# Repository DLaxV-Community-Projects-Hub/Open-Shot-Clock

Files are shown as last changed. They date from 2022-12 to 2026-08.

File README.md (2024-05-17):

theme

# Open Shot Clock

Open Shot Clock is an Open Source and DIY Project aiming to minimize the barriers of entry for shot-clock-aided sports like Boxlacrosse and Sixes and maximizing the pure sports experience to an affordable price.

## Details

- 10" super bright LED digits (in color of your choice)
- indoor and outdoor usage
    - impact and water resistant portable design
    - LED brightness adjustable to your needs
- wireless and cable connection
- 12V input supply (portable battery or mains operation by AC-DC power supply)
- handheld controller
- wifi connection to smartphone
    - control option
    - settings change
    - firmware updates
- external horn for each display
- tripod stands ~2 meter height
- tested under competition conditions

The price tag is around 1000€ for materials and accessories. Depending on which design and battery options you choose, it might cost more.

For more information have a look at our [wiki](https://github.com/DLaxV-Community-Projects-Hub/Open-Shot-Clock/wiki/Open-Shot-Clock-Wiki) or this [blog](https://devdrik.de/blog/) made by [@devdrik](https://github.com/devdrik).

## The Open Shot Clock in Action

To see the Open Shot Clock in action check out the following recordings of Lacrosse high lights in Germany:

- [Men´s European Box Lacrosse Championship 2022 - Final: England vs. Germany](https://sportdeutschland.tv/germanylacrosse/european-box-lacrosse-championship-final-england-vs-germany) (face off at 0:07:20)
- [Women´s German Indoor Championchip 2023 - Final: HLC Rot-Weiss München vs. HTHC Hamburg A](https://sportdeutschland.tv/germanylacrosse/deutsche-indoor-lacrosse-meisterschaft-2023-finale) (draw at 0:07:35)
- [Men´s German Box Lacrosse Championchip 2023- Final: SG Süd vs. SC Frankfurt 1880](https://sportdeutschland.tv/germanylacrosse/deutsche-box-lacrosse-meisterschaft-2023-finale) (face off at 0:10:15)
- [Women´s German Indoor Championchip 2022 - Final: HLC Rot-Weiss München vs. HTHC Hamburg A](https://sportdeutschland.tv/germanylacrosse/finale-lacrosse-damen-indoor-meisterschaft-2022) (draw at 0:09:20)
- [Men´s German Box Lacrosse Championchip 2022- Final: Spreewölfe Berlin vs. KKHT SW Köln](https://sportdeutschland.tv/germanylacrosse/deutsche-meisterschaften-box-lacrosse-2022-spreewoelfe-berlin-vs-kkht-sw-koeln) (starting at Part 2)

## What´s Included Here

- Design Documentation for Open Shot Clock Displays and Controller
    - CAD and PCB designs
    - 3d printing files
    - DIY Building Instructions Manual (german)
    - BOM for Displays, Controller and accessories (german)
    - User Manual (german)
    - Source Code to run Displays and Controller
- Project Wiki (work in progress)

## Usage

To build your own Open Shot Clock you can find all documents/information in the [documentation](documentation/) folder.

### Getting All the Parts Needed

Please go through the BOM to make sure you have all parts needed available. In the BOM we have included recommendation links, where we recently purchased the parts. Be aware that you can choose from different design features which you have to cover in your purchases. The developement is stil ongoing so some design features are not yet tested or even sufficiently developed.

In the design 3d printing is requried. Make sure you print the necessary parts before starting to build or let them print by a printing service. Make sure the parts are printed with a heat and impact resistant 3d printing material. You can find recommended materials in the BOM.

For the PCBs you can use the design files to order them at a PCB manufacturer like [PCBWay](https://www.pcbway.com/) or you can get in touch with us, there are still some prototyping PCBs left of the current version. In the near future the PCB design has to be adapted to the new Heltec Lora 32 version 3.0. For now the new version is supported through a workaround. For more information check this [blog artical](https://devdrik.de/open-shot-clock-hannover/) from [@devdrik](https://github.com/devdrik).

### List of Optional Design Features:

- Displays - 19 mm thick highly machined base plate or 8 mm thick easy to build base plate
  - 19 mm makes a more stable design and is tested well
  - 8 mm base plate is much easier to build with less special machinery, but it´s not tested yet (there might be clashes with electronic parts inside the case)

- Displays - Temperature Managment (up to now we don´t know if a temperature management is necessary, to find out we integrated a temp sensor socket on the display pcbs, tests are still in planning)

  - No Cooling
  - Fan grids on the back for passiv cooling (default)
  - Active Fan with fan grids on the back (fan can be installed behind one fan grid and operated by one mosfet output, this feature is not yet included in the sourc code)

- Displays - Batteries (you can find different battery options in the BOM from which you can choose)
- Accessories - you can find different accessory options in the BOM from which you can choose
- Displays - Type-Plate customization (for having your own type-plate text you can get in touch with us, we can change the text for you)
- to be continued

### Assembling

When you have all parts available please follow the DIY Building Instructions Manual for assembling your Open Shot Clocks. Some parts like the base-, front- and back-plates or the aliminium extursion profiles need to be modified before they can be assembled. You can do the needed modification by using the drawings of these parts or you can get in touch with us, there are still some back plates left in our stock. In this [youtube playlist](https://www.youtube.com/watch?v=pQqHoa6__Ms&list=PLql27Iz3RF6tFwROZiCufJEf_9jadfyL8) you can see videos of [@devdrik](https://github.com/devdrik) performing the assembing process of an Open Shot Clock. In the future the playlist will be extended to cover all parts of the assembling process.

#### Heltec WiFi LoRa V2/V3

The V2 module is hard to get at the moment, so we added support for the new V3 version of the module, that is easy to source. To use V3 with PCBs designed for V2, you need to rewire some connections. So make sure not to use a V3 on a V2 PCB without modification!

What to do to use a V3 on a Display PCB v0.2:
- Do not connect GPIO21 and GPIO48 of the V3 to the display PCB
- Connect GPIO38 to the display PCB where GPIO21 would be
- Connect GPIO39 to the display PCB where GPIO48 would be
- In [config.h](code/display/include/config.h) set ```DISPLAY_PCB_VERSION V0_2_HACK```

v3 Mod pins

What to do to use a V3 on a PCB for V2 (controller):
- Button BUTTON_PIN_B can not be used anymore
- Add pull-ups to all buttons (to be tested)

##### 5V Hack

Some Mosfet modules do not work with 3.3V on gate. To fix this on a v0.2 shotclock display PCB, we can disconnect the 3V3 pins from the of the heltec module and connect the corresponding pins on the display PCB to 5V of the heltec module.
This will bring all 3V3 on the display PCB to 5V, so be careful if you use a temperature sensor!

5V Mod pins

### How to Set Up the Firmware

You can find the source code for the controller and the displays in the code folder. Please just copy this repo to your VS Code with Plaformio extension and open both as projects. Fill in your preferred wifi credentials for setting up local device wifi networks to change settings. It is recommended to use different credentials for the controller and the displays to make sure you access the right devices settings.
Make sure to select the environment that fits the board you are using.

- flash controller
  - SPIFFS
  - source code
- flash displays
  - source code

## What´s Left to Do

- Tackle issues
- Build up Wiki with design insights, project history and roadmap
- Source code refactoring
- Design and test mdf display case as cost reduction opportunity
- pcb design to be ported to another open source platform and integration of heltc lora 32 v3.0 support
- Support first builders and gather feedback
- Offer english version of documents (if sufficiently demanded)
- to be continued

## How to Contribute

Feel free to customize your Open Shot Clock to your needs. For this purpose you can find the design files in the cad and pcb folders and the source code in the code folder. If you have ideas how to improve the Open Shot Clock and you need support for the integration or you want to share the benefits with the community please get in touch with us.

## Acknowledgement

Many thanks to [Ulf](https://github.com/ulf) for some initial inspiration in the approach to develop a LED shot clock. If you are looking out for a minimal and cheap setup for small indoor fields without obstacles have a look to [Ulf´s basketball shot clock tutotial](http://shotclock.de/)! With minor changes to the app it is possible to start with 30 seconds on the clock for lacrosse instead of 24 as for basketball. 

## Authors

- [@ChangeD20](https://github.com/ChangeD20)
- [@devdrik](https://github.com/devdrik)

## Contact

github@dlaxv.de

## License

[CERN OHL v2 Permissive](https://choosealicense.com/licenses/cern-ohl-p-2.0/)

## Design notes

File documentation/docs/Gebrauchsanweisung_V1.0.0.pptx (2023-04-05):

## Open Shot Clock

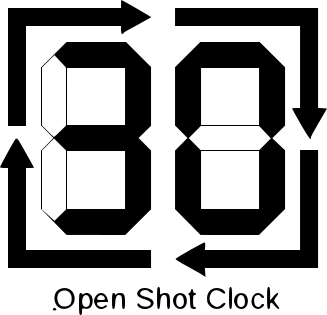
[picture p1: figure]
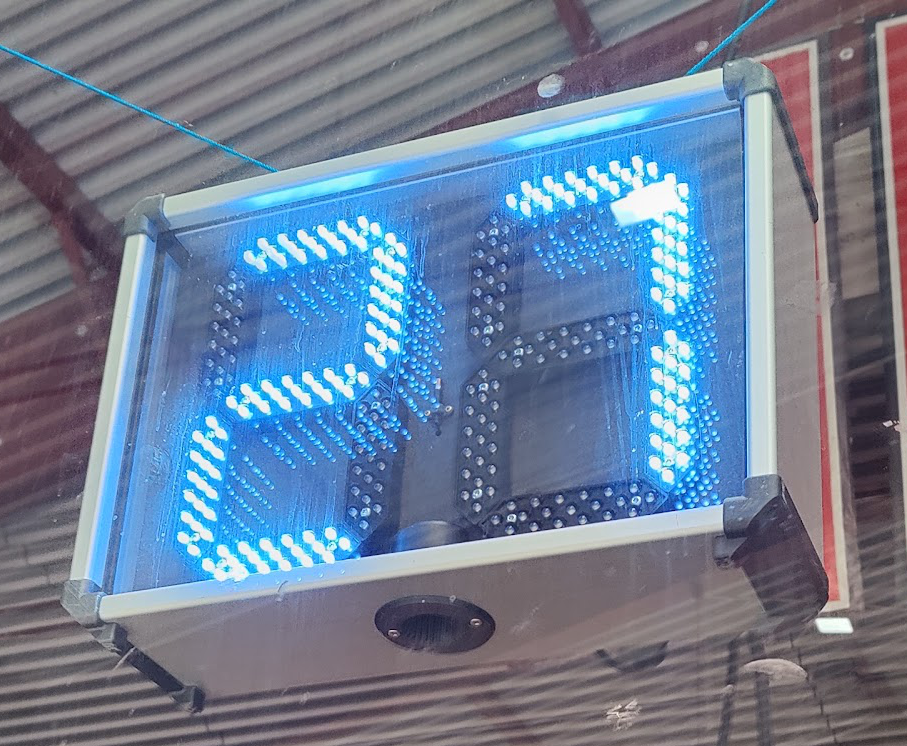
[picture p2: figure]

Gebrauchsanweisung

Haftungsausschluss:
Diese Anleitung beschreibt lediglich das Vorgehen, das wir (die Autoren) nach bestem Wissen und Gewissen wählen würden, um eine “Open Shot Clock” zu betreiben. Jegliche Haftung unsererseits ist ausgeschlossen. Der Bau und Betrieb einer “Open Shot Clock” oder einer abgeleiteten Version basiert immer auf eigenem Risiko und sollte von fachkundigen Personen durchgeführt werden.

## Inhalt

- Aufbau
  - Aufbau Displays
    - Stative oder Boden
    - Hinter Polycarbonat-Scheibe oder an Ballfangnetze
    - Anschluss Stromversorgung am Display
    - Akkus und Netzteil
    - Anschluss Horn am Display
  - Verbindungsübersichten
    - Funk Übersicht
    - Kabel Übersicht
    - Kabel Anschluss
- Bedienung Controller
- Einstellungen (tbd)

## Aufbau Displays - Stativ oder Boden

Auf Stativ oder auf dem Boden aufstellen
Stativ-Aufstell-Anweisungen beachten!!

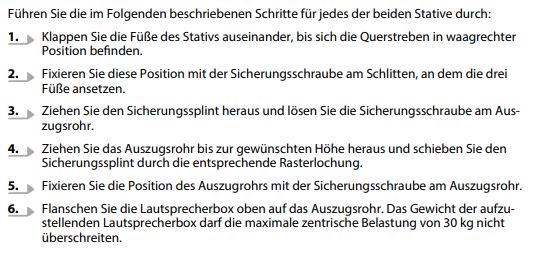
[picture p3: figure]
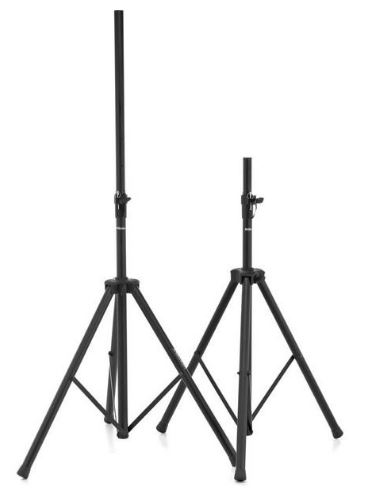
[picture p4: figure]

Bei starkem Wind keine Stative verwenden, Kippgefahr!!!

## Aufbau Displays - Hinter Polycarbonat-Scheibe oder an Ballfangnetz

Hinter Polycarbonat-Scheibe der Bande an den Streben aufhängen

Hinter Polycarbonat-Scheibe der Bande an der Scheibe mit Haken aufhängen

Vor oder hinter Ballfangnetz mit Haken aufhängen

Ösen für Haken/ Schnüre

Bei Montage über Durchgängen oder dem Spielfeld zusätzlich gegen Absturz sichern!!!

## Anschluss Stromversorgung am Display

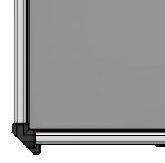
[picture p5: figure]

DATA IN

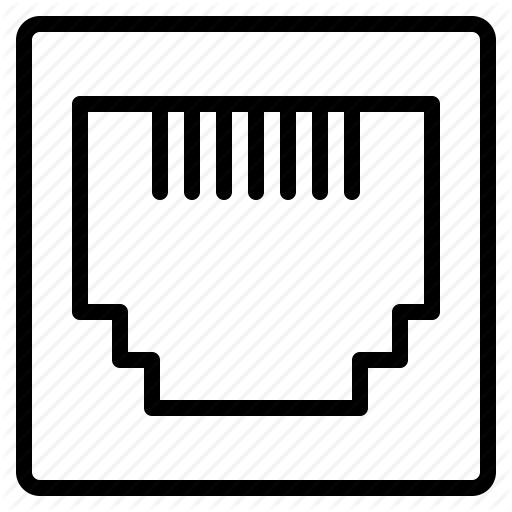
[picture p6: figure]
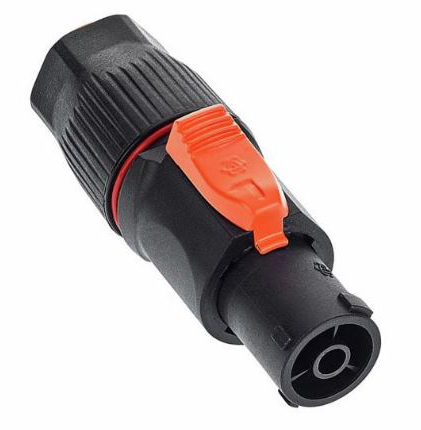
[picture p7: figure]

HORN OUT 12 V

DC IN 12V

Akku
oder
Netzteil

Display von Hinten

NUR 12V!!

## Akku - Fox Halo Power Pack 96k mAh

307,2 Wh

12V Ausgänge für Shot Clock Display

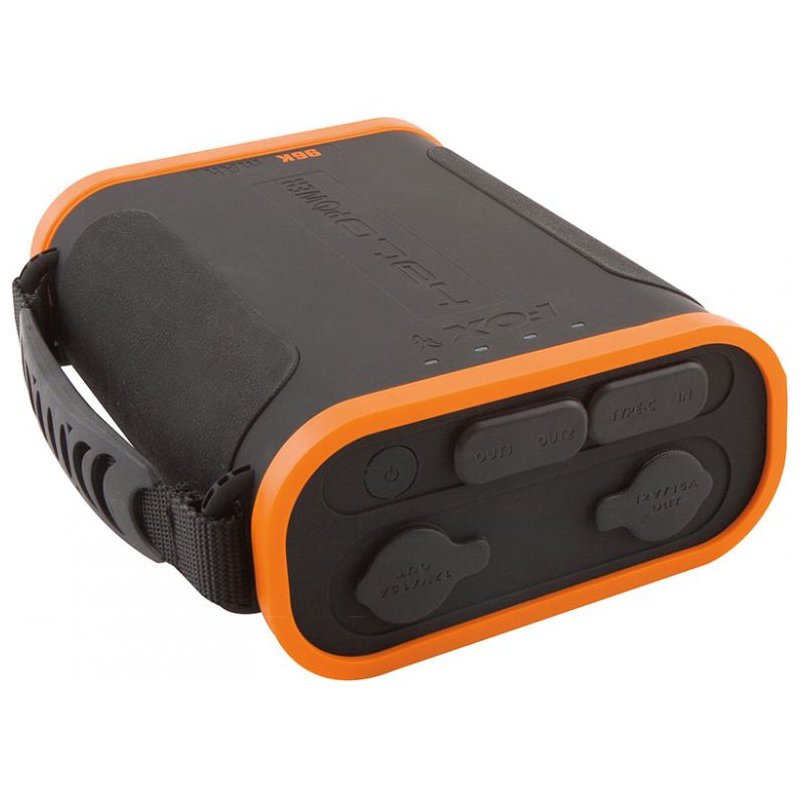
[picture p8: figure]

Akku laden

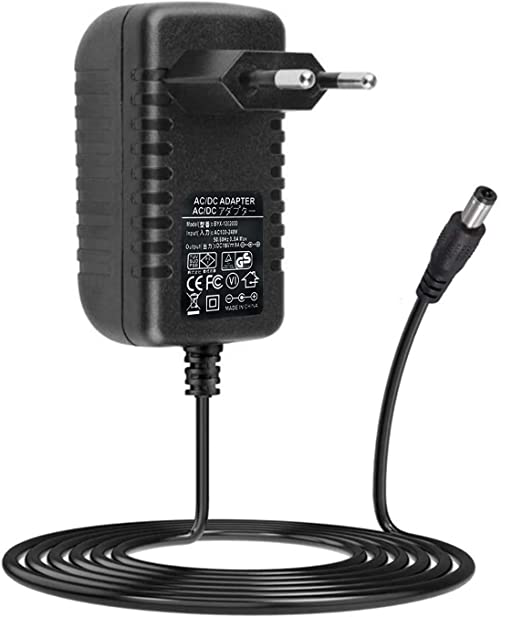
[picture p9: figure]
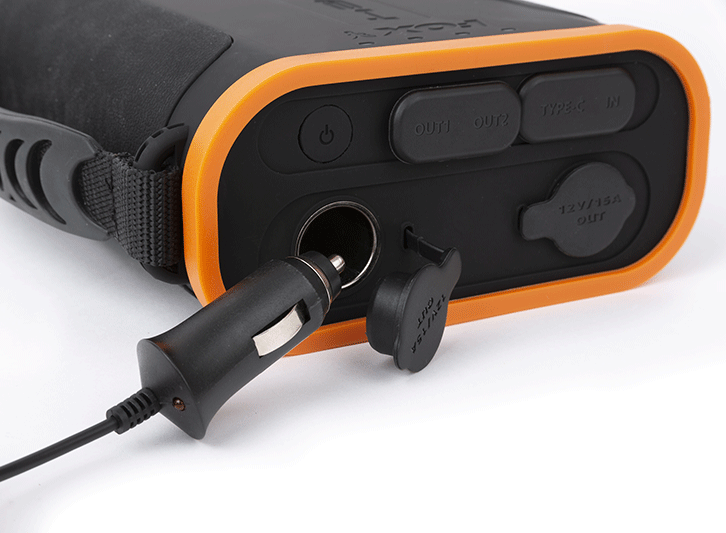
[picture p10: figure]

Bilder

VOR WASSER SCHÜTZEN!!!

KEIN PARALLELES LADEN!!!

Hier

vom Schließen der Tasche mit Kabel

## Akku - TotalCool TotalPower 144

144 Wh

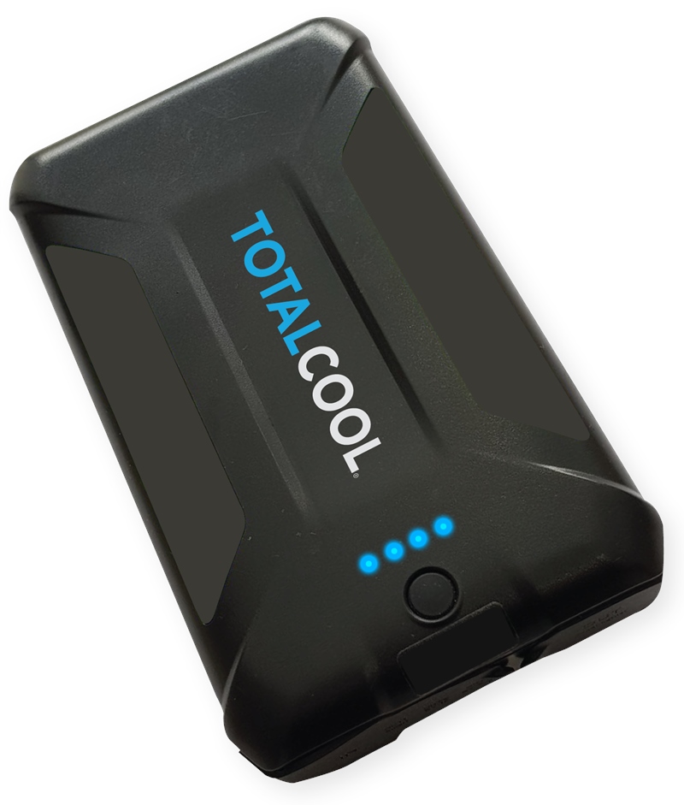
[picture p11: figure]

12V Ausgang für Shot Clock Display

Akku laden

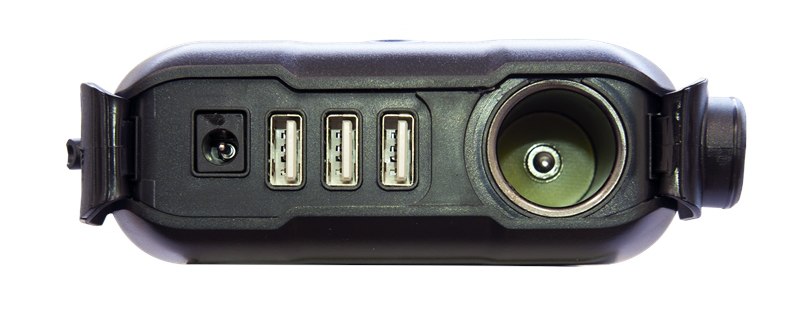
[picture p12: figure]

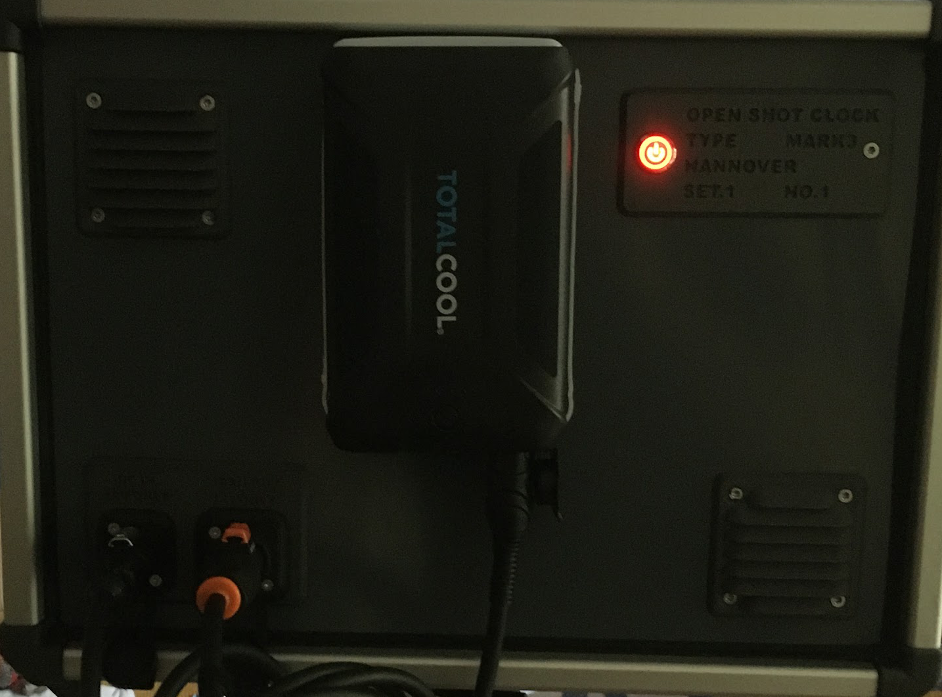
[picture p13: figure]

Gehäuse Wasserdicht, darum Akku mit Ein-/Ausgängen nach unten hinten an der Display Rückwand befestigen

KEIN PARALLELES LADEN UND NUTZEN!!!

## Netzteil 12V >5A

Netzstecker

Gefahr für Stromschlag durch Netzspannung
NUR INDOOR VERWENDEN!!

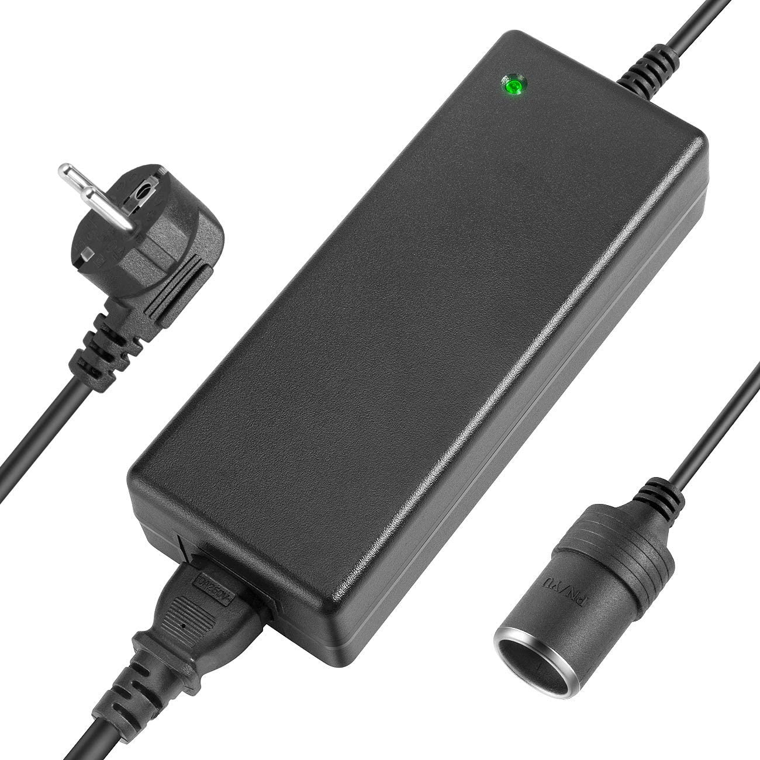
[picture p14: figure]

12V Ausgang für Shot Clock Display

## Anschluss Horn am Display

Horn Befestigung am Stativ

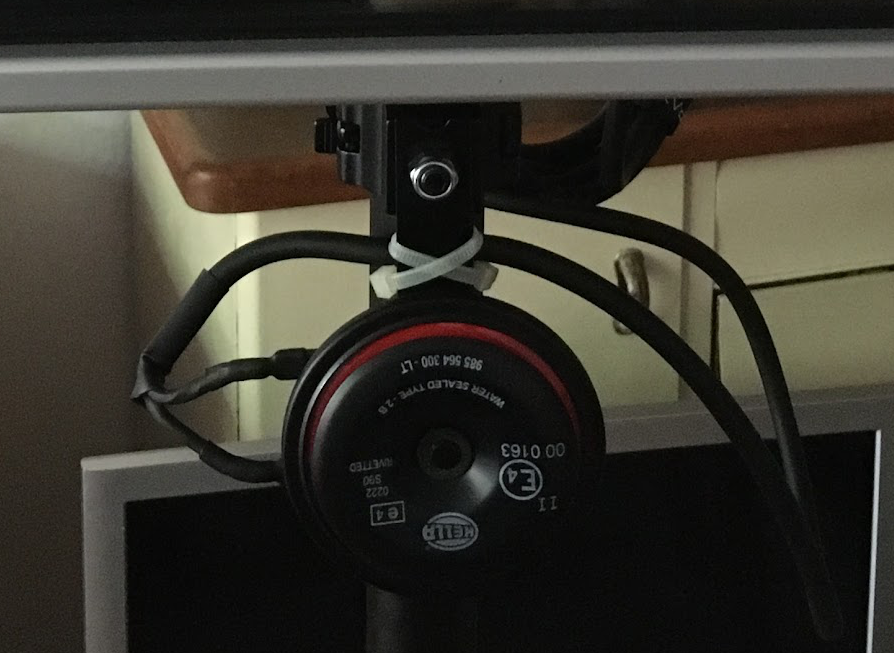
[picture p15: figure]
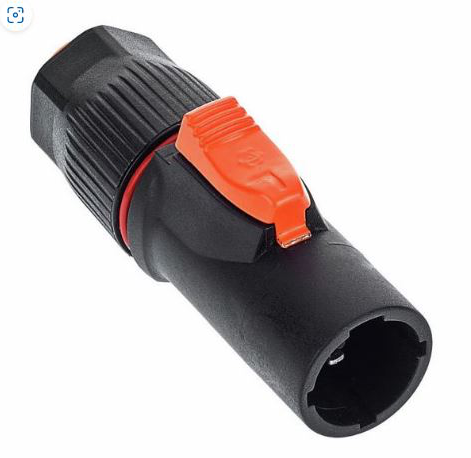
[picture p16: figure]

DATA IN

HORN OUT 12 V

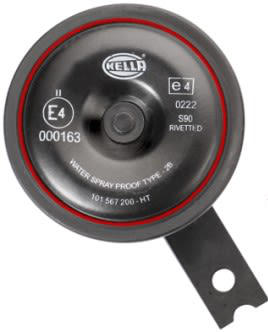
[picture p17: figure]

DC IN 12V

12V
Horn

Display von Hinten

## Aufbau - Funk Übersicht

Clock 1

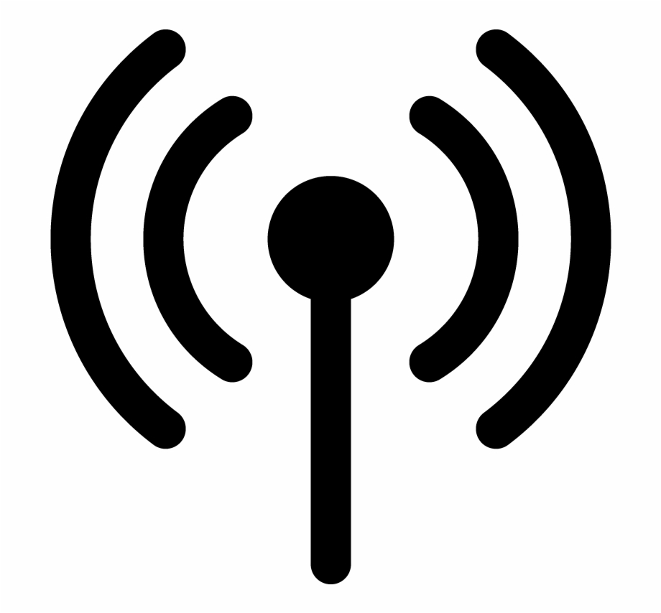
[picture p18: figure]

Clock 2

Clock 3

(optional, z.B. für Streaming)

Controller und alle Clocks müssen auf dem selben Kanal eingestellt sein (siehe Einstellungen)

Reichweite limitiert, Zuverlässigkeit eingeschränkt durch z.B. andere Funksender, Verbesserung des Empfangs durch:
Hindernisse vermeiden/Clocks über Kopfhöhe aufstellen

i

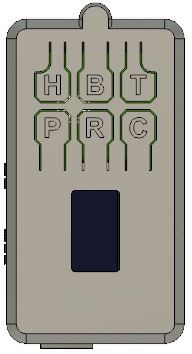
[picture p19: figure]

i

Controller

## Aufbau - Kabel - Übersicht

Clock 1

Clock 2

Clock 3

(optional, z.B. für Streaming)

Kabel-Verteilung

Den Controller niemals direkt an die Clocks anschließen, Kurzschlussgefahr!!!

Controller

## Aufbau - Kabel - Anschluss

Controller

Kabel-Verteilung

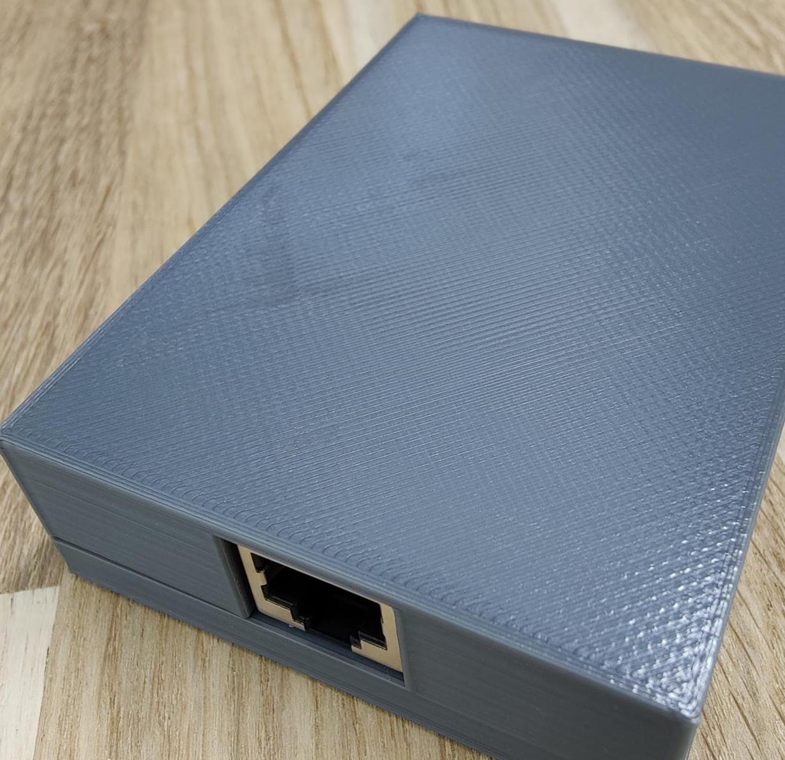
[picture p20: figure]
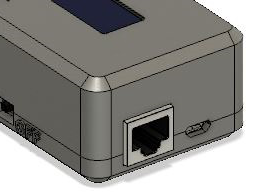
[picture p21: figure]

Anschluss mit Ethernet-Kabel

## Aufbau - Kabel - Anschluss

Kabel-Verteilung

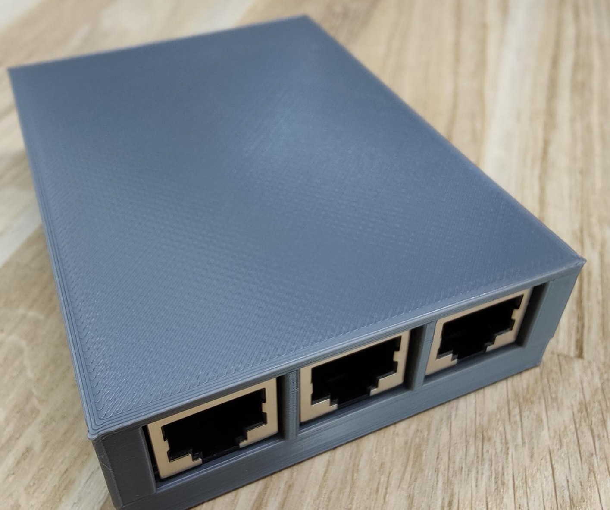
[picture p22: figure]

DATA IN

HORN OUT 12 V

1

Anschluss mit Ethernet-Kabel

2

3

DC IN 12V

Display von Hinten

## Bedienung Controller

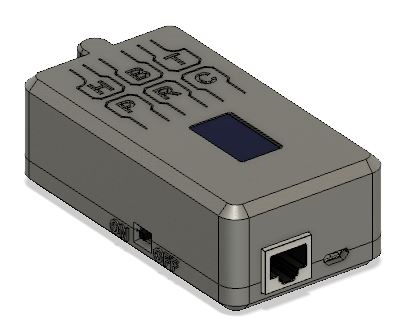
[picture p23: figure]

Kabel-Verbindung zum Verteiler

“T” Time Out
(autom. go back)

“B” Break
(Quarter / Halftime
- mehrfach drücken für Auswahl, autom. go back)

“H” Horn

Ein-/Aus-
schallter

Laden
5V Micro-USB

“C” Cancel
(Reset und Stop)

“R” Reset
(Reset und Start)

“P” Play/Pause

Controller Display

Parallels Laden des Controllers empfohlen bei voraussichtlich längerer Nutzung

i

## Einstellungen

TBD after refactoring of code

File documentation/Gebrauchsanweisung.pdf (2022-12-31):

Version 1.0

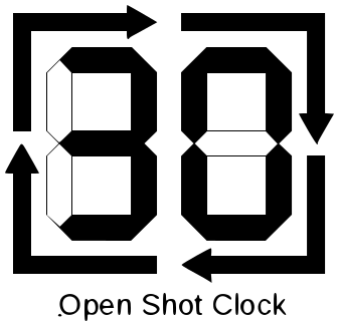
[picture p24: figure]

# Open Shot Clock

# Gebrauchsanweisung

Haftungsausschluss:
Diese Anleitung beschreibt lediglich das Vorgehen, das wir (die Autoren) nach bestem Wissen und Gewissen wählen würden, um eine “Open Shot Clock” zu betreiben. Jegliche Haftung unsererseits ist ausgeschlossen. Der Bau und Betrieb einer “Open Shot Clock” oder einer abgeleiteten Version basiert immer auf eigenem Risiko und sollte von fachkundigen Personen durchgeführt werden.

# Inhalt

## - Aufbau

- Aufbau Displays
■ | Stative oder Boden
■ | Hinter Polycarbonat-Scheibe oder an Ballfangnetze
■ | Anschluss Stromversorgung am Display
■ | Akkus und Netzteil
■ | Anschluss Horn am Display
- Verbindungsübersichten
■ | Funk Übersicht
■ | Kabel Übersicht
■ | Kabel Anschluss

## - Bedienung Controller - Einstellungen (tbd)

# Aufbau Displays - Stativ oder Boden


Auf Stativ oder auf dem Boden aufstellen

Stativ-Aufstell-Anweisungen beachten!!

Bei starkem Wind
keine Stative
verwenden,
Kippgefahr!!!

# Aufbau Displays - Hinter Polycarbonat-Scheibe oder an Ballfangnetz

Hinter Polycarbonat-Scheibe der Bande an den Streben aufhängen; Hinter Polycarbonat-Scheibe der Bande an der Scheibe mit Haken aufhängen; Vor oder hinter Ballfangnetz mit Haken aufhängen; Ösen für Haken/; Spielfeld zusätzlich gegen Absturz sichern!!!

Schnüre Bei Montage über Durchgängen oder dem

# Anschluss Stromversorgung am Display

HORN OUT 12 V; DATA IN; Akku; oder; NUR 12V!!; Netzteil

Display von Hinten

# Akku - Fox Halo Power Pack 96k mAh


Akku laden

12V Ausgänge für
Shot Clock Display

VOR WASSER SCHÜTZEN!!!; Hier; Bilder; KEIN PARALLELES LADEN!!!

vom
Schließen
der Tasche
mit Kabel

307,2 Wh


# Akku - TotalCool TotalPower 144 144 Wh


Akku laden

12V Ausgang für
Shot Clock Display

Gehäuse Wasserdicht, darum Akku mit Ein-/Ausgängen nach unten hinten an der Display Rückwand befestigen; KEIN PARALLELES LADEN UND NUTZEN!!!

# Netzteil 12V >5A

Gefahr für Stromschlag durch Netzspannung; NUR INDOOR VERWENDEN!!; Netzstecker; 12V Ausgang für Shot Clock Display

# Anschluss Horn am Display

HORN OUT 12 V; DATA IN; 12V Horn; Horn Befestigung am Stativ

Display von Hinten

Aufbau - Funk Übersicht; Clock 1; Clock 2; Clock 3; (optional, z.B. für Streaming); Controller; Reichweite limitiert, Zuverlässigkeit eingeschränkt durch z.B. andere Funksender, Verbesserung des Empfangs durch: Hindernisse vermeiden/Clocks über Kopfhöhe aufstellen; Controller und alle Clocks müssen auf dem selben Kanal eingestellt sein (siehe Einstellungen)

Aufbau - Kabel - Übersicht; Clock 1; Clock 2; Clock 3; (optional, z.B. für Streaming); Kabel-Verteilung; Controller; Den Controller niemals direkt an die Clocks anschließen, Kurzschlussgefahr!!!

# Aufbau - Kabel - Anschluss


Controller

Anschluss mit Ethernet-Kabel


Kabel-Verteilung

# Aufbau - Kabel - Anschluss

HORN OUT 12 V; DATA IN; Kabel-Verteilung

Anschluss mit Ethernet-Kabel

Display von Hinten

Bedienung Controller; Ein-/Aus- schallter; Laden 5V Micro-USB Kabel-Verbindung; zum Verteiler; Controller Display; “P” Play/Pause; “R” Reset (Reset und Start); “C” Cancel (Reset und Stop); “H” Horn; “B” Break (Quarter / Halftime - mehrfach drücken für Auswahl, autom. go back); “T” Time Out (autom. go back); Parallels Laden des Controllers empfohlen bei voraussichtlich längerer Nutzung

# Einstellungen

# TBD after refactoring of code

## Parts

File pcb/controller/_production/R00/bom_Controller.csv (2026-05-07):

# | Reference | Value | Qty | Footprint | Description | DNP
1 | BT1 | Battery_Cell | 1 | Battery:BatteryHolder_Keystone_1042_1x18650 | Single-cell battery
2 | C1,C2,C3,C4,C5,C6,C7,C8,C9,C10,C11,C12,C18,C22,C23,C26 | 100n | 16 | Capacitor_SMD:C_0402_1005Metric | Unpolarized capacitor
3 | C13,C16,C24 | 1u | 3 | Capacitor_SMD:C_0805_2012Metric | Unpolarized capacitor
4 | C14,C19 | 1u | 2 | Capacitor_SMD:C_0603_1608Metric | Unpolarized capacitor
5 | C15 | 2u2 | 1 | Capacitor_SMD:C_0603_1608Metric | Unpolarized capacitor
6 | C17,C21 | 100u | 2 | Capacitor_SMD:CP_Elec_8x10 | Polarized capacitor
7 | C20 | 1n | 1 | Capacitor_SMD:C_0402_1005Metric | Unpolarized capacitor
8 | C25,C27,C29,C30,C31 | 10u | 5 | Capacitor_SMD:C_0603_1608Metric | Unpolarized capacitor
9 | D1,D2,D5,D6,D9,D10,D11 | LED | 7 | LED_SMD:LED_0603_1608Metric | Light emitting diode
10 | D3,D4 | SMAJ24A | 2 | Diode_SMD:D_SMA | 400W unidirectional Transient Voltage Suppressor, 24.0Vr, SMA(DO-214AC)
11 | F1 | 2.6A | 1 | Fuse:Fuse_2920_7451Metric | Resettable fuse, polymeric positive temperature coefficient
12 | J1,J4 | Term 3.5mm | 2 | Connector_Phoenix_MC:PhoenixContact_MC_1,5_2-G-3.5_1x02_P3.50mm_Horizontal | Generic screw terminal, single row, 01x02, script generated (kicad-library-utils/schlib/autogen/connector/)
13 | J2,J3 | RJ45 | 2 | Connector_RJ:RJ45_Amphenol_RJHSE5380 | RJ connector, 8P8C (8 positions 8 connected)
14 | J5 | OLED 0.96" (I2C) | 1 | Connector_PinSocket_2.54mm:PinSocket_1x04_P2.54mm_Vertical | Generic connector, single row, 01x04, script generated (kicad-library-utils/schlib/autogen/connector/)
15 | J6,J7,J8,J9,J10,J11,J12,J13 | JST XH | 8 | Connector_Molex:Molex_PicoBlade_53048-0210_1x02_P1.25mm_Horizontal | Generic connector, single row, 01x02, script generated (kicad-library-utils/schlib/autogen/connector/)
16 | L1 | 10uH | 1 | Inductor_SMD:L_Bourns_SRP1050WA | Inductor
17 | L2,L3 | 2.2uH | 2 | Inductor_SMD:L_1008_2520Metric | Inductor
18 | P1,P2 | USB_C_Plug_USB2.0 | 2 | Connector_USB:USB_C_Receptacle_G-Switch_GT-USB-7010ASV | USB 2.0-only Type-C Plug connector
19 | Q1 | 20N06 | 1 | Package_SON:VSON-8_3.3x3.3mm_P0.65mm_NexFET | N-MOSFET transistor, source/gate/drain
20 | Q2 | SI2301 | 1 | Package_TO_SOT_SMD:SOT-23 | P-MOSFET transistor, gate/source/drain
21 | R1,R2,R4,R7,R17,R19,R26,R27,R29,R30,R41,R43,R44 | 1k | 13 | Resistor_SMD:R_0402_1005Metric | Resistor
22 | R5,R6 | 4k3 | 2 | Resistor_SMD:R_0402_1005Metric | Resistor
23 | R8,R20,R21,R32 | 200k | 4 | Resistor_SMD:R_0402_1005Metric | Resistor
24 | R9 | 120R | 1 | Resistor_SMD:R_0805_2012Metric | Resistor
25 | R10,R13,R28 | 0R | 3 | Resistor_SMD:R_0805_2012Metric | Resistor
26 | R11,R14,R15,R16,R33,R38,R40 | 10k | 7 | Resistor_SMD:R_0402_1005Metric | Resistor
27 | R12 | 2R2 | 1 | Resistor_SMD:R_0402_1005Metric | Resistor
28 | R18 | 82k | 1 | Resistor_SMD:R_0603_1608Metric | Resistor
29 | R22 | 4k3 | 1 | Resistor_SMD:R_0603_1608Metric | Resistor
30 | R23,R25 | 560R | 2 | Resistor_SMD:R_0402_1005Metric | Resistor
31 | R24,R34 | 0R | 2 | Resistor_SMD:R_0402_1005Metric | Resistor
32 | R31,R39 | 22k | 2 | Resistor_SMD:R_0402_1005Metric | Resistor
33 | R35 | 47k | 1 | Resistor_SMD:R_0402_1005Metric | Resistor
34 | R45,R46 | 470R | 2 | Resistor_SMD:R_0402_1005Metric | Resistor
35 | SW1,SW2,SW3,SW4,SW5,SW6,SW7 | SW_4x3mm | 7 | RVNSPRK_Switch:SW_Push_4x3mm | Push button switch, generic, two pins
36 | SW8 | SW_SPDT_312 | 1 | Button_Switch_THT:SW_CuK_OS102011MA1QN1_SPDT_Angled | Switch, single pole double throw
37 | TH1 | NTC | 1 | Resistor_SMD:R_0402_1005Metric | Temperature dependent resistor, negative temperature coefficient
38 | U*1 | BQ25606 | 1 | Package_DFN_QFN:VQFN-24-1EP_4x4mm_P0.5mm_EP2.5x2.5mm_ThermalVias | Standalone 1-Cell 3.0-A Buck Battery Charger VQFN-24
39 | U1 | ESP32-S3-MINI-1 | 1 | Espressif:ESP32-S3-MINI-1U | Smallsized module supporting 2.4 GHz WiFi (802.11 b/g/n) and Bluetooth ® 5 (LE) Built around ESP32S3 series of SoCs, Xtensa ® dualcore 32bit LX7 microprocessor Flash up to 8 MB, optional 2 MB PSRAM in chip package 39 GPIOs, rich set of peripherals Onboard PCB antenna or external antenna connector
40 | U2 | SP3485EN | 1 | Package_SO:SOIC-8_3.9x4.9mm_P1.27mm | Industrial 3.3V Low Power Half-Duplex RS-485 Transceiver 10Mbps, SOIC-8
41 | U3 | E220-400M22S | 1 | RVNSPRK_Modules:E220-400M22S
42 | U4 | SIC438BED-T1-GE3 | 1 | Package_DFN_QFN:Vishay_PowerPAK_MLP44-24L_ThermalVias | DC/DC Converter 24V 8A
43 | U5 | TPS259474x | 1 | RVNSPRK_Packages:RPW0010A_VQFN-HR-10 | 24V eFuse Protection Switch (VQFN-10)
44 | U6 | TPS629206 | 1 | Package_TO_SOT_SMD:SOT-583-8 | 3-V to 17-V, 0.6A, Low IQ Buck Converter with DCS-Control, SOT583-8

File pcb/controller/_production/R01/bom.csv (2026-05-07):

Designator | Footprint | Quantity | Value | LCSC Part #
BT401 | BatteryHolder_SMD_1x18650 | 1 | 18650 | C2988620
C101, C102, C201, C202, C203, C204, C205, C206, C207, C208, C209, C301, C401, C402, C408, C416, C417, C420, C426 | 0402 | 19 | 100n | C307331
C302, C419, C421, C422, C423, C424, C425 | 0603 | 7 | 10u | C19702
C403, C404, C418 | 0603 | 3 | 1u | C15849
C405 | 0402 | 1 | 10n | C15195
C406 | 0402 | 1 | 1n | C1523
C407, C414, C415 | CP_Elec_8x10 | 3 | 150u | C2898894
C409, C410, C413 | 1206 | 3 | 10u | C13585
C411 | 0402 | 1 | 1u | C52923
C412 | 0603 | 1 | 2u2 | C23630
D101, D102, D202, D402, D403, D406, D407, D408 | 0603 | 8 | LED | C2286
D201, D404, D405 | D_SOD-323 | 3 | 1N5819WS | C191023
D203 | D_SMA | 1 | SS54 | C22452
D401 | D_SMA | 1 | SMAJ24CA | C20883150
H101, H102, H103, H104 | MountingHole_3.2mm_M3 | 4 | M3
J102, J210 | PhoenixContact_MC_1,5_2-G-3.5_1x02_P3.50mm_Horizontal | 2 | Term 3.5mm | C409115
J103, J104 | RJ45_Amphenol_RJHSE5380 | 2 | RJ45 | C19078599
J201 | PinSocket_1x04_P2.54mm_Vertical_SMD_Pin1Left | 1 | OLED 0.96" (I2C) | C20071191
J202, J203, J204, J205, J206, J207, J208, J209 | Molex_PicoBlade_53048-0210_1x02_P1.25mm_Horizontal | 8 | Picoblade | C2845535
L401 | L_Bourns_SRP1050WA | 1 | 6.8uH | C32712978
L402 | L_Changjiang_FNR4030S | 1 | 100uH | C7588681
L403 | 1008 | 1 | 2.2uH | C964122
P101 | USB_C_Receptacle_G-Switch_GT-USB-7010ASV | 1 | USB_C_Plug_USB2.0 | C2927039
Q201 | SOT-23 | 1 | SI2301 | C10487
Q202, Q401 | VSON-8_3.3x3.3mm_P0.65mm_NexFET | 2 | DOZ35N06 | C36499167
Q402, Q403, Q404 | SOT-23 | 3 | 2N7002 | C8545
R102, R103, R104, R107, R202, R410, R420, R421, R429, R439, R440, R446 | 0402 | 12 | 1k
R105, R106, R416, R419, R448 | 0402 | 5 | 4k3
R108, R436, R437, R445, R447 | 0402 | 5 | 10k
R201, R203, R205, R403, R404, R406, R407, R425, R444 | 0402 | 9 | 20k
R204, R413, R441, R442 | 0402 | 4 | 560R
R301 | 0805 | 1 | 120R
R402, R408 | 1206 | 2 | 0R
R405 | 0402 | 1 | 2R2
R409, R414, R415 | 0402 | 3 | 2k
R411 | 0402 | 1 | 82k
R412, R432, R449 | 0402 | 3 | 0R
R417, R418, R428, R430 | 0402 | 4 | 200k
R423, R424, R435 | 0603 | 3 | 0R
R427, R431 | 0402 | 2 | 130k
R433 | 0402 | 1 | 51k
R434 | 0402 | 1 | 13k
SW101, SW102, SW201, SW202, SW203, SW204, SW205, SW206, SW207, SW208 | SW_Push_4x3mm | 10 | SW_4x3mm | C18078117
SW401 | SW_CuK_OS102011MA1QN1_SPDT_Angled | 1 | SW_SPDT_312 | C431548
U101 | ESP32-S3-MINI-1U | 1 | ESP32-S3-MINI-1 | C2980299
U201 | SOIC-8_3.9x4.9mm_P1.27mm | 1 | LM358 | C7950
U301 | SOIC-8_3.9x4.9mm_P1.27mm | 1 | SP3485EN-L/TR | C8963
U302 | E220-400M22S | 1 | E220-400M22S | C2971737
U401 | Vishay_PowerPAK_MLP44-24L_ThermalVias | 1 | SIC438BED-T1-GE3 | C511430
U402 | RPW0010A_VQFN-HR-10 | 1 | TPS259474ARPW | C3662807
U403 | SOT-23-6 | 1 | LM74700 | C2941042
U404 | Texas_S-PVSON-N10_ThermalVias | 1 | LM5166DRCR | C481392
U405 | VQFN-24-1EP_4x4mm_P0.5mm_EP2.5x2.5mm_ThermalVias | 1 | BQ25616 | C2866447

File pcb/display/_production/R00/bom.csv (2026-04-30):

# | Reference | Value | Qty | Footprint | Description | DNP
1 | C1,C2,C3,C4,C6,C7,C8,C9,C12,C21,C26,C27 | 100n | 12 | Capacitor_SMD:C_0603_1608Metric | Unpolarized capacitor
2 | C13,C17 | 1u | 2 | Capacitor_SMD:C_0603_1608Metric | Unpolarized capacitor
3 | C14 | 1n | 1 | Capacitor_SMD:C_0603_1608Metric | Unpolarized capacitor
4 | C15,C20 | 100u | 2 | Capacitor_SMD:CP_Elec_8x10 | Polarized capacitor
5 | C16,C19,C22,C24 | 1u | 4 | Capacitor_SMD:C_0805_2012Metric | Unpolarized capacitor
6 | C18 | 2u2 | 1 | Capacitor_SMD:C_0603_1608Metric | Unpolarized capacitor
7 | C23,C25 | 10u | 2 | Capacitor_SMD:C_0805_2012Metric | Unpolarized capacitor
8 | D1,D2,D17 | SMAJ24A | 3 | Diode_SMD:D_SMA | 400W unidirectional Transient Voltage Suppressor, 24.0Vr, SMA(DO-214AC)
9 | D3,D4,D5,D6,D7,D8,D9,D10,D11,D12,D13,D14,D15,D16,D20,D21,D22,D23,D24,D25 | LED | 20 | LED_SMD:LED_0603_1608Metric | Light emitting diode
10 | D18,D19 | B5819W | 2 | Diode_SMD:D_SOD-123 | Schottky diode
11 | F1 | 2.6A | 1 | Fuse:Fuse_2920_7451Metric | Resettable fuse, polymeric positive temperature coefficient
12 | J1 | Screw Terminal 3.5mm | 1 | Connector_Phoenix_MC:PhoenixContact_MC_1,5_6-G-3.5_1x06_P3.50mm_Horizontal | Generic screw terminal, single row, 01x06, script generated (kicad-library-utils/schlib/autogen/connector/)
13 | J2 | RJ45 | 1 | Connector_RJ:RJ45_Amphenol_54602-x08_Horizontal | RJ connector, 8P8C (8 positions 8 connected)
14 | J4 | 01x08_Pin | 1 | Connector_PinHeader_2.54mm:PinHeader_1x08_P2.54mm_Vertical | Generic connector, single row, 01x08, script generated
15 | J5,J6 | Term 3.5mm | 2 | Connector_Phoenix_MC:PhoenixContact_MC_1,5_2-G-3.5_1x02_P3.50mm_Horizontal | Generic screw terminal, single row, 01x02, script generated (kicad-library-utils/schlib/autogen/connector/)
16 | J7,J8,J9,J10,J11,J12,J13,J14,J15,J16,J17,J18,J19,J20 | XH 2P | 14 | Connector_JST:JST_XH_B2B-XH-A_1x02_P2.50mm_Vertical | Generic connector, single row, 01x02, script generated (kicad-library-utils/schlib/autogen/connector/)
17 | L3 | 10uH | 1 | Inductor_SMD:L_Bourns_SRR1260 | Inductor
18 | L4 | 12uH | 1 | Inductor_SMD:L_Changjiang_FNR6045S | Inductor
19 | P1 | USB_C_Plug_USB2.0 | 1 | Connector_USB:USB_C_Receptacle_G-Switch_GT-USB-7010ASV | USB 2.0-only Type-C Plug connector
20 | Q1,Q2,Q3,Q4,Q5,Q6,Q7,Q8,Q9,Q10,Q11,Q12,Q13,Q14,Q15,Q16 | 20N06 | 16 | Package_SON:VSON-8_3.3x3.3mm_P0.65mm_NexFET | N-MOSFET transistor, source/gate/drain
21 | R1,R2,R7,R15,R17,R22,R26,R27,R35,R43 | 1k | 10 | Resistor_SMD:R_0603_1608Metric | Resistor
22 | R3,R36,R40 | 0R | 3 | Resistor_SMD:R_0805_2012Metric | Resistor
23 | R4 | 120R | 1 | Resistor_SMD:R_0805_2012Metric | Resistor
24 | R5,R24,R45 | 0R | 3 | Resistor_SMD:R_0603_1608Metric | Resistor
25 | R8,R9,R48,R49 | 0R | 4 | Resistor_SMD:R_0402_1005Metric | Resistor
26 | R10,R30,R46,R47 | 4k3 | 4 | Resistor_SMD:R_0603_1608Metric | Resistor
27 | R18,R19,R20,R21,R32,R34,R42 | 10k | 7 | Resistor_SMD:R_0603_1608Metric | Resistor
28 | R23 | 82k | 1 | Resistor_SMD:R_0603_1608Metric | Resistor
29 | R25,R39 | 560R | 2 | Resistor_SMD:R_0603_1608Metric | Resistor
30 | R28,R29 | 200k | 2 | Resistor_SMD:R_0603_1608Metric | Resistor
31 | R31,R33,R41 | 22k | 3 | Resistor_SMD:R_0603_1608Metric | Resistor
32 | R38 | 2R2 | 1 | Resistor_SMD:R_0603_1608Metric | Resistor
33 | RN9,RN10,RN11,RN12 | 3k3 | 4 | Resistor_SMD:R_Array_Convex_4x0603 | 4 resistor network, parallel topology
34 | SW1,SW2,SW3,SW4 | SW_4x3mm | 4 | RVNSPRK_Switch:SW_Push_4x3mm | Push button switch, generic, two pins
35 | U1 | TMP1075DSG | 1 | Package_SON:WSON-8-1EP_2x2mm_P0.5mm_EP0.9x1.6mm | I2C-bus digital temperature sensor and thermal watchdog, WSON-8
36 | U2 | ESP32-S3-MINI-1 | 1 | Espressif:ESP32-S3-MINI-1U | Smallsized module supporting 2.4 GHz WiFi (802.11 b/g/n) and Bluetooth ® 5 (LE) Built around ESP32S3 series of SoCs, Xtensa ® dualcore 32bit LX7 microprocessor Flash up to 8 MB, optional 2 MB PSRAM in chip package 39 GPIOs, rich set of peripherals Onboard PCB antenna or external antenna connector
37 | U4 | PCA9685BS | 1 | Package_DFN_QFN:QFN-28-1EP_6x6mm_P0.65mm_EP4.25x4.25mm | 16-channel 12-bit PWM Fm+ I2C-bus LED controller RGBA QFN
38 | U5 | SP3485EN | 1 | Package_SO:SOIC-8_3.9x4.9mm_P1.27mm | Industrial 3.3V Low Power Half-Duplex RS-485 Transceiver 10Mbps, SOIC-8
39 | U6 | AP2210 | 1 | Package_TO_SOT_SMD:SOT-23-3
40 | U8 | E220-400M22S | 1 | RVNSPRK_Modules:E220-400M22S
41 | U9 | SIC438BED-T1-GE3 | 1 | Package_DFN_QFN:Vishay_PowerPAK_MLP44-24L_ThermalVias | DC/DC Converter 24V 8A
42 | U10 | TPS259474x | 1 | RVNSPRK_Packages:RPW0010A_VQFN-HR-10 | 24V eFuse Protection Switch (VQFN-10)
43 | U11 | LV3842 | 1 | Package_TO_SOT_SMD:SOT-23-6 | DC/DC Converter 36V 0.6A

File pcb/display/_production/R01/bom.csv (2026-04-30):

Designator | Footprint | Quantity | Value | LCSC Part #
C101, C102, C103, C104, C105, C201, C301, C601, C613, C614, C617, C620, C621 | 0402 | 13 | 100n
C602, C603, C606, C615, C618 | 1206 | 5 | 10u
C604, C609, C622, C623 | 0603 | 4 | 1u
C605 | 0603 | 1 | 2u2
C607, C608, C612 | CP_Elec_8x10 | 3 | 150u
C610 | 0402 | 1 | 10n
C611 | 0402 | 1 | 1n
C616, C619 | 0603 | 2 | 10u
D101, D102, D201, D203, D401, D402, D403, D404, D405, D406, D407, D501, D502, D503, D504, D505, D506, D507, D605, D606, D607, D608 | 0603 | 22 | LED
D202, D204 | D_SMA | 2 | SS54
D601, D602 | D_SOD-323 | 2 | 1N5819WS
D603, D604 | D_SMA | 2 | SMAJ24CA
J101 | RJ45_Amphenol_RJHSE5380 | 1 | RJ45
J102 | PhoenixContact_MC_1,5_6-G-3.5_1x06_P3.50mm_Horizontal | 1 | Screw Terminal 3.5mm
J103 | PinHeader_1x08_P2.54mm_Vertical | 1 | 01x08_Pin
J201, J202 | PhoenixContact_MC_1,5_2-G-3.5_1x02_P3.50mm_Horizontal | 2 | Term 3.5mm
J401, J402, J403, J404, J405, J406, J407, J501, J502, J503, J504, J505, J506, J507 | JST_XH_B2B-XH-A_1x02_P2.50mm_Vertical | 14 | XH 2P
L601 | L_Bourns_SRP1050WA | 1 | 6.8uH
L602, L603 | L_Changjiang_FNR4030S | 2 | 33uH
P101 | USB_C_Receptacle_G-Switch_GT-USB-7010ASV | 1 | USB_C_Plug_USB2.0
Q101 | SOT-23 | 1 | 2N7002
Q201, Q202, Q401, Q402, Q403, Q404, Q405, Q406, Q407, Q501, Q502, Q503, Q504, Q505, Q506, Q507, Q601, Q602 | VSON-8_3.3x3.3mm_P0.65mm_NexFET | 18 | DOZ35N06
R101, R102, R104, R105, R106, R109, R609, R610, R618, R619, R629 | 0402 | 11 | 1k8
R107, R108, R203, R204, R401, R402, R403, R404, R405, R406, R407, R501, R502, R503, R504, R505, R506, R507, R612, R615, R628 | 0402 | 21 | 4k3
R110, R603, R604, R606, R607, R622, R626 | 0402 | 7 | 18k
R202, R602, R608 | 1206 | 3 | 0R
R301 | 0805 | 1 | 120R
R302, R620, R623 | 0603 | 3 | 0R
R605 | 0402 | 1 | 2R2
R611, R621, R624 | 0402 | 3 | 82k
R613, R614 | 0402 | 2 | 200k
R616 | 0402 | 1 | 0R
R617 | 0402 | 1 | 680R
R625, R627 | 0402 | 2 | 11k
SW101, SW102, SW103, SW104 | SW_Push_4x3mm | 4 | SW_4x3mm
U101 | WSON-8-1EP_2x2mm_P0.5mm_EP0.9x1.6mm | 1 | TMP1075DSGR
U102 | ESP32-S3-MINI-1U | 1 | ESP32-S3-MINI-1U-N8
U201 | QFN-28-1EP_6x6mm_P0.65mm_EP4.25x4.25mm | 1 | PCA9685BS
U301 | SOIC-8_3.9x4.9mm_P1.27mm | 1 | SP3485EN-L/TR
U302 | E220-400M22S | 1 | E220-400M22S
U601 | Vishay_PowerPAK_MLP44-24L_ThermalVias | 1 | SIC438BED-T1-GE3
U602 | RPW0010A_VQFN-HR-10 | 1 | TPS259474ARPWR
U603, U604 | SOT-23-6 | 2 | TPS54202DDC
U605, U606 | SOT-23-6 | 2 | LM74700

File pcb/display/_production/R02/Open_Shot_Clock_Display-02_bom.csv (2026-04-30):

Designator | Footprint | Quantity | Value | LCSC Part #
C1, C616, C619 | 0603 | 3 | 10u | C19702
C101, C102, C103, C105, C107, C108, C109, C113, C201, C301, C601, C613, C614, C617, C620, C621 | 0402 | 16 | 100n | C307331
C104, C106, C110, C4, C5 | 0402 | 5 | 1u | C52923
C111, C112 | 0402 | 2 | 1.8pF | C5186870
C2, C3 | 0402 | 2 | 12p | C76948
C602, C603, C606, C615, C618 | 1206 | 5 | 10u | C13585
C604, C609, C622, C623 | 0603 | 4 | 1u | C15849
C605 | 0603 | 1 | 2u2 | C23630
C607, C608, C612 | CP_Elec_8x10 | 3 | 220u | C5246542
C610 | 0402 | 1 | 10n | C15195
C611 | 0402 | 1 | 1n | C1523
D101, D102, D201, D203, D401, D402, D403, D404, D405, D406, D407, D501, D502, D503, D504, D505, D506, D507, D605, D606, D607, D608 | 0603 | 22 | LED | C2286
D202, D204 | D_SMA | 2 | SS54 | C22452
D601, D602 | D_SOD-323 | 2 | 1N5819WS | C191023
D603, D604 | D_SMA | 2 | SMAJ24CA | C20883150
FB1 | 0603 | 1 | 100R | C14709
J1, J401, J402, J403, J404, J405, J406, J407, J501, J502, J503, J504, J505, J506, J507 | JST_XH_B2B-XH-A_1x02_P2.50mm_Vertical | 15 | XH 2P | C158012
J101 | RJ45_Amphenol_RJHSE5380 | 1 | RJ45 | C19078599
J102 | PhoenixContact_MC_1,5_6-G-3.5_1x06_P3.50mm_Horizontal | 1 | Screw Terminal 3.5mm | C409119
J103 | PinHeader_1x08_P2.54mm_Vertical | 1 | 01x08_Pin | C6332201
J105 | U.FL_Hirose_U.FL-R-SMT-1_Vertical | 1 | U.FL | C88374
J201, J202 | PhoenixContact_MC_1,5_2-G-3.5_1x02_P3.50mm_Horizontal | 2 | Term 3.5mm | C409115
L1 | 0402 | 1 | 24nH | C167472
L101 | 0402 | 1 | 2.7nH | C963981
L601 | L_Bourns_SRP1050WA | 1 | 6.8uH | C32712978
L602, L603 | L_Changjiang_FNR4030S | 2 | 22uH | C206327
P101 | USB_C_Receptacle_G-Switch_GT-USB-7010ASV | 1 | USB_C_Plug_USB2.0 | C2927039
Q101 | SOT-23 | 1 | 2N7002 | C8545
Q201, Q202, Q401, Q402, Q403, Q404, Q405, Q406, Q407, Q501, Q502, Q503, Q504, Q505, Q506, Q507, Q601, Q602 | VSON-8_3.3x3.3mm_P0.65mm_Custom | 18 | DOZ35N06 | C36499167
R101, R102, R104, R105, R109, R609, R610, R618, R619, R629 | 0402 | 10 | 1k8
R106 | 0402 | 1 | 10k
R107, R108, R203, R204, R401, R402, R403, R404, R405, R406, R407, R501, R502, R503, R504, R505, R506, R507, R612, R615, R628 | 0402 | 21 | 4k3
R110, R603, R604, R606, R607, R622, R626 | 0402 | 7 | 18k
R2, R3 | 0402 | 2 | 22R
R202, R602, R608 | 1206 | 3 | 0R
R301 | 0805 | 1 | 120R
R302, R620, R623 | 0603 | 3 | 0R
R605 | 0402 | 1 | 2R2
R611, R621, R624 | 0402 | 3 | 82k
R613, R614 | 0402 | 2 | 200k
R616 | 0402 | 1 | 0R
R617 | 0402 | 1 | 680R
R625, R627 | 0402 | 2 | 11k
SW101, SW102, SW103, SW104 | SW_Push_4x3mm | 4 | SW_4x3mm | C18077679
U101 | WSON-8-1EP_2x2mm_P0.5mm_EP0.9x1.6mm | 1 | TMP1075DSGR | C2870250
U102 | QFN-56-1EP_7x7mm_P0.4mm_EP5.6x5.6mm | 1 | ESP32-S3FN8 | C2913196
U201 | QFN-28-1EP_6x6mm_P0.65mm_EP4.25x4.25mm | 1 | PCA9685BS | C5191634
U301 | SOIC-8_3.9x4.9mm_P1.27mm | 1 | SP3485EN-L/TR | C8963
U302 | E220-400M22S | 1 | E220-400M22S | C2971737
U601 | Vishay_PowerPAK_MLP44-24L_ThermalVias | 1 | SIC438BED-T1-GE3 | C511430
U602 | RPW0010A_VQFN-HR-10 | 1 | TPS259474ARPWR | C3662807
U603, U604 | SOT-23-6 | 2 | TPS54202DDC | C191884
U605, U606 | SOT-23-6 | 2 | LM74700 | C2941042
Y101 | Crystal_SMD_3225-4Pin_3.2x2.5mm | 1 | 3225 40MHz 10ppm | C37635388

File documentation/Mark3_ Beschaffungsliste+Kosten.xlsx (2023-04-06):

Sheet: Stückliste_Mark3_10"_optimiert
 |  |  | 10" LED Module (Akku extern) Alu-Profile
Mark 3 |  |  |  |  |  |  |  |  |  | Gesamt / Set | 1117.04 | €
Nr. | Name | Auswahl | €/Stk. | Anzahl | € gesamt | €gesamt Auswahl |  |  | Shop | Link
 |  |  |  |  |  |  | [mm] | [mm]
1 | Gehäuse |  |  |  |  |  | (L) | (B)
1.1 | Alu-Profile
1.1.1 | Oben/Unten Alu-Profile | 1 | 9.56 | 4 | 38.24 | 38.24 | 386 |  | Dold | DOLD Mechatronik | Aluminiumprofil 16x120E I-Typ Nut 8 (dold-mechatronik.de) (https://www.dold-mechatronik.de/Aluminiumprofil-16x120E-I-Typ-Nut-8)
1.1.2 | Seiten Alu-Profile | 1 | 6.68 | 4 | 26.73 | 26.73 | 266 |  | Dold | DOLD Mechatronik | Aluminiumprofil 16x120E I-Typ Nut 8 (dold-mechatronik.de) (https://www.dold-mechatronik.de/Aluminiumprofil-16x120E-I-Typ-Nut-8)
1.1.3 | Scheiben-Dichtungen (min. 7 m) | 1 | 2.5 | 7 | 17.50 | 17.50 |  |  | Dold | https://www.dold-mechatronik.de/Scheibendichtung-I-Typ-Nut-8-fuer-Scheibenstaerke-4-6mm-Laenge-1m
1.1.4 | Befestigungsmaterial Dold
1.1.4.1 | Schraube - M5x20 Zylinderkopfschraube Edelstahl x100 | 1 | 0.09 | 100 | 9.00 | 9.00 |  |  | Dold | DIN 912 Zylinderschraube mit Innensechskant, Edelstahl A2, 0,18 € (dold-mechatronik.de) (https://www.dold-mechatronik.de/DIN-912-Zylinderschraube-mit-Innensechskant-Edelstahl-A2-M5X20-VO)
1.1.4.2 | Schraube - M3x20 Senkkopfschraube | 1 | 0.19 | 8 | 1.52 | 1.52 |  |  | Dold | DIN 7991 Senkschraube mit Innensechskant, A2, M3X20, 0,19 € (dold-mechatronik.de) (https://www.dold-mechatronik.de/DIN-7991-Senkschraube-mit-Innensechskant-A2-M3X20)
1.1.4.3 | Mutter - M3 Mutter (Selbstsichernd) | 1 | 0.17 | 8 | 1.36 | 1.36 |  |  | Dold | Mutter selbstsichernd DIN985-A2 Größe wählbar, 0,17 € (dold-mechatronik.de) (https://www.dold-mechatronik.de/Mutter-DIN-985-M3-A2)
1.1.5 | Dold Versand | 1 | 6.90 | 1 | 6.90 | 6.90 |  |  | Dold
1.2 | Plattenmaterial
 | Optionen Base Plate
1.2.1.1 | Grundplatte LEDs (MDF, schwarz) 19 mm (unbearbeitet) | 1 | 7.00 | 2 | 14.00 | 14.00 | 422 | 302 | Baumarkt | MDF-Platte nach Maß (Schwarz, Max. Zuschnittsmaß: 2.800 x 2.100 mm, Stärke: 19 mm) | BAUHAUS (https://www.bauhaus.info/zuschnittplatten/mdf-platte-nach-mass/p/14450962)
 | oder
1.2.1.2 | Grundplatte LEDs (MDF, schwarz) 19 mm (bearbeitet) | 0 |  | 2 | 0.00 | 0.00 |  |  | Hendrik Angebot anfragen | info@devdrik.de
 | oder
1.2.1.3.1 | Grundplatte LEDs (MDF) 8 mm (nicht getestet) | 0 |  | 2 | 0.00 | 0.00
1.2.2 | Rückwand hart PVC dunkel grau 4 mm | 1 | 7.56 | 2 | 15.12 | 15.12 | 422 | 303 | Kunststoffplattenonline | Hart PVC Platten Dunkelgrau 4 mm - Zuschnitt nach Maß (kunststoffplattenonline.de) (https://kunststoffplattenonline.de/product/hart-pvc-platten-dunkelgrau-4-mm/)
1.2.3 | Polycarbonat Platte klar 4 mm | 1 | 8.25 | 2 | 16.50 | 16.50 | 422 | 303 | Kunststoffplattenonline | Polycarbonat Platten transparent (klar) 4 mm (kunststoffplattenonline.de) (https://kunststoffplattenonline.de/product/polycarbonat-platten-transparent-klar-4-mm/)
1.2.4 | Versand Platten | 1 | 8.27 | 1 | 8.27 | 8.27 |  |  | Kunststoffplattenonline
1.3 | Riemengriff | 1 | 1.9 | 2 | 3.80 | 3.80 |  |  | Thomann | ⁣Adam Hall 3427 Strap Handle Black – Musikhaus Thomann (https://www.thomann.de/de/adam_hall_3427_strap_handle_black.htm?partner_id=81150)
1.4 | Gurt Ösen | 1 | 1.4 | 4 | 5.60 | 5.60 |  |  | Thomann | ⁣Adam Hall Hardware 2882 Mounting Ring – Musikhaus Thomann (https://www.thomann.de/de/adam_hall_hardware_2882_mounting_ring.htm?partner_id=81150)
1.5 | Schrauben (Holz) |  |  |  |  |  |  |  | Baumarkt
1.5.1 | Schraube - SPANPL.FLAKO A2 5 x 40 10Stk (Griff) | 1 | 1.15 | 1 | 1.15 | 1.15 |  |  | Baumarkt
1.5.2 | Schraube - SPANPL.PANH.BLAU 4,0 x 40 10Stk (Ösen) | 1 | 0.4 | 1 | 0.40 | 0.40 |  |  | Baumarkt
1.5.3 | Schraube - INOX SPANPL A2 4,0 x 50 5Stk (Flange) | 1 | 0.81 | 1 | 0.81 | 0.81 |  |  | Baumarkt
1.5.4 | Schraube - Senkkopf 3,0 x 20 2Stk (Flange-zentral) | 1 | 0.2 | 1 | 0.20 | 0.20 |  |  | Baumarkt
1.6 | Filament extrudr® BDP ø1.75mm (0.8kg) Greentec PRO CARBON | 1 | 51.99 | 2 | 103.98 | 103.98 |  |  | Amazon | extrudr® BDP ø1.75mm (0.8kg) Greentec PRO CARBON - erdölfreies BIO-Filament! mit Carbon-Verstärkung! Mechanisch & Thermisch hoch belastbar! Made in Austria - europäische Qualität zum fairen Preis! : Amazon.de: Gewerbe, Industrie & Wissenschaft (https://www.amazon.de/gp/product/B07R6TDJ1L/ref=ppx_yo_dt_b_asin_title_o02_s00?ie=UTF8&psc=1)
1.6.1 | 3D Druck Ecken |  |  | 8 |  |  |  |  | 3D-Druck
1.6.2 | 3D Druck Stativ Aufnahme |  |  | 2 |  |  |  |  | 3D-Druck
1.6.3 | 3D Druck Typen-Plakette |  |  | 2 |  |  |  |  | 3D-Druck
1.6.4 | 3D Druck Buchsen-Plakette |  |  | 2 |  |  |  |  | 3D-Druck
1.6.5 | 3D Druck Lüftungsgitter (optional) |  |  | 4 |  |  |  |  | 3D-Druck
1.6.6 | 3D Druck Platinen Stand-Ups |  |  | 12 |  |  |  |  | 3D-Druck
1.6.7 | 3D Druck Antennenhalter |  |  | 2 |  |  |  |  | 3D-Druck
1.6.8 | 3D Druck Traversen-Manschetten-Clip (Horn-Cuff-Clip) |  |  | 2 |  |  |  |  | 3D-Druck
 | Optionen Dichtungen
1.7 | Filament Flex 45 Sample 50g | 1 | 7.89 | 0 | 0.00 | 0.00 |  |  | TND3D | https://die-3d-druckerei.de/produkt/flex-45-sample-50g
1.7.1 | 3D Druck Dichtungen Ecken |  |  |  |  |  |  |  | 3D-Druck
1.7.2 | 3D Druck Dichtungen Scheiben für Ecken (optional) |  |  |  |  |  |  |  | 3D-Druck
1.7.3 | 3D Druck Dichtungen Ösen-Platte |  |  |  |  |  |  |  | 3D-Druck
1.7.4 | 3D Druck Dichtungen Ösen-Schrauben |  |  |  |  |  |  |  | 3D-Druck
 | oder
1.8 | 0,5 mm EPDM-Matte mit Plotter geschnitten
1.8.1 | Dichtungen Ecken | 0 | 0.3 | 20 | 6.00 | 0.00 |  |  | Hendrik Angebot anfragen | info@devdrik.de
1.8.2 | Dichtungen Scheiben für Ecken (optional) | 0 | 0.1 | 40 | 4.00 | 0.00 |  |  | Hendrik Angebot anfragen | info@devdrik.de
1.8.3 | Dichtungen Ösen-Platte | 0 | 0.3 | 4 | 1.20 | 0.00 |  |  | Hendrik Angebot anfragen | info@devdrik.de
1.8.4 | Dichtungen Ösen-Schrauben (Scheiben) | 0 | 0.1 | 6 | 0.60 | 0.00 |  |  | Hendrik Angebot anfragen | info@devdrik.de
1.9 | Sikaflex-291i Haftstarker Dichtstoff 70ml Schwarz | 1 | 8.95 | 1 | 8.95 | 8.95 |  |  | Amazon | Sikaflex-291I Haftstarker Marine-Dichtstoff 70ml Schwarz : Amazon.de: Auto & Motorrad (https://www.amazon.de/SIKA-FRANCE-S-A-S-487383-Mehrzweck-Fugenmasse/dp/B016KCJRT6)
 | Gesamt Gehäuse / Set |  |  |  |  | 280.03 | €
 | Gesamt Gehäuse / Display |  |  |  |  | 140.02 | €
2 | Elektronik
2.1 | esp32 lora | 1 | 23.99 | 3 | 71.97 | 71.97 |  |  | Aliexpress | https://s.click.aliexpress.com/e/_A1a1bz
 | --> alternativ (schneller/teurer) | 0 | 28.99 |  | 0.00 | 0.00 |  |  | Amazon | DollaTek 433MHz - 470MHz Lora SX1278 Entwicklungsboard 0.96 OLED-Display ESP32 WiFi Kit 32 Bluetooth-Kartenentwicklung IOT-Modul für Arduino: Amazon.de: Elektronik & Foto (https://www.amazon.de/gp/product/B07QXR7SJ5/ref=ppx_yo_dt_b_search_asin_title?ie=UTF8&psc=1)
2.2 | PCA9685 (unbestückt) | 1 | 6 | 2 | 12.00 | 12.00 |  |  | Aliexpress | https://s.click.aliexpress.com/e/_AM8t7v
 | --> alternativ (schneller/teurer) | 0 | 8.99 |  | 0.00 | 0.00 |  |  | Amazon | DollaTek 16-Kanal 12-Bit-PWM-Servomotortreiber I2C Modul Board PCA9685 Für Arduino/Roboter/Raspberry Pi: Amazon.de: Elektronik & Foto (https://www.amazon.de/DollaTek-16-Kanal-12-Bit-PWM-Servomotortreiber-PCA9685-Raspberry/dp/B07DK6YD6Y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)
2.3 | Mosfet Treiber 4er (YYNMOS-4, grün) | 1 | 3 | 10 | 30.00 | 30.00 |  |  | Aliexpress | https://s.click.aliexpress.com/e/_DFZa5DR
2.4 | Kabel
2.4.1 | Kabel DC + Horn | 1 | 20 | 2 | 40.00 | 40.00 |  |  | Amazon | 5m KFZ Verlängerungskabel 12V, Verlängerung, 15A Sicherung, Vollgummileitung mit Stecker und Buchse, Klettband, für Zigarettenanzünder-Buchse: Amazon.de: Auto & Motorrad (https://www.amazon.de/gp/product/B08121ZPV5/ref=ppx_yo_dt_b_search_asin_title?ie=UTF8&th=1)
2.4.2 | Stecker DC | 1 | 4.7 | 2 | 9.40 | 9.40 |  |  | Thomann | https://www.thomann.de/de/varytec_real_pf.htm?partner_id=81150
2.4.3 | Stecker Horn | 1 | 4.7 | 2 | 9.40 | 9.40 |  |  | Thomann | https://www.thomann.de/de/varytec_real_pm.htm?partner_id=81150
2.4.4.1 | Flachsteckklemmen 12 Stk. | 0 |  | 12 | 0.00 | 0.00 |  |  | Hendrik Angebot anfragen | info@devdrik.de
 | oder
2.4.4.2 | Flachsteckklemmen 100Stk. Packung | 1 | 7.10 | 1 | 7.10 | 7.10 |  |  | Amazon | Fixpoint 17002 Flachsteckhülse, Steckmaß 6.4 mm x 0.8 mm, 10 A, Rot (100-er pack) : Amazon.de: Gewerbe, Industrie & Wissenschaft (https://www.amazon.de/gp/product/B000L0ZCUC/ref=ppx_yo_dt_b_asin_title_o04_s00?ie=UTF8&psc=1)
2.4.5.1 | Aderendhülsen 1,5 qmm | 0 |  | 6 | 0.00 | 0.00 |  |  | Hendrik Angebot anfragen | info@devdrik.de
 | oder
2.4.5.2 | Aderendhülsen 1,5 qmm (6Stk.) | 1 | 0.2 | 6 | 1.20 | 1.20 |  |  | selber suchen
2.5 | Horn/Hupe/Buzzer | 1 | 7.63 | 2 | 15.26 | 15.26 |  |  | Amazon | HELLA 3AL 922 000-951 Horn - S90 - 12V - 113dB(A) - Frequenzbereich: 350Hz - Tiefton - Gehäusefarbe: rot/schwarz - Flachsteckanschluss : Amazon.de: Auto & Motorrad (https://www.amazon.de/gp/product/B00H8QOLNG/ref=ppx_yo_dt_b_search_asin_title?ie=UTF8&psc=1)
2.6 | LED Module (weiß oder rot - 4x7 Segmente Set -Preis abgeschätzt) | 1 | 149 | 1 | 149.00 | 149.00 |  |  | Aliexpress | https://s.click.aliexpress.com/e/_AUnjyR
2.7 | Ein/Aus Schalter
2.7.1 | Taster 16mm (2er Paket) | 1 | 9.49 | 1 | 9.49 | 9.49 |  |  | Amazon | Gebildet 2 Stücke 16mm Edelstahl Latching Drucktastenschalter 12V-24V 5A Power Symbol LED 1NO1NC SPDT ON Off Wasserdichter Kippschalter mit Steckdose Stecker (Weiß LED) : Amazon.de: Baumarkt (https://www.amazon.de/dp/B07QM53HK6/ref=emc_b_5_t?th=1)
2.7.2.1 | Aderendhülse 0,5 qmm | 0 |  | 10 | 0.00 | 0.00 |  |  | Hendrik Angebot anfragen | info@devdrik.de
 | oder
2.7.2.2 | Aderendhülse 0,5 qmm (10Stk.) | 1 | 0.2 | 10 | 2.00 | 2.00 |  |  | selber suchen
2.8 | Step-down LM2596S (3er Packet, einer Ersatz) | 1 | 5.49 | 1 | 5.49 | 5.49 |  |  | Amazon | AZDelivery 3 x LM2596S DC-DC Netzteil Adapter Step down Modul kompatibel mit Arduino inklusive eBook!: Computer & Zubehör (amazon.de) (https://www.amazon.de/dp/B07YWLCTLK/ref=twister_B07ZQFCFXW?_encoding=UTF8&psc=1)
2.9 | Kabeldurchführung DC (Buchse) | 1 | 3.2 | 2 | 6.40 | 6.40 |  |  | Thomann | https://www.thomann.de/de/varytec_real_cm.htm?partner_id=81150
2.10 | Kabeldurchführung Horn (Buchse) | 1 | 3.2 | 2 | 6.40 | 6.40 |  |  | Thomann | https://www.thomann.de/de/varytec_real_cf.htm?partner_id=81150
2.11.1 | Abdeckung/Dichtung Buchsen Power In | 1 | 4.9 | 1 | 4.90 | 4.90 |  |  | Thomann | ⁣Neutrik SCnac-MPX True1 5pc – Musikhaus Thomann (https://www.thomann.de/de/neutrik_scnac_mpx_true1_5pc.htm?partner_id=81150)
2.11.2 | Abdeckung/Dichtung Buchsen Horn | 1 | 0.99 | 2 | 1.98 | 1.98 |  |  | Thomann | Neutrik SCnac-FPX True1 – Musikhaus Thomann (https://www.thomann.de/de/neutrik_scnac_fpx_true1.htm?partner_id=81150)
2.12 | Platinen Display | 1 | 9 | 2 | 18.00 | 18.00 |  |  | Hendrik Angebot anfragen | info@devdrik.de
2.13 | Bauteile Platine passiv (Buchsen, Klemmen usw.) | 1 | 10 | 2 | 20.00 | 20.00 |  |  | Hendrik Angebot anfragen | info@devdrik.de
2.13.1 | JST connector 2Pin (Buchse XH2.54, min 32x)
2.13.2 | 40er Stiftleiste männlich (1x)
2.13.3 | 40er Stiftleiste weiblich (8x)
2.13.4 | Schalter/Jumper (2x)
2.13.5 | Elko 100 oder 200 uF (2x) (optional)
2.13.6 | Schraubklemme 5.08 2Pin (6x)
2.13.7 | Diode 1N4004 (4x)
2.14 | Schraube - SPANPL.PANH.BLAU 3,0 x 13 12Stk. (Platine - 3,0 x 25 wäre auch möglich) | 1 | 0.5 | 1 | 0.50 | 0.50 |  |  | Baumarkt
2.15 | Schraube - SPANPL.PANH.BLAU 3,0 x 25 66Stk. (LEDs) | 1 | 2.15 | 1 | 2.15 | 2.15 |  |  | Baumarkt
2.16 | Schraube - Senkkopf 2,0 x 10 4Stk | 1 | 0.1 | 4 | 0.40 | 0.40 |  |  | Baumarkt
2.20 | Optionen
2.20.1 | Aktive Lüftung (nicht in Software/nicht getestet) |  | 20.50 | (€ gesamt)
2.20.1.1 | Lüfter 60mm 2Stk. | 0 | 12.98 | 1 | 12.98 | 0.00 |  |  | Amazon | Security-01 6015 Lüfter mit Kugellager, bürstenlos, 60 mm x 60 mm x 15 mm, 12 V Gleichstrom, 2-polig: Amazon.de: Computer & Zubehör (https://www.amazon.de/dp/B072MH2ZG9/?coliid=I36MAE7IX462B9&colid=1NMY0ASBL6F0I)
2.20.1.2 | Tempsensor LM75A (2stk.) | 0 | 6.99 | 1 | 6.99 | 0.00 |  |  | Amazon | Hailege 2pcs LM75 LM75A Temperature Sensor High Speed I2C Interface High Precision Development Board : Amazon.de: Gewerbe, Industrie & Wissenschaft (https://www.amazon.de/gp/product/B07YTYHVLT/ref=ppx_yo_dt_b_asin_title_o04_s00?ie=UTF8&psc=1)
2.20.1.3 | Schraube - M4x30 Senkkopfschraube | 0 | 0.26 | 8 | 2.08 | 0.00 |  |  | Dold | DIN 7991 Senkschraube mit Innensechskant, Edelstahl A2, 0,14 € (dold-mechatronik.de) (https://www.dold-mechatronik.de/DIN-7991-Senkschraube-mit-Innensechskant-A2-M4X30)
2.20.1.4 | Scheibe - M4 Unterlegscheibe | 0 | 0.12 | 8 | 0.96 | 0.00 |  |  | Dold | Scheibe DIN125A-43 X M4-A2, 0,14 € (dold-mechatronik.de) (https://www.dold-mechatronik.de/Scheibe-DIN125A-43-X-M4-A2)
2.20.1.5 | Mutter- M4 Mutter (Selbstsicherend) | 0 | 0.15 | 8 | 1.20 | 0.00 |  |  | Dold | Mutter selbstsichernd DIN985-A2 Größe wählbar, 0,17 € (dold-mechatronik.de) (https://www.dold-mechatronik.de/Mutter-DIN-985-M4-A2)
2.20.2 | Kabel-Verbindung |  | 126.99 | (€ gesamt)
2.20.2.1 | RS-485 Modul | 1 | 1 | 6 | 6.00 | 6.00 |  |  | Aliexpress | https://s.click.aliexpress.com/e/_DFlEJFL
 | --> alternativ (schneller/teurer/zu viele) | 0 | 8.99 | 2 | 17.98 | 0.00 |  |  | Amazon | JZK 5 Stück TTL-auf-RS485-Modul, 485 auf seriellen Anschluss, UART-Niveau-Konvertierung, automatische Durchflusskontrolle, TTL-Drehung RS485, 3,3 V, 5 V: Amazon.de: Elektronik & Foto (https://www.amazon.de/JZK-TTL-auf-RS485-Modul-UART-Niveau-Konvertierung-Durchflusskontrolle-RS485/dp/B09VGJCJKQ/)
2.20.2.2 | Ethernet patch kabel 0,5m | 1 | 3.29 | 2 | 6.58 | 6.58 |  |  | Amazon | deleyCON 0,5m CAT.6 Ethernet Gigabit Lan Netzwerkkabel RJ45 CAT6 Kabel Patchkabel Kompatibel zu CAT.5 CAT.5e CAT.6a Cat.7 - Schwarz : Amazon.de: Computer & Zubehör (https://www.amazon.de/deleyCON-Ethernet-Netzwerkkabel-Patchkabel-Kompatibel-Schwarz/dp/B01LLOGOYO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)
2.20.2.3 | Ethernet patch kabel 2m | 0 | 3.99 | 1 | 3.99 | 0.00 |  |  | Amazon | deleyCON 2m CAT.6 Ethernet Gigabit Lan Netzwerkkabel RJ45 CAT6 Kabel Patchkabel Kompatibel zu CAT.5 CAT.5e CAT.6a Cat.7 - Schwarz : Amazon.de: Computer & Zubehör (https://www.amazon.de/dp/B01LLOGUNY/ref=twister_B07BXRPSTJ?_encoding=UTF8&psc=1)
2.20.2.4 | Ethernet Kabel 60m | 0 | 24.62 | 2 | 49.24 | 0.00 |  |  | Amazon | Goobay 94396 CAT6 Kabel für Außenbereich Netzwerkkabel UV- und Wassergeschützt schwarz/blau, 60 Meter: Amazon.de: Computer & Zubehör (https://www.amazon.de/Goobay-94396-Au%C3%9Fenbereich-Netzwerkkabel-Wassergesch%C3%BCtzt/dp/B00KP3KFXO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)
2.20.2.5 | Seetronic SE8MC-05-NEW RJ45 (siehe Wiki für Alternativen) | 0 | 5.5 | 2 | 11.00 | 0.00 |  |  | Thomann | Seetronic SE8MC-05-NEW RJ45 – Musikhaus Thomann (https://www.thomann.de/de/seetronic_se8mc_05_new_rj45.htm)
2.20.2.6 | Seetronic SE8FD05-02 RJ45 IP65 (siehe Wiki für Alternativen) | 1 | 9.1 | 2 | 18.20 | 18.20 |  |  | Thomann | Seetronic SE8FD05-02 RJ45 IP65 – Musikhaus Thomann (https://www.thomann.de/de/seetronic_se8fd05_02_rj45_ip65.htm)
2.20.2.7 | Platine Verteilung | 0 | 4 | 1 | 4.00 | 0.00 |  |  | Hendrik Angebot anfragen | info@devdrik.de
2.20.2.8 | Ethernetbuchsen Platine | 0 | 2.4 | 4 | 9.60 | 0.00 |  |  | Hendrik Angebot anfragen | info@devdrik.de
2.20.2.9 | Gehäuse Verteilung (3D Druck) | 0 | 0 | 1 | 0.00 | 0.00 |  |  | 3D-Druck
2.20.2.10 | Schraube - 4x 2x10 Schrauben für Gehäuse | 0 | 0.1 | 4 | 0.40 | 0.00 |  |  | Baumarkt
 | Gesamt Elektronik / Set |  |  |  |  | 453.82 | €
 | Gesamt Elektronik / Display |  |  |  |  | 226.91 | €
3 | Steuerung
3.1 | 3D-Druck Gehäuse (Oben und Unten) | 1 |  | 1 | 0.00 | 0.00 |  |  | 3D-Druck
3.2 | Ladegerät 5v min 1A und Micro-USB Kabel | 0 | 9.99 | 1 | 9.99 | 0.00 |  |  | Amazon | Dericam 5V 1A Micro USB Wandladegerät, Android Ladekabel, 5 Volt 1000mA AC, DC Netzteil für die Überwachungskamera von Android Smartphones,Tablets und Heimkameras, 1,5m Netzkabel, EU Stecker: Amazon.de: Elektronik & Foto (https://www.amazon.de/dp/B07ZNS3WK1?s=ce-de)
3.3.1 | Power Bank | 1 | 20 | 1 | 20.00 | 20.00 |  |  | Amazon | https://amzn.to/3KFdgb3
3.3.2 | Akku Lipo (optional, nicht empohlen) | 0 |  | 0 | 0.00 | 0.00
3.4 | esp32 lora (bei Elektronik mit dabei) | 0
3.5 | Platinen (blau/rot) | 1 | 10 | 1 | 10.00 | 10.00 |  |  | Hendrik Angebot anfragen | info@devdrik.de
3.6 | Bauteile (Button, Schalter usw.) | 1 | 9 | 1 | 9.00 | 9.00 |  |  | Hendrik Angebot anfragen | info@devdrik.de
3.6.1 | Ethernet Buchse
3.6.2 | TP4056 Lipo Lademodul
3.6.3 | Button 6x
3.6.4 | Steiftleiste männlich 4x4er von Elektronik
3.6.5 | Stiftleiste weiblich 4x4er (speziell?, sonst bei Elektronik +1)
3.6.6 | Linearregler AP2112K-3.3
3.6.7 | 1.25 Batterie Buchse
3.6.8 | Schraube - Senkkopf 2,0 x 4,5 4Stk
3.7 | Schraube - Senkkopf 2,0 x 10 8Stk |  | 0.1 | 8 | 0.80 | 0.00 |  |  | Baumarkt
 | Gesamt Steuerung / Set |  |  |  |  | 39.00
4 | Versorgung (Optionen)
4.1 | TotalCool MSC 38k 144Wh | 1 | 129 | 2 | 258.00 | 258.00 |  |  | campingandmore24 | Camping und Freizeitzubehör (campingandmore24.de) (https://www.campingandmore24.de/fahrzeugausstattung/technik/klima-_-belueftung/totalcool-lithium-batterie-16ah-12_24v-oder-230v-mit-adapter142420.html)
4.2 | Fox Halo Power Pack 96k 307Wh | 0 | 188 | 2 | 376.00 | 0.00 |  |  | Fischingtackle24 | Fox Halo Power 96K, Fishingtackle24 - Angelbedarf Angelruten Angelbekleidung Angelzubehör Kunstköder Angeltaschen Angelzelt Angelschnur (https://www.fishingtackle24.de/outdoor/angelzelt-schirm-co/zelt-zubehoer/fox-halo-power-96k.html)
4.3 | Netzteil (optional, nur Indoor) | 0 | 22 | 2 | 44.00 | 0.00 |  |  | Amazon | Digit.Tail Netzgleichrichter Netzadapter Spannungswandler Konverter 220V/230V/240V auf 12V/10A (120W) KFZ Zigarettenanzünder Wechselrichter AC/DC Adapter für PKW Kühlbox Navi : Amazon.de: Auto & Motorrad (https://www.amazon.de/dp/B07GMMTPJ6/?coliid=I25LYBUL8YZSND&colid=1NMY0ASBL6F0I)
4.4.1 | RoyPow Akku 86.58Wh | 0 | 70 | 2 | 140.00 | 0.00 |  |  | Amazon | RoyPow Tragbares Ladegerät 30W PD USB-C Power Bank mit 12V Zigarettenanzünder Steckdose, externem Akku für Laptop MacBook Air iPad iPhone Autokamera oder Camping Reisen: Amazon.de: Elektronik & Foto (https://www.amazon.de/RoyPow-Tragbares-Ladeger%C3%A4t-Zigarettenanz%C3%BCnder-Autokamera/dp/B08JV6HTLK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)
4.4.2 | Ladegerät (PD) für RoyPow Akku | 0 | 15 | 2 | 30.00 | 0.00 |  |  | Amazon
4.5 | Rebelcell 48k 153Wh (/Fox Halo Power Pack 48k) | 0 | 169 | 2 | 338.00 | 0.00 |  |  | Echolotprofis | Rebelcell Power Rebel 48K | Wetterfeste Outdoor Powerbank &#9830; (echolotprofis.de) (https://www.echolotprofis.de/rebelcell-power-rebel-48k-powerbank/)
 | Gesamt Akku / Set |  |  |  |  | 258.00
5 | Zubehör
5.1 | Stativ-2er-Set + Tasche | 1 | 49 | 1 | 49.00 | 49.00 |  |  | Thomann | Millenium BS-2211B MKII Profi Boxenständer Set – Musikhaus Thomann (https://www.thomann.de/de/millenium_bs2211b_mkii_set.htm?partner_id=81150)
5.2 | Feuer-/Wasserfeste Akku (Trage-)Tasche | 1 | 23.79 | 1 | 23.79 | 23.79 |  |  | Amazon | Aitere Feuerfeste Dokumententasche 39 x 13 x 31cm Feuersichere wasserdichte Tasche Hülle Beutel Behälter für A4 Dokumente Passport Bankdatei Geld Wertsachen : Amazon.de: Baumarkt (https://www.amazon.de/gp/product/B07Q3Q3SK7/ref=ppx_yo_dt_b_asin_title_o00_s00?ie=UTF8&psc=1)
5.3 | (Gummi)-Bänder mit Haken (Aufhängen zB an Ballfangnetzen, Basketballkörben, Banden-Scheiben usw.) | 0 | 10 | 1 | 10.00 | 0.00
5.4 | Kabel Binder Klett | 0 | 5.9 | 1 | 5.90 | 0.00 |  |  | Thomann | https://www.thomann.de/de/thomann_v1012_10er_pack_kabelbinder.htm?partner_id=81150
5.5 | Befestigung Horn
5.5.1 | Rohrschelle/Traversenhalterung | 1 | 6.3 | 2 | 12.60 | 12.60 |  |  | Thomann | Duratruss Jr Eye Clamp 75kg black – Musikhaus Thomann (https://www.thomann.de/de/duratruss_jr_eye_clamp_75kg_black.htm)
5.5.2 | Mutter - M8 Mutter Selbsicherend | 1 | 0.4 | 2 | 0.80 | 0.80 |  |  | Dold | Nut DIN 985-A2 size selectable, 0,29 € (dold-mechatronik.de) (https://www.dold-mechatronik.de/Nut-DIN-985-M8-A2)
5.5.3 | Traversen-Schelle-Clip | 1 |  | 2 |  |  |  |  | 3D-Druck
 | Gesamt Zubehör / Set |  |  |  |  | 86.19 | €
 | Gesamt Zubehör / Display |  |  |  |  | 43.09 | €
 | Gesamt / Set |  |  |  |  | 1117.04 | €

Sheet: 3D_Druck
Carbon Pro
No. | Part | Amount | Gewicht [g] | Zeit [min] | Anzahl | Gewicht gesamt[g] | Zeit gesamt [min] | h
1 | Type_Plate_1 | 1
2 | Type_Plate_2 | 1
3 | Socket_Plate | 2
4 | Ventialtion_Grid (optional) | 4
5 | Lower_Corner_Joint | 4
6 | Upper_Corner_Joint | 4
7 | Tripod_Flange | 2
8 | Tripod_Flange_Insert | 2
9 | Horn_Cuff_Clip | 2
10 | Antenna_Bracket | 2
11 | PCB_Stand_Offs | 16
12 | Upper_Controller_Shell | 1
13 | Lower_Controller_Shell | 1
14 | Upper_Junction_Case | 1
15 | Lower_Junction_Case | 1
 | Gesamt |  |  |  |  | 0 | 0 | 0.0
Filament Flex (i.e. Flex 45 Sample 50g)
No. | Part |  | Gewicht [g] | Zeit [min] | Anzahl | Gewicht gesamt[g] | Zeit gesamt [min] | h
1 | Sealing_Corner_Joint | 18
2 | Round_Sealing_Corner_Joint (optional) | 36
3 | Sealing_Hinge | 4
4 | Round_Sealing_Hinge | 10

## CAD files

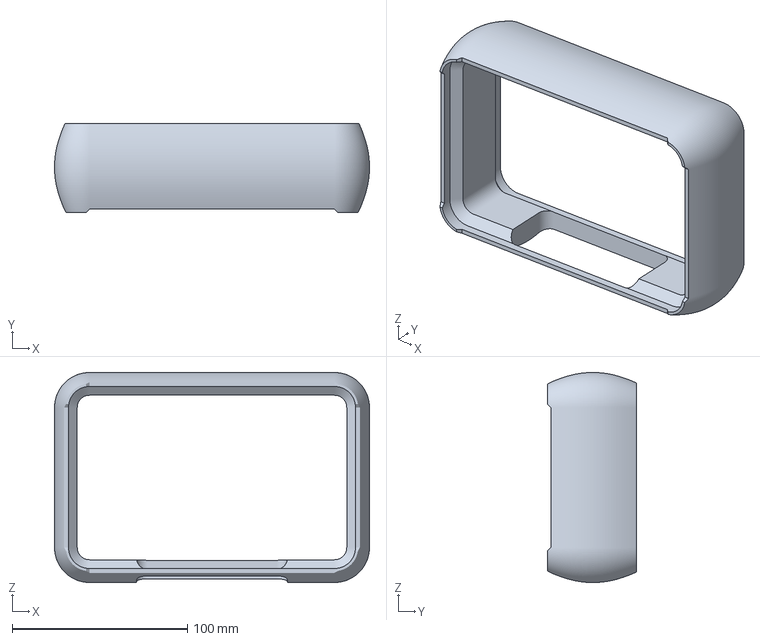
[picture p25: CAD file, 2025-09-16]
cad/Controller V3.0/Bumper v3.0.3mf
180.0 x 51.0 x 120.0 mm

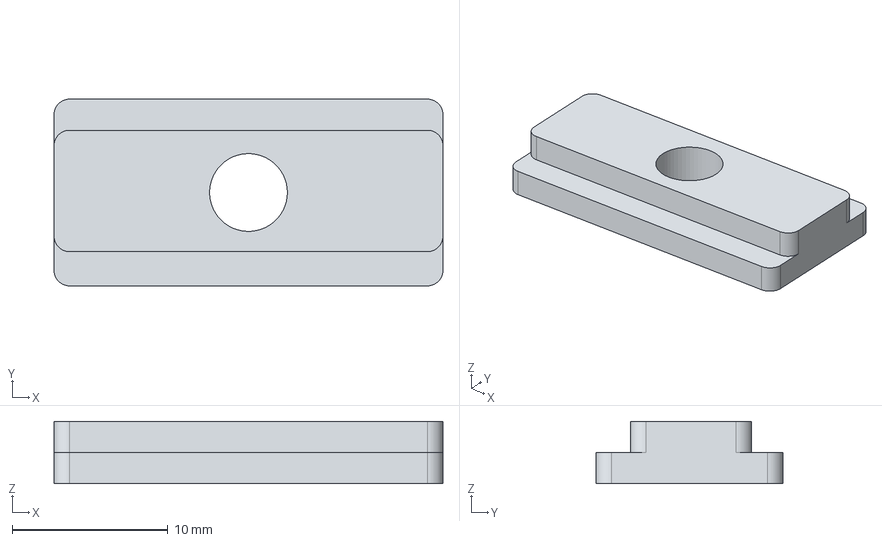
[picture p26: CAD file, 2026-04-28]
cad/led_spacer.step
25.0 x 12.0 x 4.00 mm

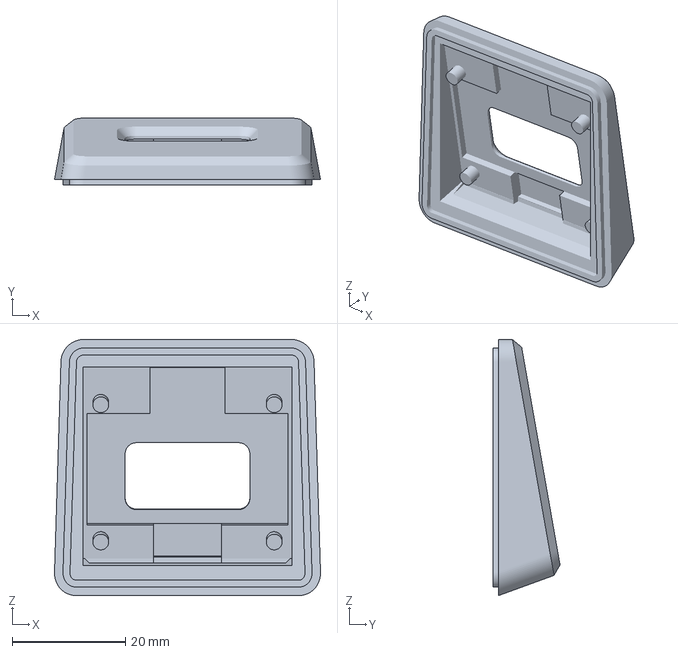
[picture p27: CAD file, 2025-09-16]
documentation/3dprinting_files/Controller V3.0/Display Case 1306 v3.0.3mf
46.9 x 11.8 x 45.2 mm

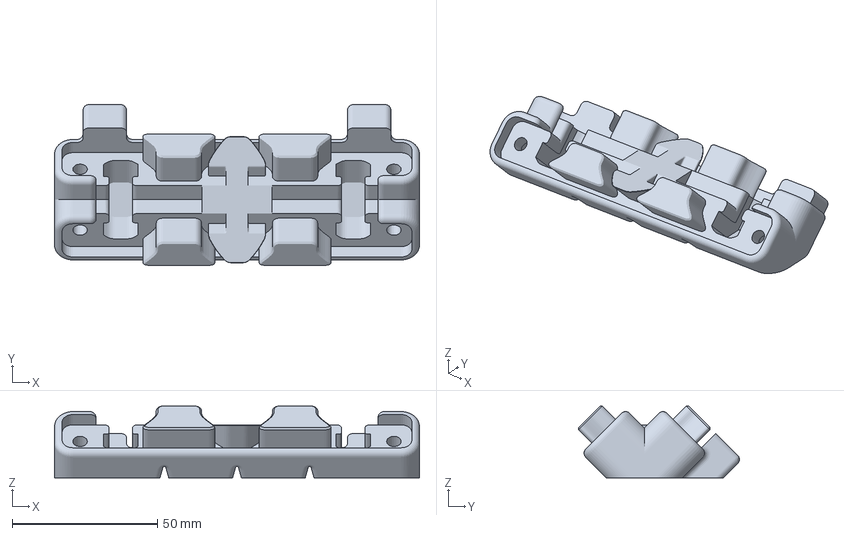
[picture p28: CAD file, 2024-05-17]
documentation/3dprinting_files/Lower_corner_joint_dewarp.3mf
125.6 x 55.4 x 24.7 mm

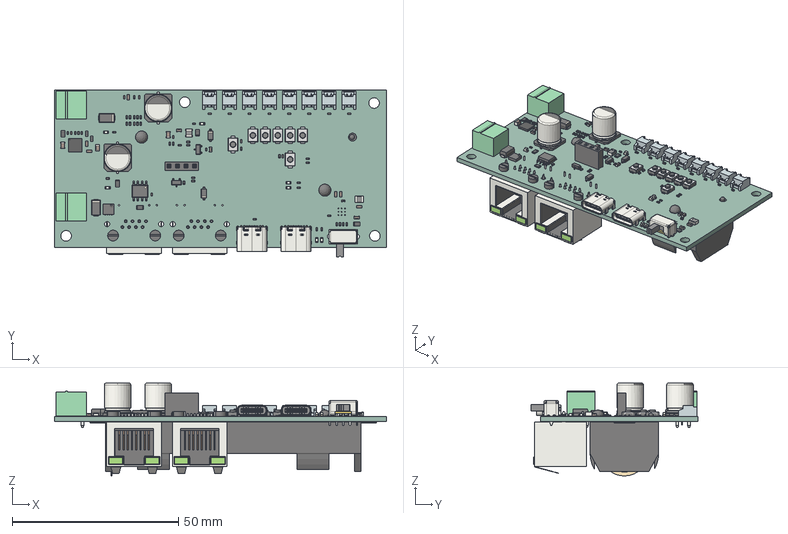
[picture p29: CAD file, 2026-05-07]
pcb/controller/_mech/Controller_R00.step
100.0 x 50.4 x 28.0 mm
LED_0603_1608Metric x 7
R_0805_2012Metric x 5
L_1008_2520Metric x 2
R_0402_1005Metric x 40
3x4x2mm - 2 button x 7
C_0603_1608Metric x 9
530480210wbm000_01 x 8
USB_C_Receptacle_16P_TopMnt_Horizontal_GCT_USB4105-xx-A x 2
C_0402_1005Metric x 17
SOT_23 x 2
R_0603_1608Metric x 2
CP_Elec_8x10 x 2
C_0805_2012Metric x 3
SOIC_8_39x49mm_P127mm
D_SMA x 2
VSON_8_33x33mm_Pitch065mm_NexFET
D_SOD_123 x 2
PinSocket_1x04_P254mm_Vertical
SW_Slide_SPDT_Angled_CK_OS102011MA1Q
MC_01x02_G_3_5mm x 2
Vishay_PowerPAK_MLP44_24L_cp
RJ45_Amphenol_RJHSE538X x 2
Keystone_1042_1x18650
Controller_PCB

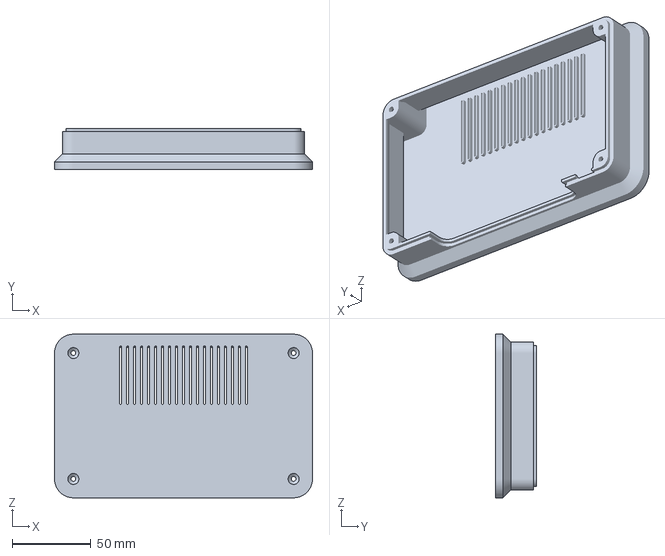
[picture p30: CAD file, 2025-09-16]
cad/Controller V3.0/Case Bottom v3.0.3mf
164.0 x 26.0 x 104.0 mm

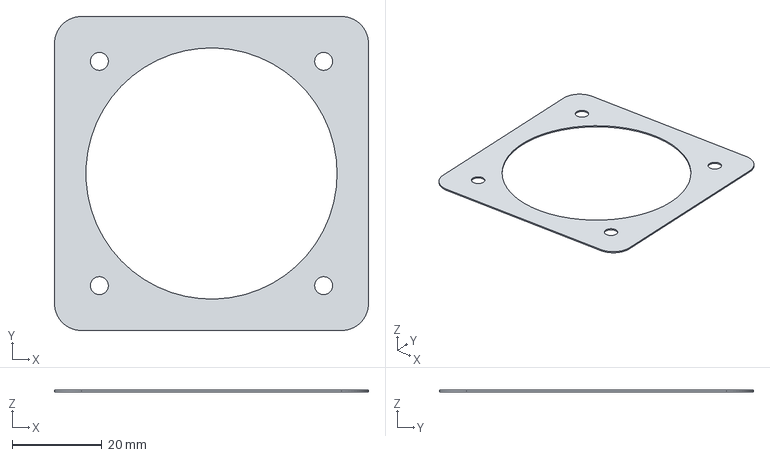
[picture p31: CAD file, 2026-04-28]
cad/fan_grid_seal.step
70.0 x 70.0 x 0.4 mm

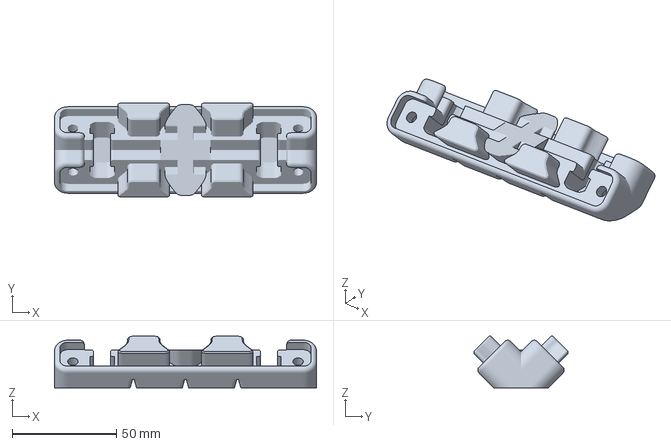
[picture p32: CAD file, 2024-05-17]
documentation/3dprinting_files/Upper_Corner_joint_dewarp.3mf
125.6 x 45.3 x 24.7 mm

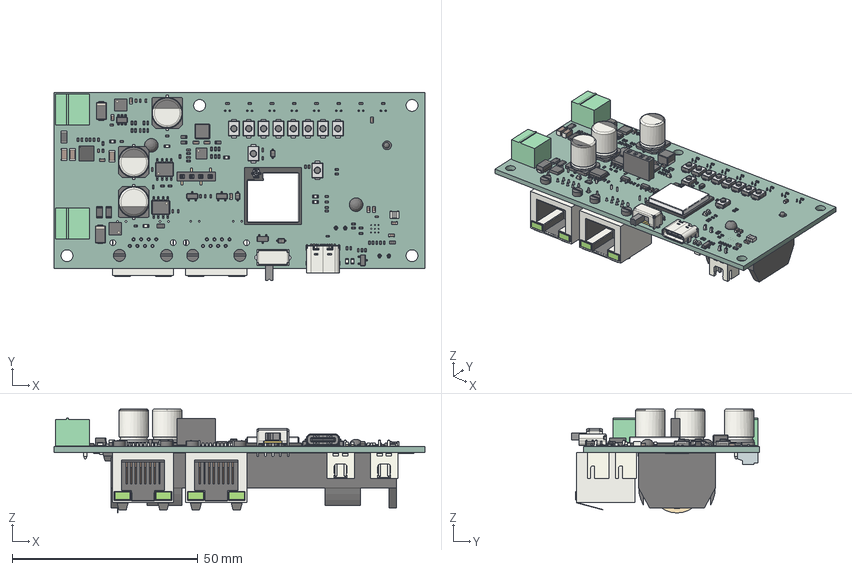
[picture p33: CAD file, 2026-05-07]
pcb/controller/_mech/Controller_R01.step
100.0 x 50.7 x 28.0 mm
LED_0603_1608Metric x 8
D_SOD_323 x 3
CP_Elec_8x10 x 3
R_0402_1005Metric x 57
R_1206_3216Metric x 3
L_1008_2520Metric
3x4x2mm - 2 button x 10
C_0603_1608Metric x 11
C_0402_1005Metric x 22
USB_C_Receptacle_16P_TopMnt_Horizontal_GCT_USB4105-xx-A
SOT_23 x 4
C_1206_3216Metric x 3
SOT_23_6
SOIC_8_39x49mm_P127mm x 2
ESP32-S3-MINI-1U_V1_3D
VSON_8_33x33mm_Pitch065mm_NexFET x 2
R_0603_1608Metric x 4
PinSocket_1x04_P254mm_Vertical_SMD_Pin1Left
SW_Slide_SPDT_Angled_CK_OS102011MA1Q
MC_01x02_G_3_5mm x 2
D_SMA x 2
L_Changjiang_FNR4030S
Vishay_PowerPAK_MLP44_24L_cp
R_0805_2012Metric
Texas_S_PVSON_N10
530480210wbm000_01 x 8
CQ assembly
RJ45_Amphenol_RJHSE538X x 2
JST_B2B_XH_A x 2
Keystone_1042_1x18650
Controller_PCB

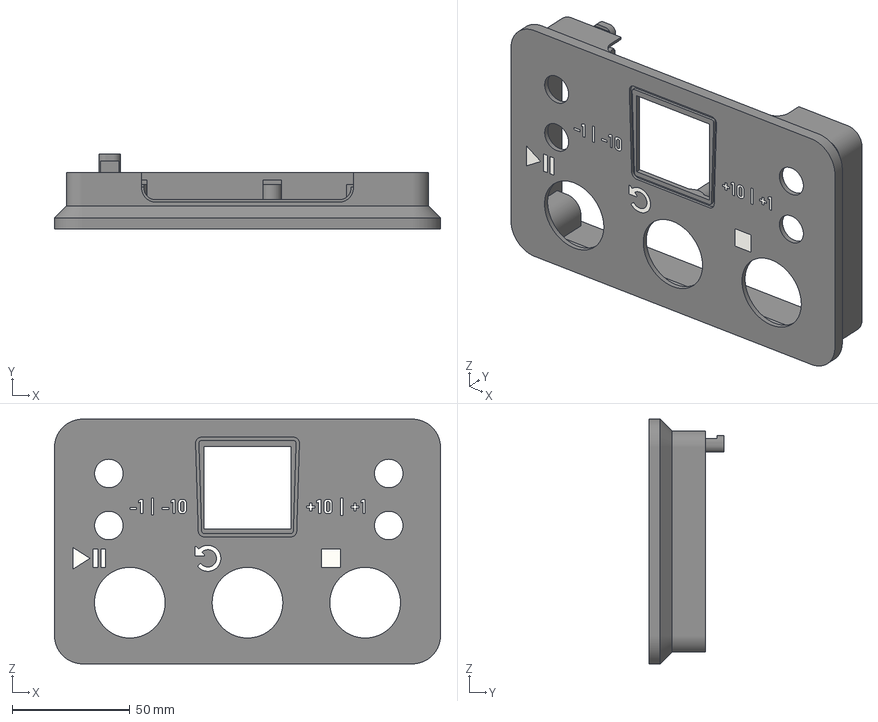
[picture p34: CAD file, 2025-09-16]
documentation/3dprinting_files/Controller V3.0/Case Top v3.0.3mf
164.0 x 32.0 x 104.0 mm
Körper1
Körper10
Körper11
Körper12
Körper13
Körper2 x 2
Körper3 x 2
Körper4 x 2
Körper5
Körper6 x 2
Körper7
Körper8 x 2
Körper9

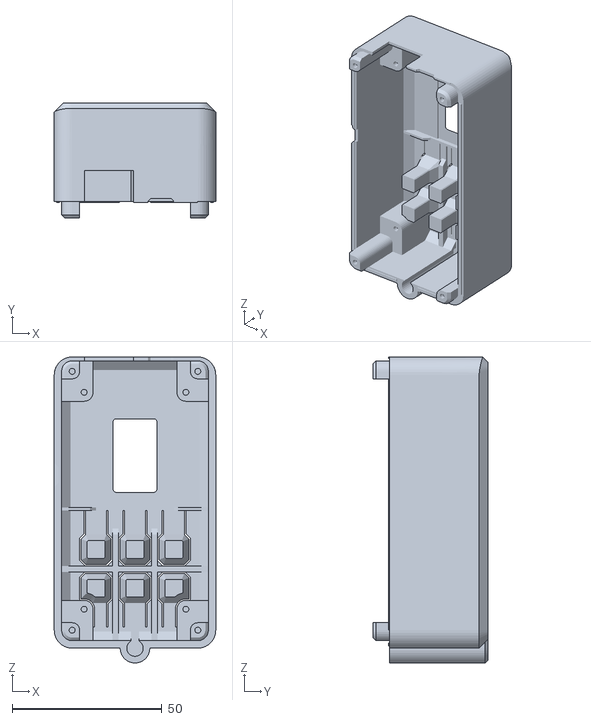
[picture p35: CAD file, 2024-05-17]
documentation/3dprinting_files/controller_top_high.stl
54.0 x 38.5 x 102.3

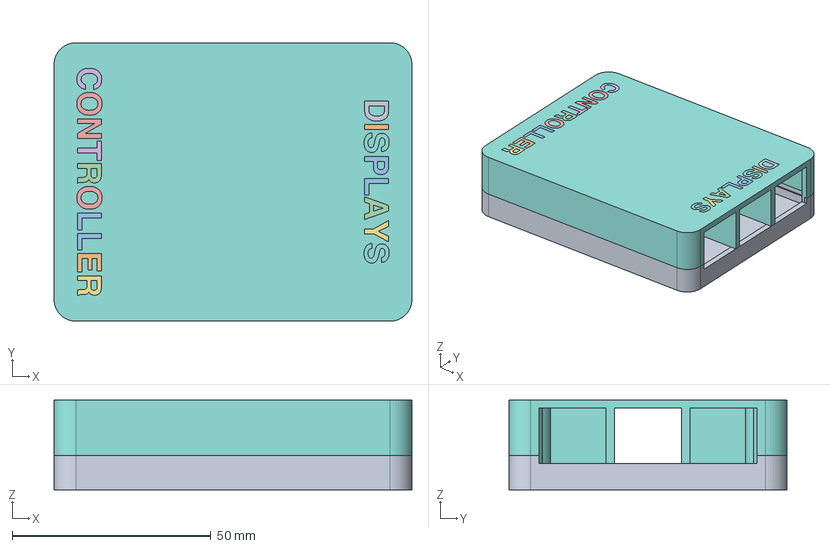
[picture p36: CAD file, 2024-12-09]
cad/junction_case_v2.step
90.0 x 70.0 x 22.6 mm
junction_case_bottom
text

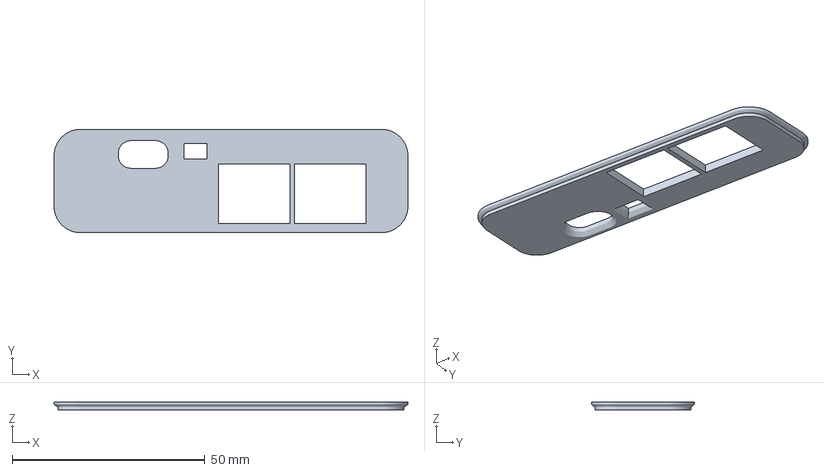
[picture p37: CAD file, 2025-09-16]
documentation/3dprinting_files/Controller V3.0/Back Panel v3.0.3mf
91.8 x 26.8 x 2.20 mm

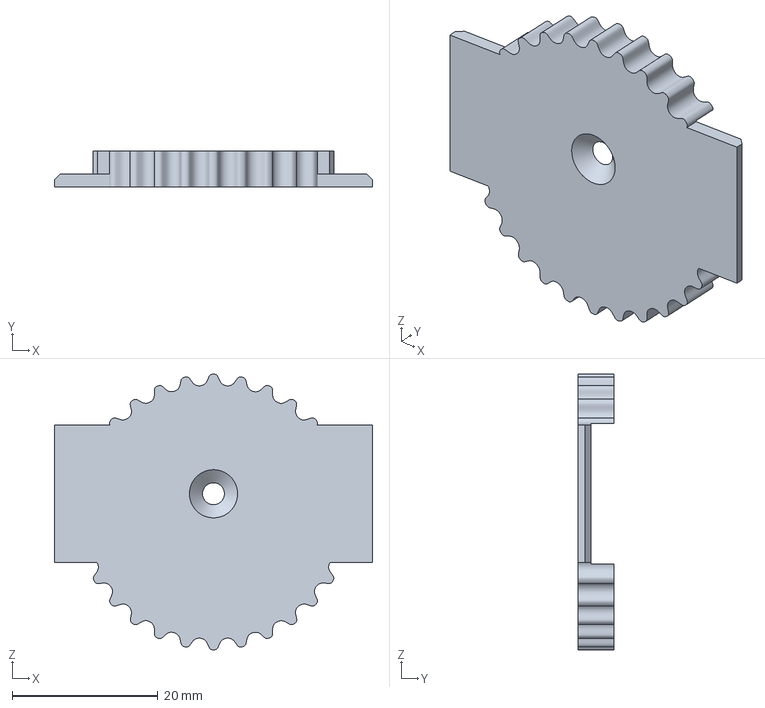
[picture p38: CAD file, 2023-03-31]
documentation/3dprinting_files/Tripod_Flange_Insert.3mf
43.6 x 5.00 x 37.8 mm

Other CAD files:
cad/Controller_Case_v3.0 v30.f3z
cad/Fan_Grid_screw.step
cad/Junction_Case_Mark3 v1.step
cad/Lower_corner_joint_dewarp.step
cad/Upper_Corner_joint_dewarp.step
cad/horn_cuff_looser.step
cad/led_spacer.FCStd
documentation/3dprinting_files/Antenna_Bracket.3mf
documentation/3dprinting_files/Horn_Cuff_Clip.3mf
documentation/3dprinting_files/Lower_Controller_Shell.3mf
documentation/3dprinting_files/Lower_Corner_Joint.3mf
documentation/3dprinting_files/Lower_Junction_Case.3mf
documentation/3dprinting_files/PCB_Stand_Offs.3mf
documentation/3dprinting_files/Round_Sealing_Corner_Joint.3mf
documentation/3dprinting_files/Round_Sealing_Hinge.3mf
documentation/3dprinting_files/Sealing_Corner_Joint.3mf
documentation/3dprinting_files/Sealing_Hinge.3mf
documentation/3dprinting_files/Socket_Plate.3mf
documentation/3dprinting_files/Tripod_Flang.3mf
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

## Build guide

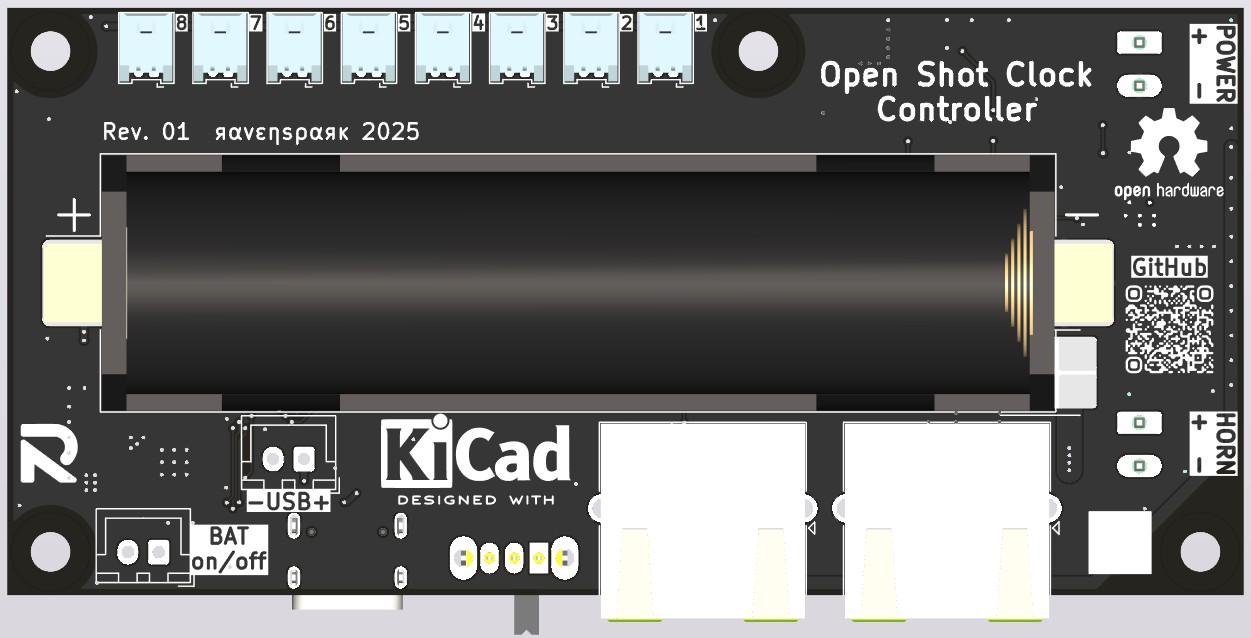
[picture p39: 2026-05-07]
pcb/controller/_print/R01/3D-Bottom.jpg

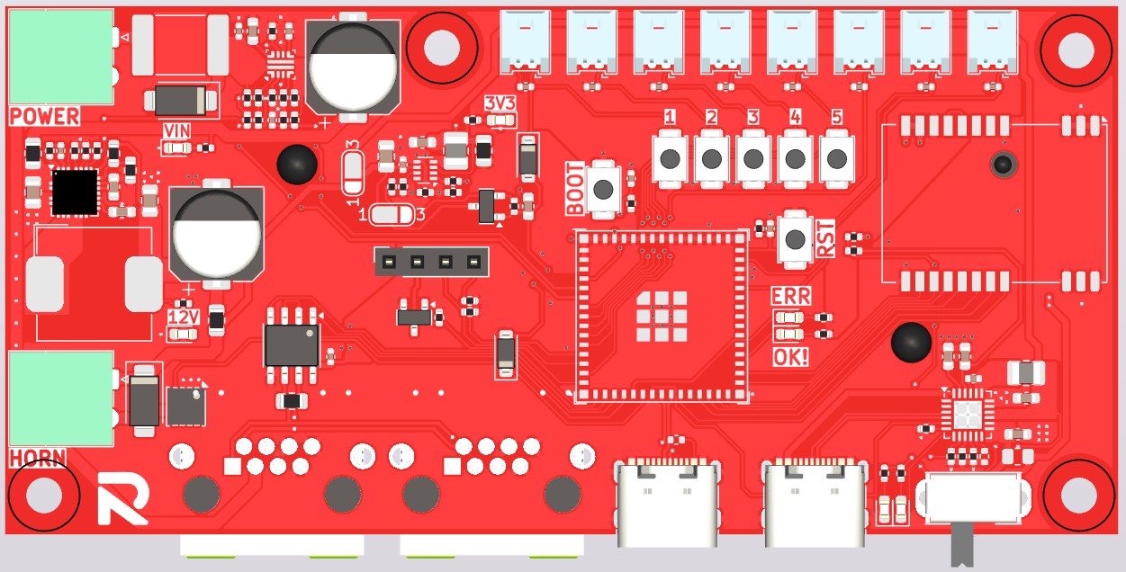
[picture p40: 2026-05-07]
pcb/controller/_print/R00/3D-Top.jpg

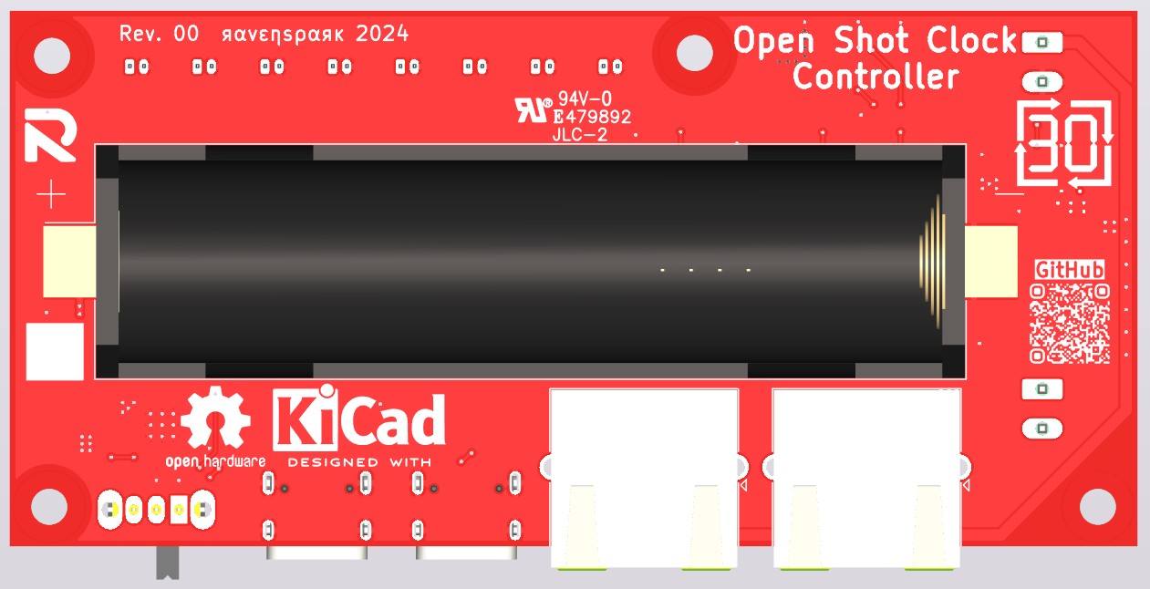
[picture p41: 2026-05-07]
pcb/controller/_print/R00/3D-Bottom.jpg

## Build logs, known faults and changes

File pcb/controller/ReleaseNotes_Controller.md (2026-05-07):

# Open Shot Clock Controller
This is the new hardware platform to build Open Shot Clock Controllers.
The functionality of all boards has been integrated into one custom PCBA. Additional safety measures for overcurrent and reverse polarity protection have been added. Power supply is possible with a single 18650 rechargeable battery or 15-24V DC power supply.
ESP32-S3-MINI is used as core with a low cost LLCC68 LoRa module.

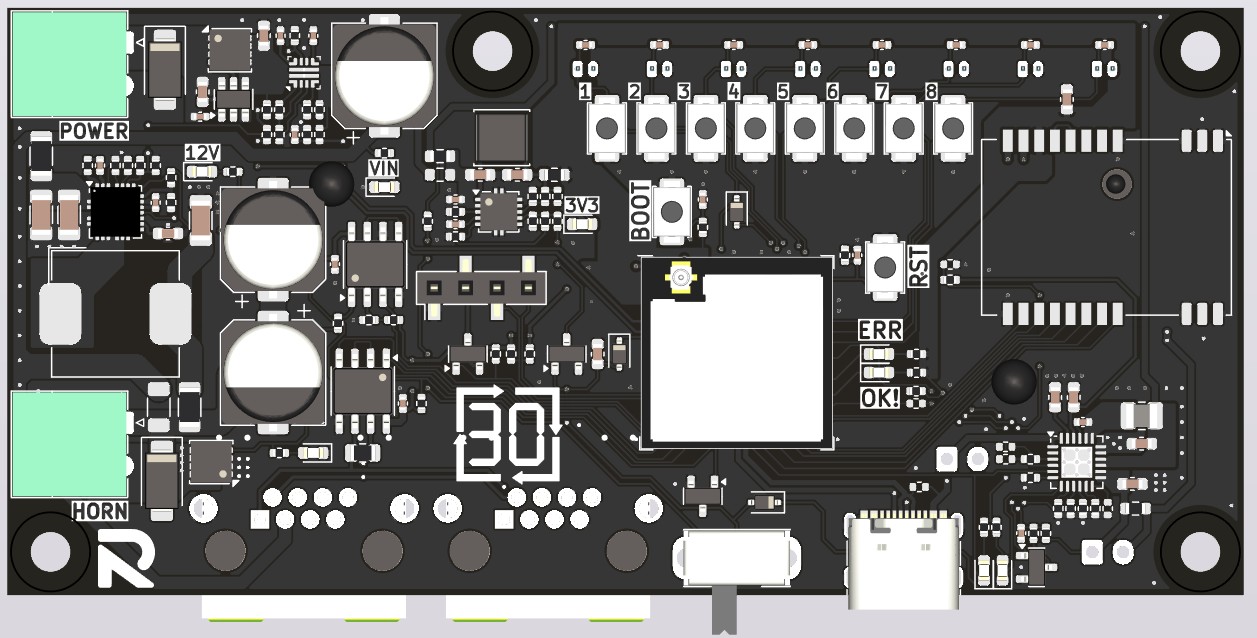
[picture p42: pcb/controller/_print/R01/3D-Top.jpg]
OSC Controller 3D


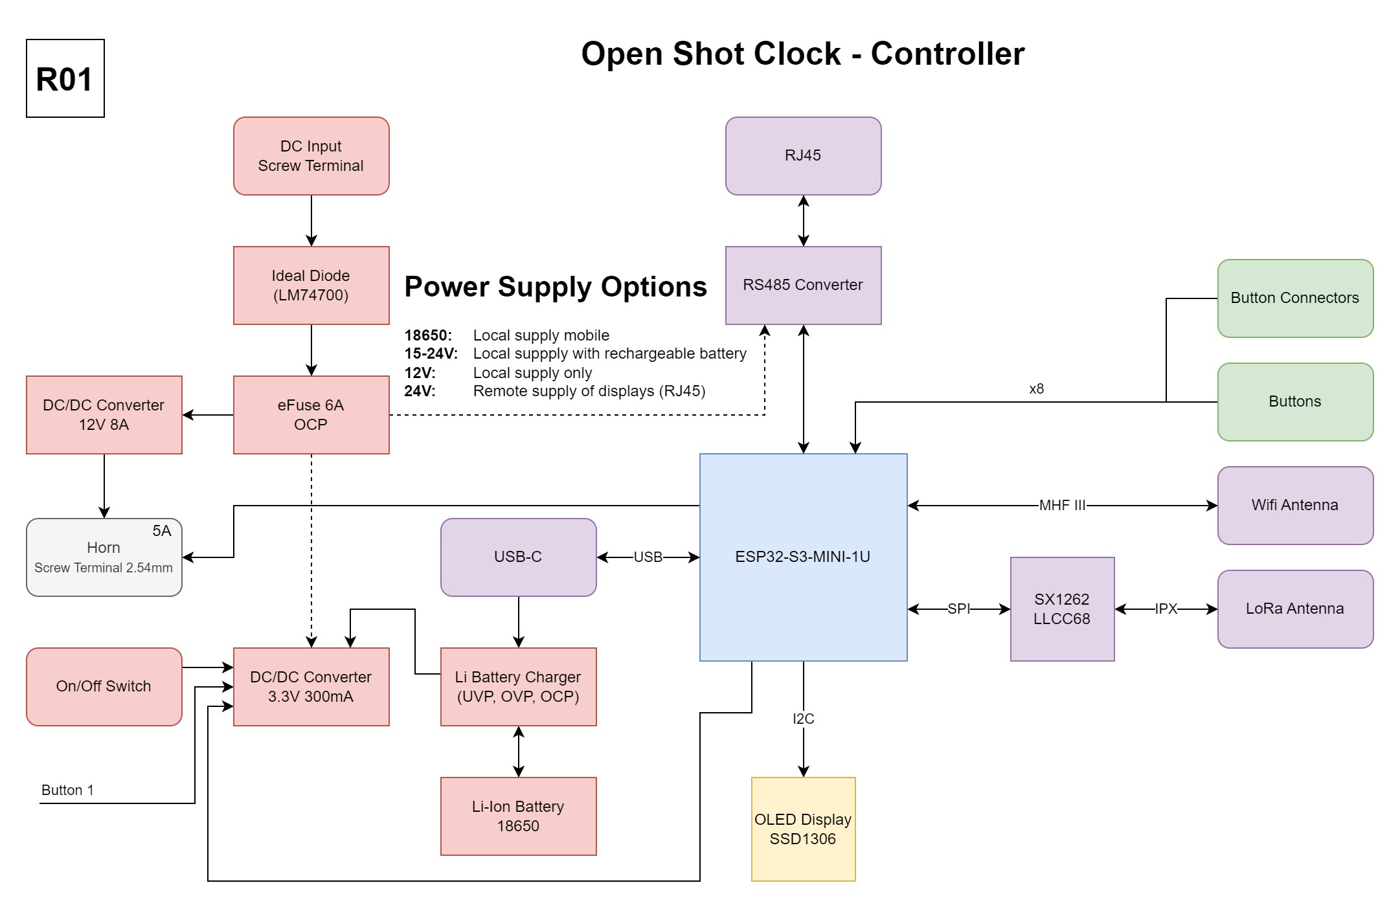
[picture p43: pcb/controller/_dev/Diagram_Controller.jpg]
OSC Controller Diagram


---
## Revision 01 (Zero Series | 2025)
Additionally to the corrections of known issues, the following functions have been added:
* Added a new wide range DC/DC for use with battery or 15-24V PSU
* Switch on by pressing button 1, plugging in USB or by switch
* Added SMD push buttons for button channels 6-8
* Added measurement of battery voltage
* Added optional JST connectors for battery switch and 5V power
* Added ideal diode as reverse polarity protection
* Adjusted eFuse configuration

### Know Issues
* Power on mechanism is not working properly, due to missing pull-down resistor on Q403.
* Voltage divider for battery voltage measurement leads to ~0.5mA leakage current into ESP32 pin.
* High series resistance of inductor leads to high dropout voltage of switching regulator.

### Patches
* Solder 10k 0603 resistor directly between pins 1-2 of Q403.
* Remove R448 or use J401 with additional power switch with R435 removed.
---
## Revision 00 (Prototype | 2024)
### Known Issues
* No isolation of main power input to RJ45 connectors. This could lead to excessive currents when two separately powered displays are connected using RJ45.
* Cheap and powerfull horns can trigger 9A OCP of DC-DC regulator.
* PG output of TPS259474x vmax is 6.5V, directly connected to VIN of SIC438BED.
* Only one set of D+/D- pins of USB-C is connected. (only works in one direction)
* Horn MOSFET switch can burn due to low gate voltage from ESP32.

### Patches
* None

### Improvements for next Release
* SIC438BED PG is not connected. Could be used as short detection on 12V rail.
* Add indication LEDs for horn output.

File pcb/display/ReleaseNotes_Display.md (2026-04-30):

# Open Shotlock Display
This is the new hardware platform to build Open Shot Clock Displays.
The functionality of all tinker boards has been integrated into one custom PCBA. Additional safety measures for overcurrent and reverse polarity protection have been added. ESP32-S3-MINI is used as core with a low cost LLCC68 LoRa module.
For development purposes, 7-Segment indication LEDs were also added.

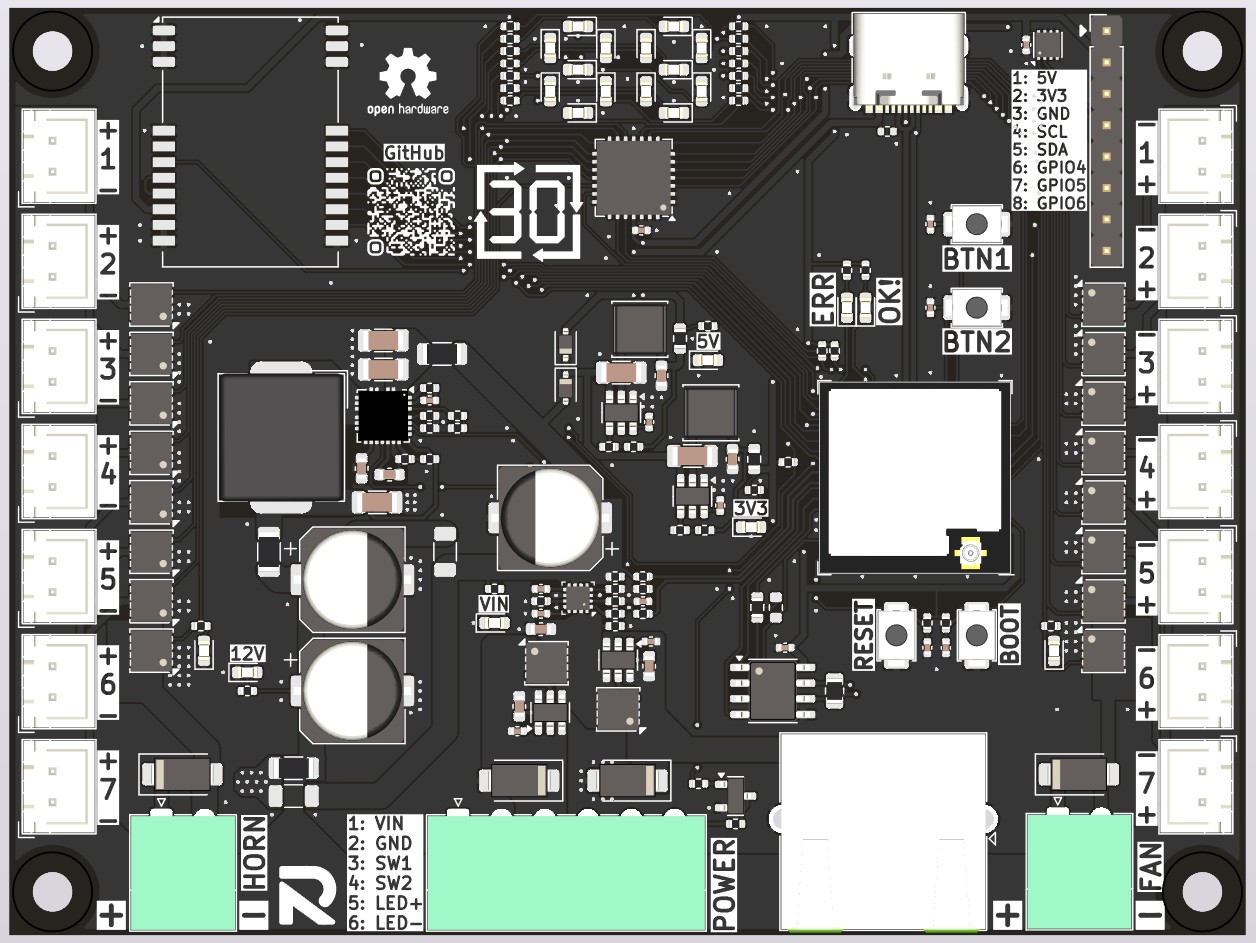
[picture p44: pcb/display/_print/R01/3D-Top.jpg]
OSC Display 3D


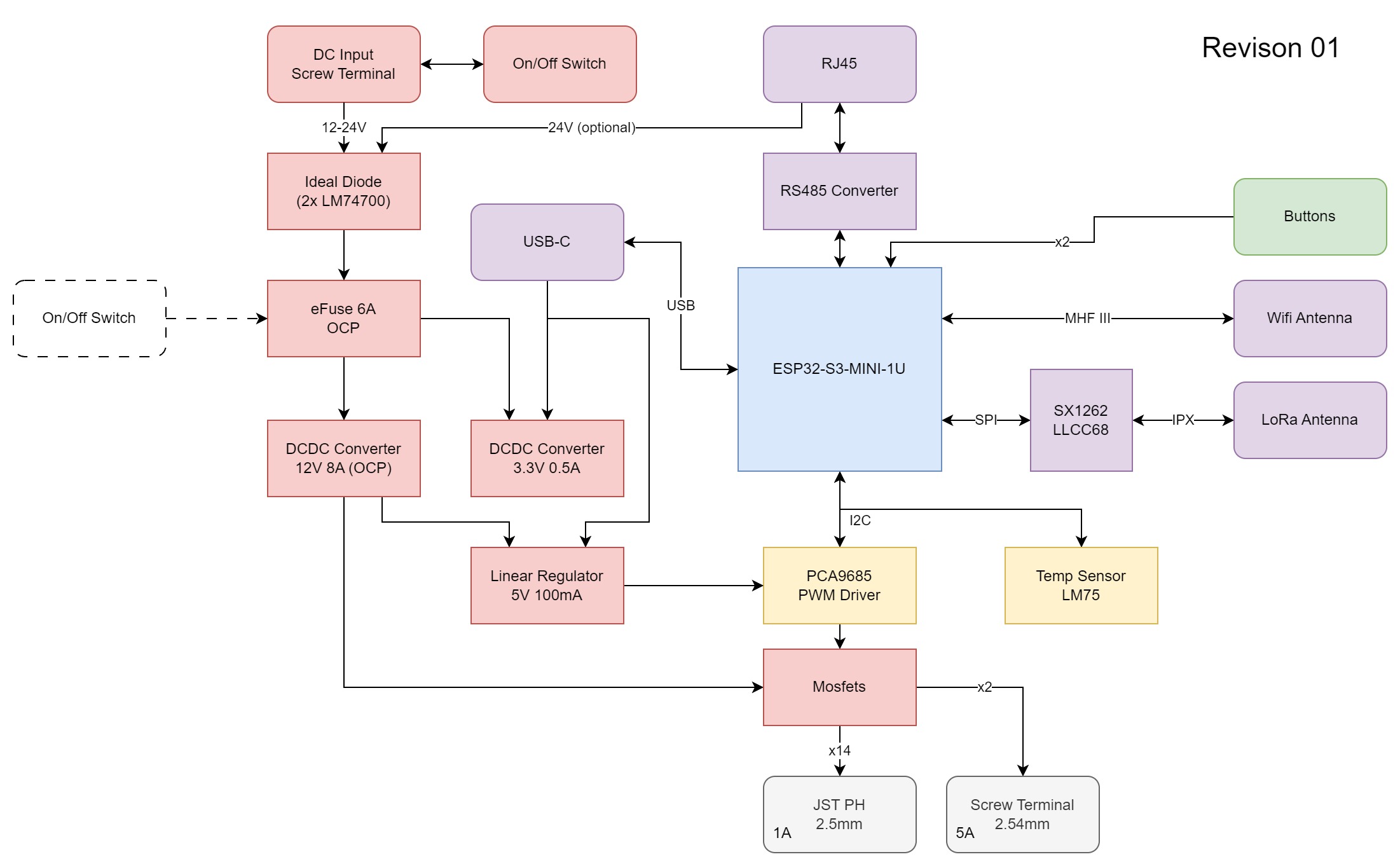
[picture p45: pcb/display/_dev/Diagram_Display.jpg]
OSC Display Diagram


## Revision 00 (Zero Series | 2025)

### Known Issues
* None

### Patches
* None

## Revision 00 (Prototypes | 2024)
### Known Issues
* No isolation of main power input to RJ45 connectors. This could lead to excessive currents when two separately powered displays are connected using RJ45.
* 7-Segment built from SMD LEDs has wrong layout (left/right part mirrored)
* Wrong footprint for RJ45 connector
* Cheap and powerfull horns can trigger 9A OCP of DC-DC regulator.
* AP2210 regulator is connected to VCC. When powering with 24V this could damage the regulator.
* PG output of TPS259474x vmax is 6.5V, directly connected to VIN of SIC438BED.
* Only one set of D+/D- pins of USB-C is connected. (only works in one direction)

### Patches
* None

### Improvements for next Release
* SIC438BED PG is not connected. Could be used as short detection on 12V rail.
* Mark polarity of LED connectors on PCB.
* Add indication LEDs for fan and horn outputs.

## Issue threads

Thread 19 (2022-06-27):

Controller: battery monitor

ChangeD20, 2022-06-27:
As a user I want to know how long the battery of the controller will last while in use. The battery status should be shown on the oled dispaly.

ChangeD20, 2023-04-25:
lipos are not longer recommended with the design of release v1.1.0

Closed 2023-04-25.

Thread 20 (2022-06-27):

Both: more reliable connection by cable for important events

ChangeD20, 2022-06-27:
As a user I want the system to be most reliable in all situations. A cable connection would be most relatable in all situations, for the daily use it is not suitable due to the downsides of the Time to be spend to setting it up, the additional costs and so on. So we make the Trade off and use LoRa wireless transmission. For important events normally last longer than a day or two and higher demand on reliability a cable option should be integrated.

ChangeD20, 2022-12-31:
Tested at Boxlacrosse EM 2022 - no issues

Closed 2022-12-31.

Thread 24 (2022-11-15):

Display-Hardware: Clash of DC Sockets/DC wires and base plate

ChangeD20, 2022-11-15:
when leave out the 3d-printed socket plates and changing the sickness of the back wall from 6mm to 4mm there is a clash between the dc sockets / dc wires and the base plate.

Option 1: milling a pocket - is difficult because there are also the screws of the led modules in the base plate

Option 2: leave out the flat connectors and solder the wires to the sockets

Option 3: change the sockets and plugs do XLR with less depth

ChangeD20, 2022-12-31:
Option 1 selected + clamping wires to connectors 180° rotated, see instructions

Closed 2022-12-31.

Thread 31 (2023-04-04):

Controller: Lipos might get damaged when not treated properly

ChangeD20, 2023-04-04:
as a user I want to be sure the shot clock I build is totally safe. When the build in lipos of the controller are not treated and used the right way there is a risk of self-ignition. Also there is a risk the relatively cheap lipos are not build properly.

-> include safety warning in instructions and recommend using only power banks instead

ChangeD20, 2023-04-25:
some controllers in current design state (and previous versions) work without lipo, some are not. Up to know it´s not clear why. The controllers are restarting frequently (about every second).

ChangeD20, 2023-04-25:
safety warning added instructions adapted in the release 1.1.0

cstatz, 2023-04-25:
> some controllers in current design state (and previous versions) work without lipo, some are not. Up to know it´s not clear why. The controllers are restarting frequently (about every second).

This issue might be related to increased current draw from the wifi/rf module.

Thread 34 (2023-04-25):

Controller: add button functionality to adjust current time

ChangeD20, 2023-04-25:
as a shot clock operator I want to be able to adjust the starting time ones to react on specific game progress.

could be done like:

-long press one button until time change mode is entered (one of the upper or lower middle button?)
-increasing or decreasing time by one each press the button left or right of the initial button
-press middle button again to leave change mode

ChangeD20, 2023-04-25:
maybe add permanent start time functionality as well (other middle button) in addition to this functionality by the web application

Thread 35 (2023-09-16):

Set PCA9685 output PWM to 5V

devdrik, 2023-09-16:
Some Mosfet modules do not work good with 3.3V input, but they all work with 5V input. Changing the Output to 5V means just connecting VCC of the PCA to 5V instead of 3.3V. Nothing else should be affected.

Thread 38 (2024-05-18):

Display PCB - mosfet uprgrad (pcb upgrade)

ChangeD20, 2024-05-18:
Using New Typ of mosfet has advantages:
- Cheaper
- Can be soldered removable with male and female pin headers (change in case of failure possible)

To be integrated in new pcb design

Having both options on one pcb - new and old mosfets - to be considered in design process

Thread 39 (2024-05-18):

Display PCB - design software running out (pcb redesign)

ChangeD20, 2024-05-18:
Used pcb design software is running out. Design to be ported to an other software (freeware) to make future changes and maintainance possible.

Pcb should be redesigned in the process to resolve current issues (labeled with "pcb redesign")

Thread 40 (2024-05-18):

Display PCB - RS485 cannot be removed easily in case of failure (pcb redesign)

ChangeD20, 2024-05-18:
Pin holes on pcb are to small for female pin headers. Make pin holes bigger to use male and female pin headers. In case of failure the rs485 modules would be removable easily to change them.

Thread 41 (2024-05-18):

Display PCB - all connectors on one side (pcb redesign)

ChangeD20, 2024-05-18:
To disconnect the pcb from all peripheral components easily all connectors should be located on one side so only one side of the frame has to be removed to remove the base plate for maintainance

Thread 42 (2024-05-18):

Display Hardware - 18v battery option to be developed (pcb redesign)

ChangeD20, 2024-05-18:
Current issues:
- Horn out of function when battery is below half charge

Advantages:
- Reduce costs (battery and other peripheral components like cables/connectors)
- 18v battery's (like for drills) have much more power, step down ensures 12v supply over longer time while battery voltages decrease while in operation

New components
- 18v batteries
- Connector for batteries
- fuse and fuse holder (had been integrated in the cable before)
- Step down to 12v
- Additional mosfet/relay for using the horn directly with 18v
- heavy duty switch

Pcb resdesign:
Design decisions to be made
- additional mosfet as peripheral or on pcb
- Changes to the connectors to be made? (Heavy duty switch and mosfet for 18v horn on pcb or peripheral)

MOSFET decision on type / model - to be tested

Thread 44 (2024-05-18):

Display PCB - additional pin Header rows for Lora 32 do not match a common grid size

ChangeD20, 2024-05-18:
Change the position of the pin headers
- Wider ( enough space to fit a esp32 d1 mini in between the raws on an custom pcb) -> makes future test for cost reduction easier
- Move them on the same height as the pin of the lora32

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

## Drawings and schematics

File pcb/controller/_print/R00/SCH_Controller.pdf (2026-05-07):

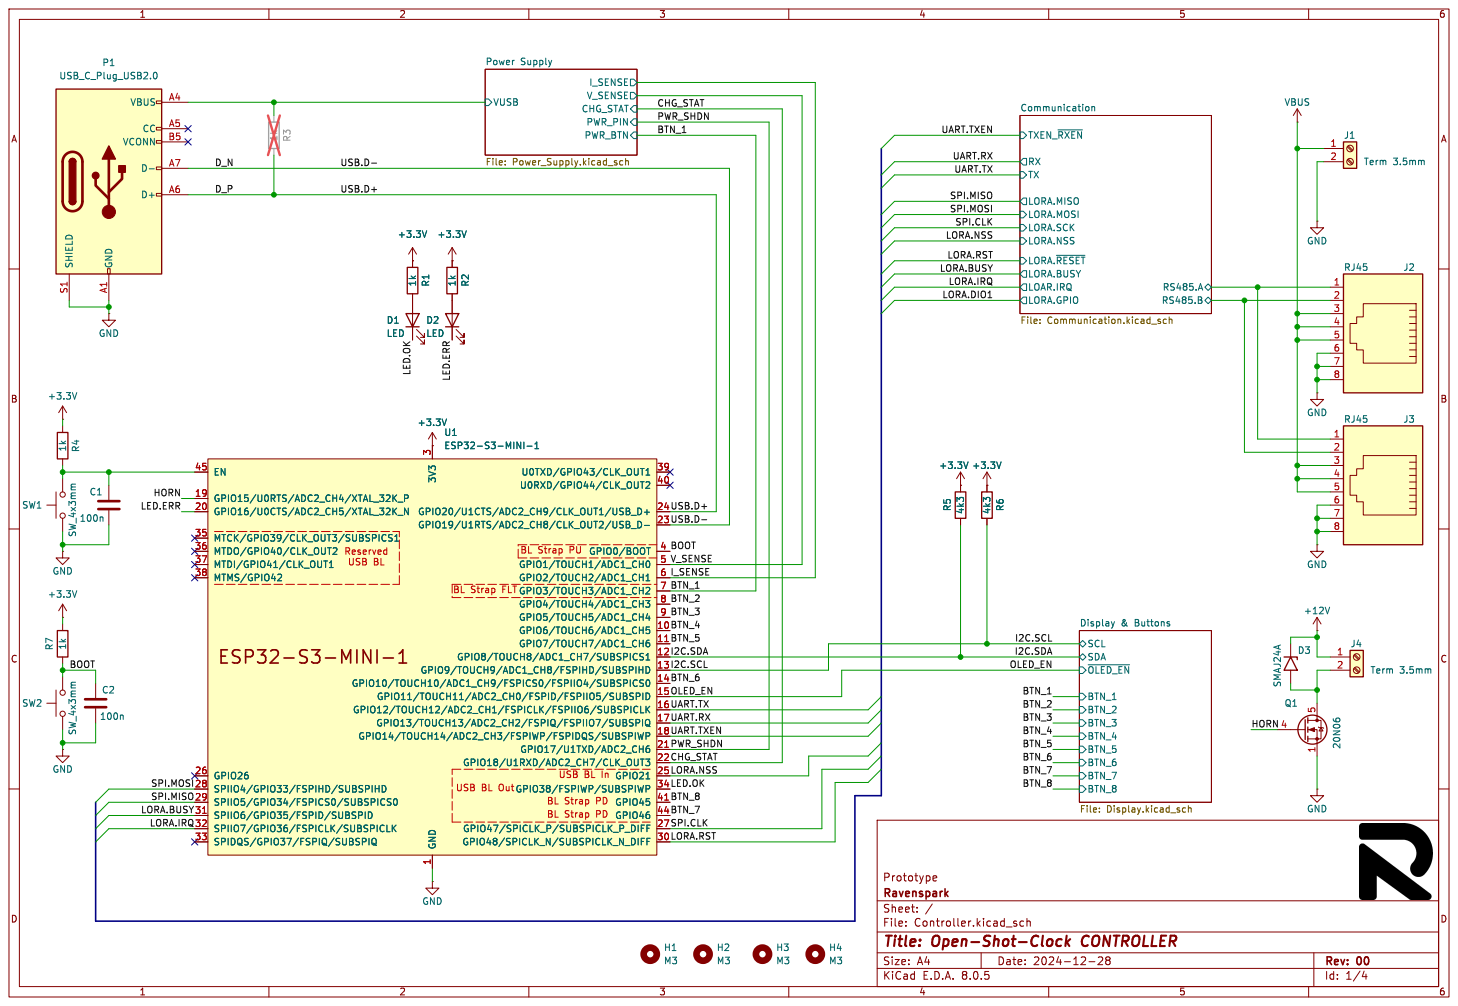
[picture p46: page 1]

TXEN_~{RXEN} Communication File: Communication.kicad_sch C2

UART.RX UART.TXEN

LORA.MISO
LORA.MOSI LORA.~{RESET} LORA.SCK

LORA.RST SPI.CLK
LORA.NSS

3 GPIO48/SPICLK_N/SUBSPICLK_N_DIFF 30 SPIIO6/GPIO35/FSPID/SUBSPID 31 SPIIO7/GPIO36/FSPICLK/SUBSPICLK 32 SPIDQS/GPIO37/FSPIQ/SUBSPIQ 33 GPIO38/FSPIWP/SUBSPIWP 34 MTCK/GPIO39/CLK_OUT3/SUBSPICS1 35 MTDO/GPIO40/CLK_OUT2 36 MTDI/GPIO41/CLK_OUT1 37 MTMS/GPIO42 38 U0TXD/GPIO43/CLK_OUT1 39 GPIO0/BOOT 4 U0RXD/GPIO44/CLK_OUT2 40 GPIO45 41 GPIO46 44 EN 45 GPIO1/TOUCH1/ADC1_CH0 5 GPIO2/TOUCH2/ADC1_CH1 6 GPIO3/TOUCH3/ADC1_CH2 7 GPIO4/TOUCH4/ADC1_CH3 8 GPIO5/TOUCH5/ADC1_CH4 9 U1ESP32-S3-MINI-1 GND

3 GPIO48/SPICLK_N/SUBSPICLK_N_DIFF 30 SPIIO6/GPIO35/FSPID/SUBSPID 31 SPIIO7/GPIO36/FSPICLK/SUBSPICLK 32 SPIDQS/GPIO37/FSPIQ/SUBSPIQ 33 GPIO38/FSPIWP/SUBSPIWP 34 MTCK/GPIO39/CLK_OUT3/SUBSPICS1 35 MTDO/GPIO40/CLK_OUT2 36 MTDI/GPIO41/CLK_OUT1 37 MTMS/GPIO42 38 U0TXD/GPIO43/CLK_OUT1 39 GPIO0/BOOT 4 U0RXD/GPIO44/CLK_OUT2 40 GPIO45 41 GPIO46 44 EN 45 GPIO1/TOUCH1/ADC1_CH0 5 GPIO2/TOUCH2/ADC1_CH1 6 GPIO3/TOUCH3/ADC1_CH2 7 GPIO4/TOUCH4/ADC1_CH3 8 GPIO5/TOUCH5/ADC1_CH4 9 +3.3VR5 4k3 R6 4k3 +3.3V

1 GPIO6/TOUCH6/ADC1_CH5 10 GPIO7/TOUCH7/ADC1_CH6 11 GPIO8/TOUCH8/ADC1_CH7/SUBSPICS1 12 GPIO9/TOUCH9/ADC1_CH8/FSPIHD/SUBSPIHD 13 GPIO10/TOUCH10/ADC1_CH9/FSPICS0/FSPIIO4/SUBSPICS0 14 GPIO11/TOUCH11/ADC2_CH0/FSPID/FSPIIO5/SUBSPID 15 GPIO12/TOUCH12/ADC2_CH1/FSPICLK/FSPIIO6/SUBSPICLK 16 GPIO13/TOUCH13/ADC2_CH2/FSPIQ/FSPIIO7/SUBSPIQ 17 GPIO14/TOUCH14/ADC2_CH3/FSPIWP/FSPIDQS/SUBSPIWP 18 GPIO15/U0RTS/ADC2_CH4/XTAL_32K_P 19 GPIO16/U0CTS/ADC2_CH5/XTAL_32K_N 20 GPIO17/U1TXD/ADC2_CH6 21 GPIO18/U1RXD/ADC2_CH7/CLK_OUT3 22 GPIO19/U1RTS/ADC2_CH8/CLK_OUT2/USB_D- 23 GPIO20/U1CTS/ADC2_CH9/CLK_OUT1/USB_D+ 24 GPIO21 25 GPIO26 26 GPIO47/SPICLK_P/SUBSPICLK_P_DIFF 27 SPIIO4/GPIO33/FSPIHD/SUBSPIHD 28 SPIIO5/GPIO34/FSPICS0/SUBSPICS0 29 3V3

USB BL In BL Strap FLT

Display & Buttons File: Display.kicad_sch
BTN_7 BTN_3 BTN_2 BTN_1 BTN_5 BTN_6 BTN_4 BTN_8 ~{OLED_EN}

File: Controller.kicad_sch Sheet: / Ravenspark

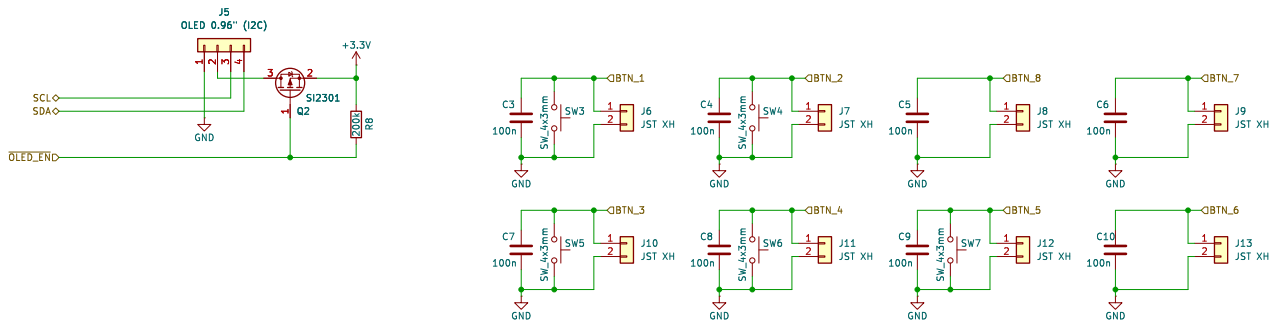
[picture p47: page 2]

Id: 2/4 Title: Display & Buttons

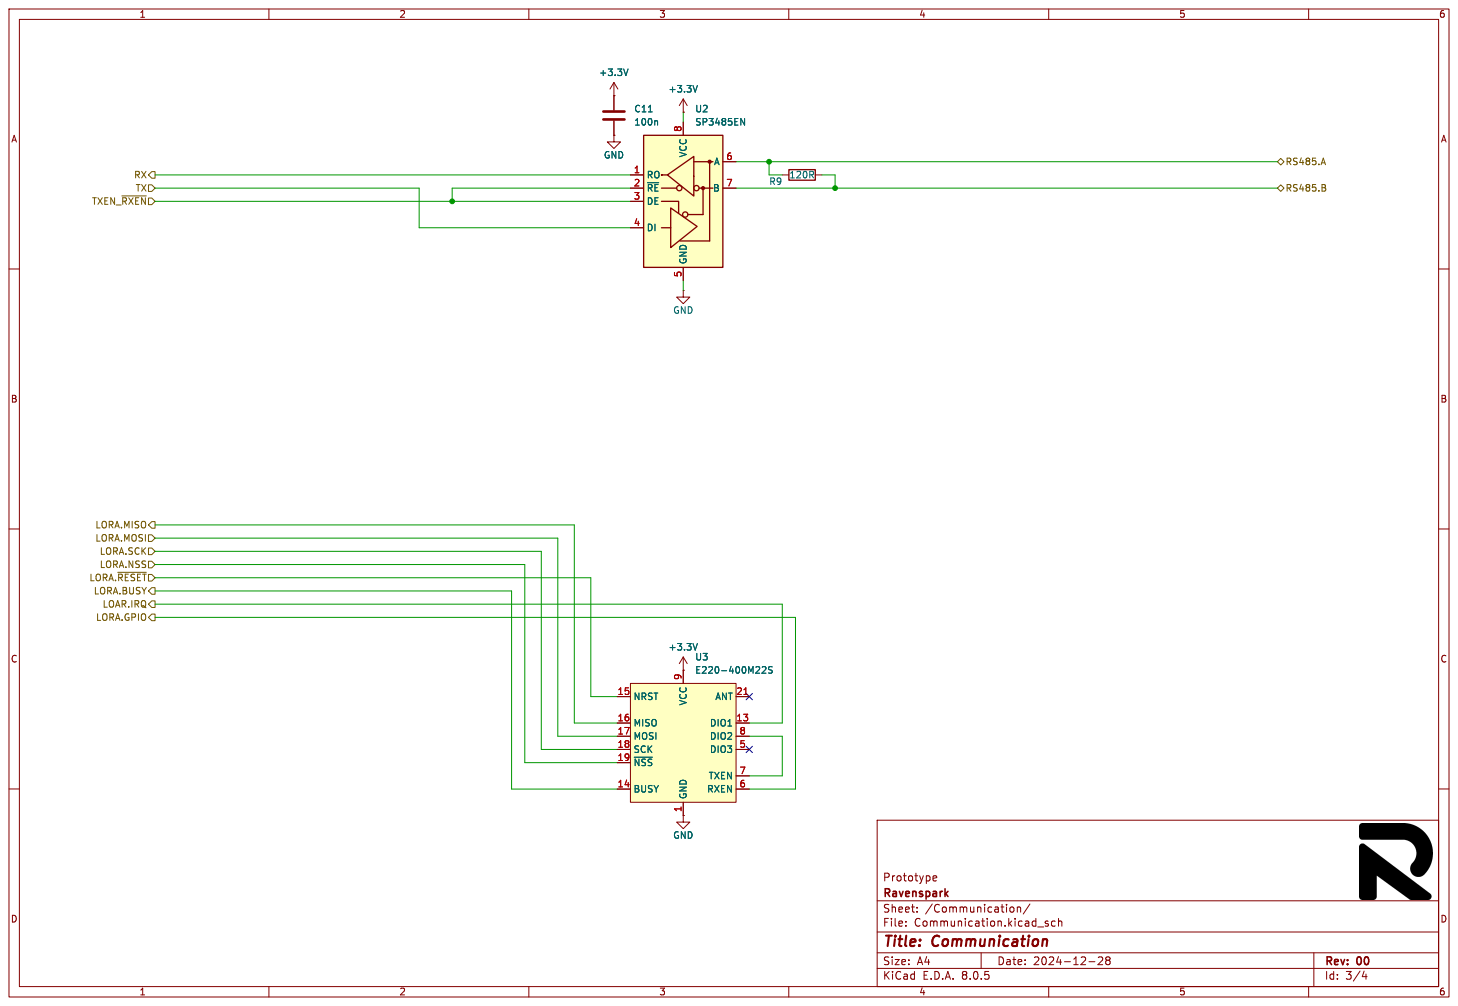
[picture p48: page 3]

LORA.MISO
LORA.MOSI LORA.GPIO
LORA.SCK
LORA.NSS
LORA.~{RESET}
LORA.BUSY
LOAR.IRQ

Prototype
File: Communication.kicad_sch Sheet: /Communication/ Ravenspark

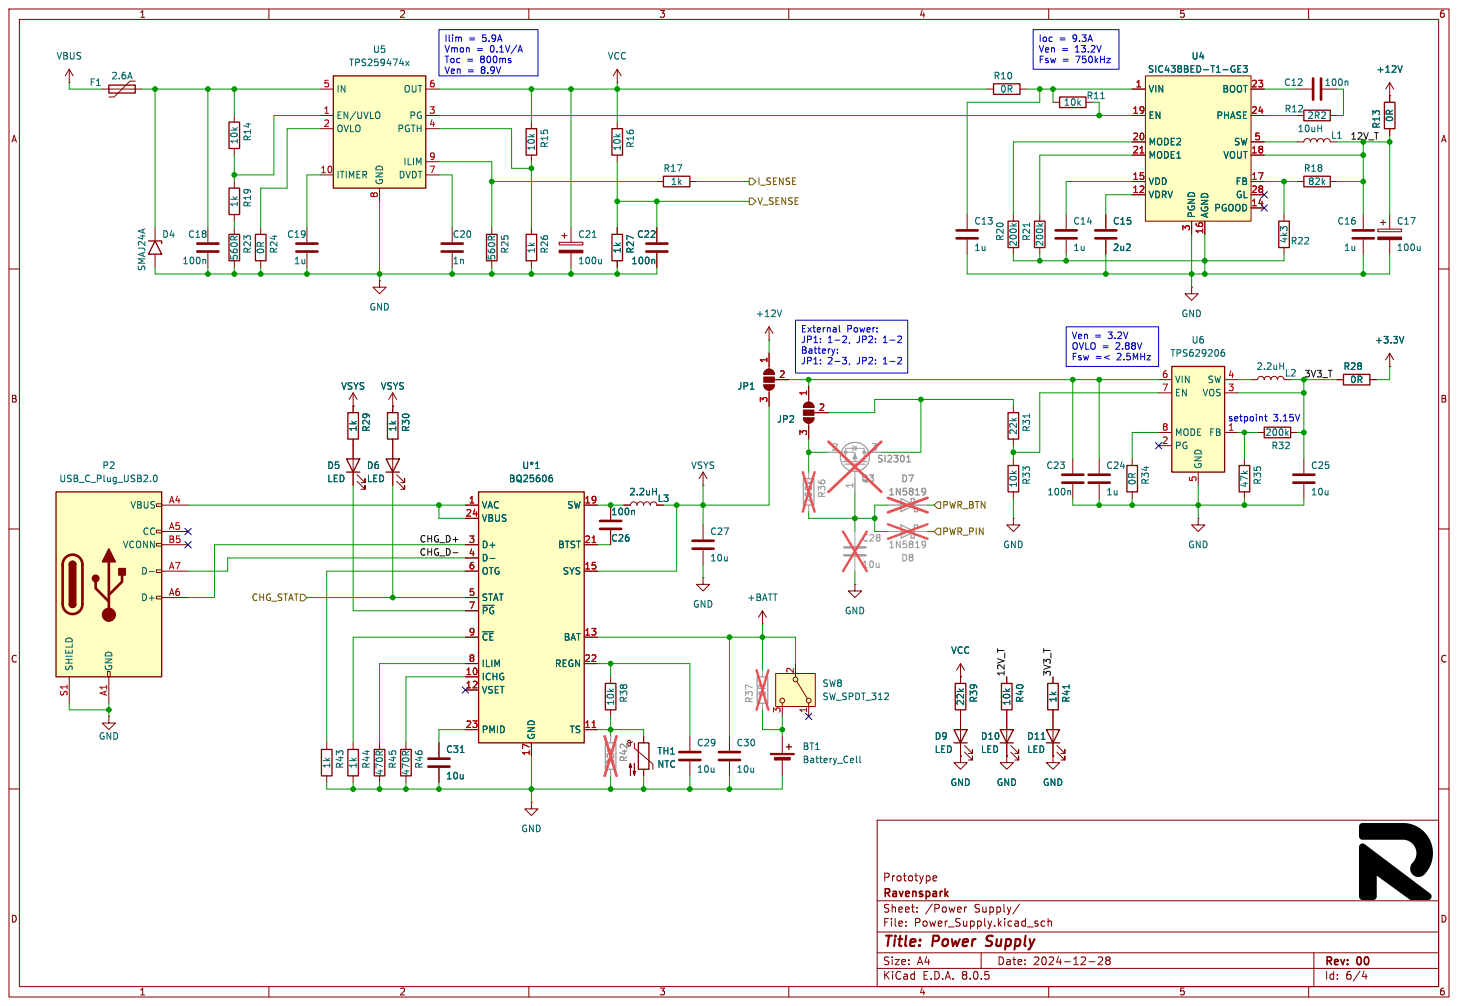
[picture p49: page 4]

Ravenspark
Id: 6/4 Title: Power Supply

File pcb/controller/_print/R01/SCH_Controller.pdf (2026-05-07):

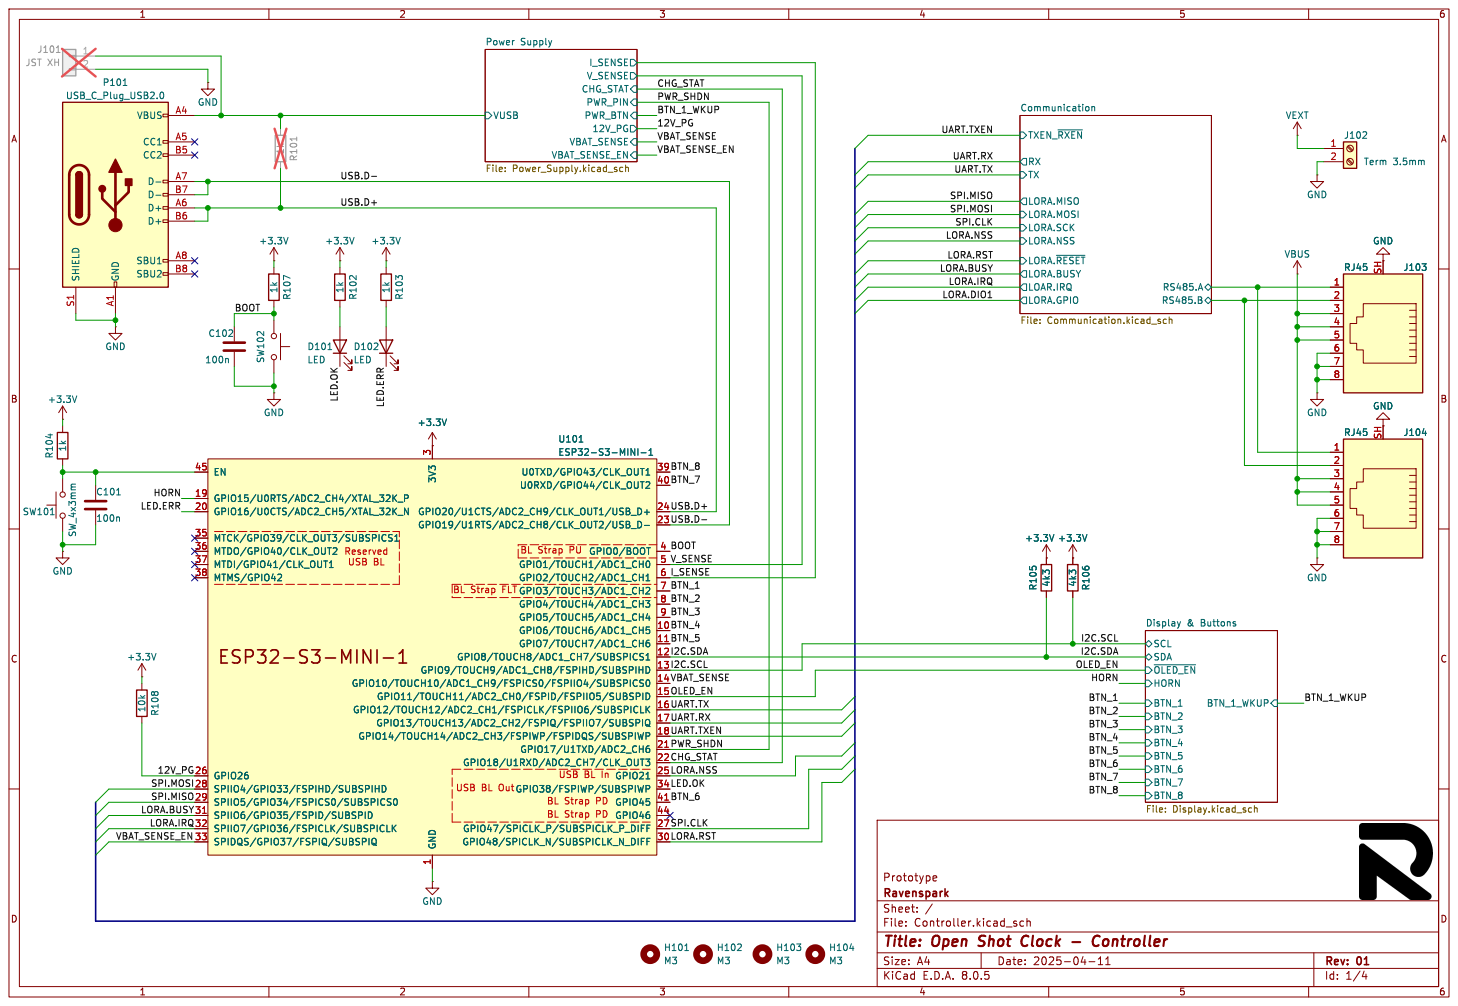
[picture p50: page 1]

SPI.MOSI UART.TX UART.RX

LORA.MISO
LORA.MOSI LORA.~{RESET} LORA.SCK

3 GPIO48/SPICLK_N/SUBSPICLK_N_DIFF 30 SPIIO6/GPIO35/FSPID/SUBSPID 31 SPIIO7/GPIO36/FSPICLK/SUBSPICLK 32 SPIDQS/GPIO37/FSPIQ/SUBSPIQ 33 GPIO38/FSPIWP/SUBSPIWP 34 MTCK/GPIO39/CLK_OUT3/SUBSPICS1 35 MTDO/GPIO40/CLK_OUT2 36 MTDI/GPIO41/CLK_OUT1 37 MTMS/GPIO42 38 U0TXD/GPIO43/CLK_OUT1 39 GPIO0/BOOT 4 U0RXD/GPIO44/CLK_OUT2 40 GPIO45 41 GPIO46 44 EN 45 GPIO1/TOUCH1/ADC1_CH0 5 GPIO2/TOUCH2/ADC1_CH1 6 GPIO3/TOUCH3/ADC1_CH2 7 GPIO4/TOUCH4/ADC1_CH3 8 GPIO5/TOUCH5/ADC1_CH4 9 U101 ESP32-S3-MINI-1 R103 1k +3.3V GND R105 4k3

3 GPIO48/SPICLK_N/SUBSPICLK_N_DIFF 30 SPIIO6/GPIO35/FSPID/SUBSPID 31 SPIIO7/GPIO36/FSPICLK/SUBSPICLK 32 SPIDQS/GPIO37/FSPIQ/SUBSPIQ 33 GPIO38/FSPIWP/SUBSPIWP 34 MTCK/GPIO39/CLK_OUT3/SUBSPICS1 35 MTDO/GPIO40/CLK_OUT2 36 MTDI/GPIO41/CLK_OUT1 37 MTMS/GPIO42 38 U0TXD/GPIO43/CLK_OUT1 39 GPIO0/BOOT 4 U0RXD/GPIO44/CLK_OUT2 40 GPIO45 41 GPIO46 44 EN 45 GPIO1/TOUCH1/ADC1_CH0 5 GPIO2/TOUCH2/ADC1_CH1 6 GPIO3/TOUCH3/ADC1_CH2 7 GPIO4/TOUCH4/ADC1_CH3 8 GPIO5/TOUCH5/ADC1_CH4 9 +3.3V RJ45 J104

1 GPIO6/TOUCH6/ADC1_CH5 10 GPIO7/TOUCH7/ADC1_CH6 11 GPIO8/TOUCH8/ADC1_CH7/SUBSPICS1 12 GPIO9/TOUCH9/ADC1_CH8/FSPIHD/SUBSPIHD 13 GPIO10/TOUCH10/ADC1_CH9/FSPICS0/FSPIIO4/SUBSPICS0 14 GPIO11/TOUCH11/ADC2_CH0/FSPID/FSPIIO5/SUBSPID 15 GPIO12/TOUCH12/ADC2_CH1/FSPICLK/FSPIIO6/SUBSPICLK 16 GPIO13/TOUCH13/ADC2_CH2/FSPIQ/FSPIIO7/SUBSPIQ 17 GPIO14/TOUCH14/ADC2_CH3/FSPIWP/FSPIDQS/SUBSPIWP 18 GPIO15/U0RTS/ADC2_CH4/XTAL_32K_P 19 GPIO16/U0CTS/ADC2_CH5/XTAL_32K_N 20 GPIO17/U1TXD/ADC2_CH6 21 GPIO18/U1RXD/ADC2_CH7/CLK_OUT3 22 GPIO19/U1RTS/ADC2_CH8/CLK_OUT2/USB_D- 23 GPIO20/U1CTS/ADC2_CH9/CLK_OUT1/USB_D+ 24 GPIO21 25 GPIO26 26 GPIO47/SPICLK_P/SUBSPICLK_P_DIFF 27 SPIIO4/GPIO33/FSPIHD/SUBSPIHD 28 SPIIO5/GPIO34/FSPICS0/SUBSPICS0 29 3V3

Prototype
Id: 1/4 Title: Open Shot Clock - Controller File: Controller.kicad_sch Sheet: / Ravenspark

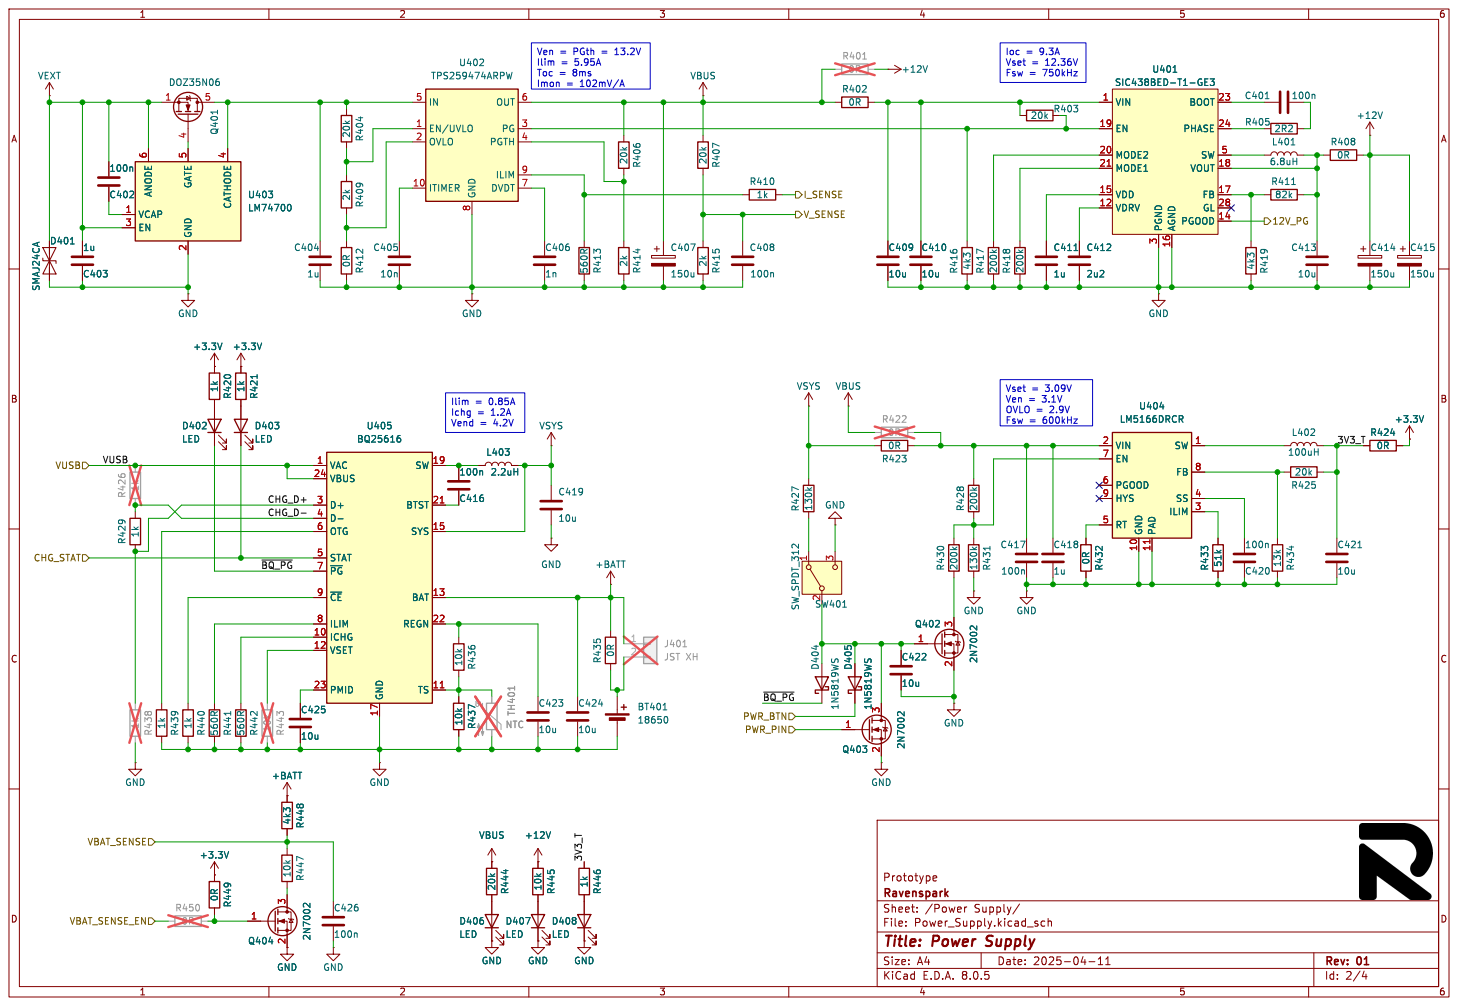
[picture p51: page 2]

Prototype
Ravenspark
Id: 2/4 Title: Power Supply

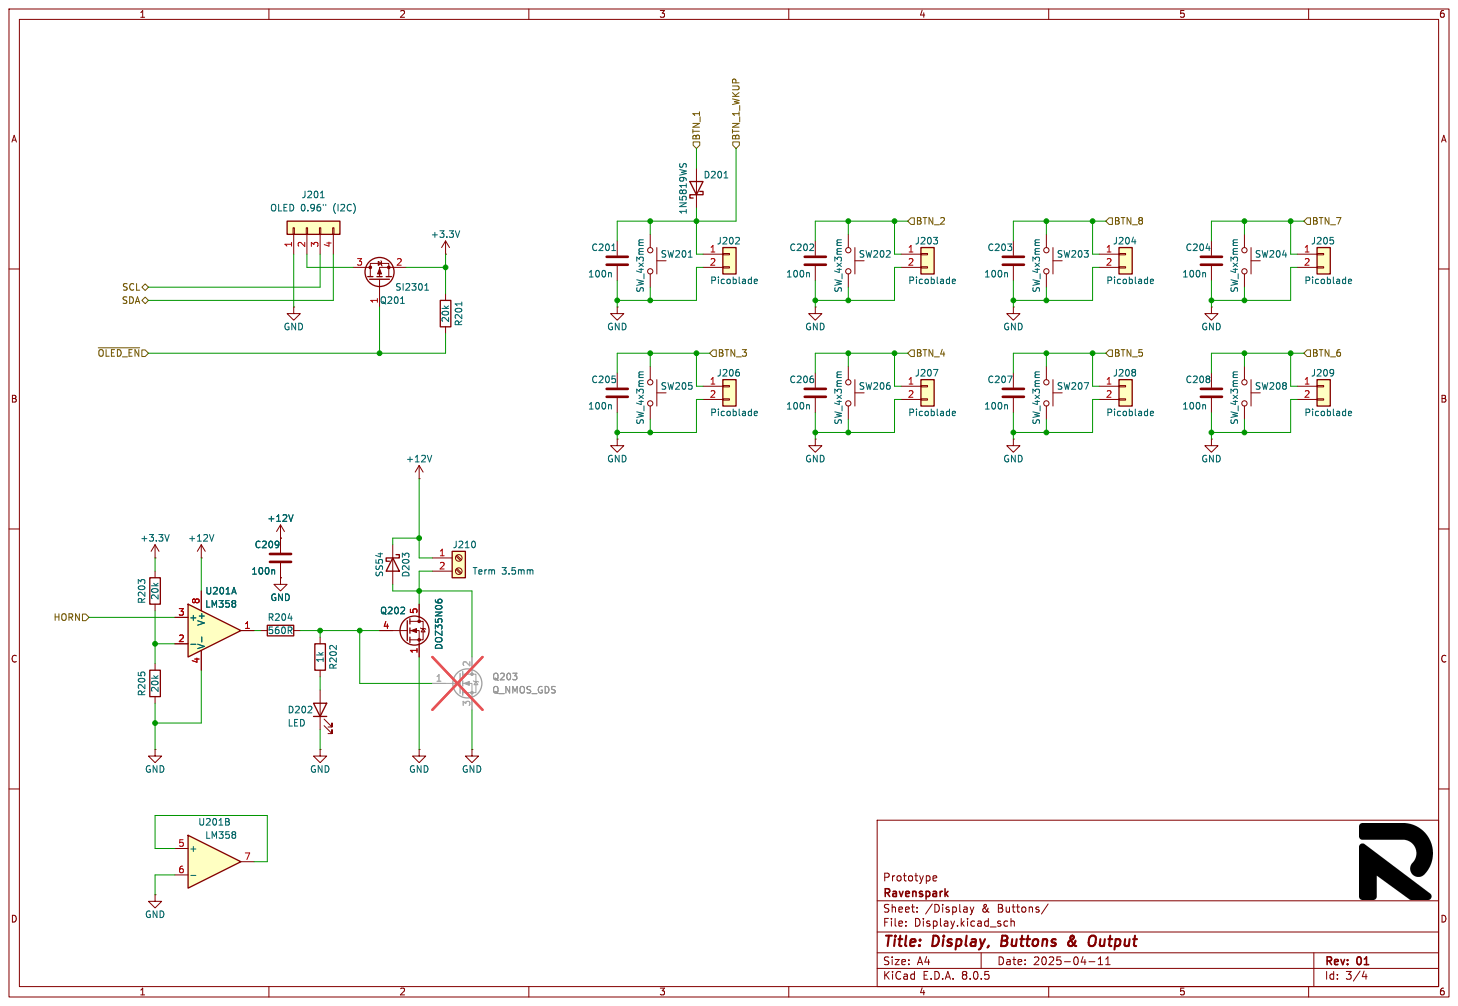
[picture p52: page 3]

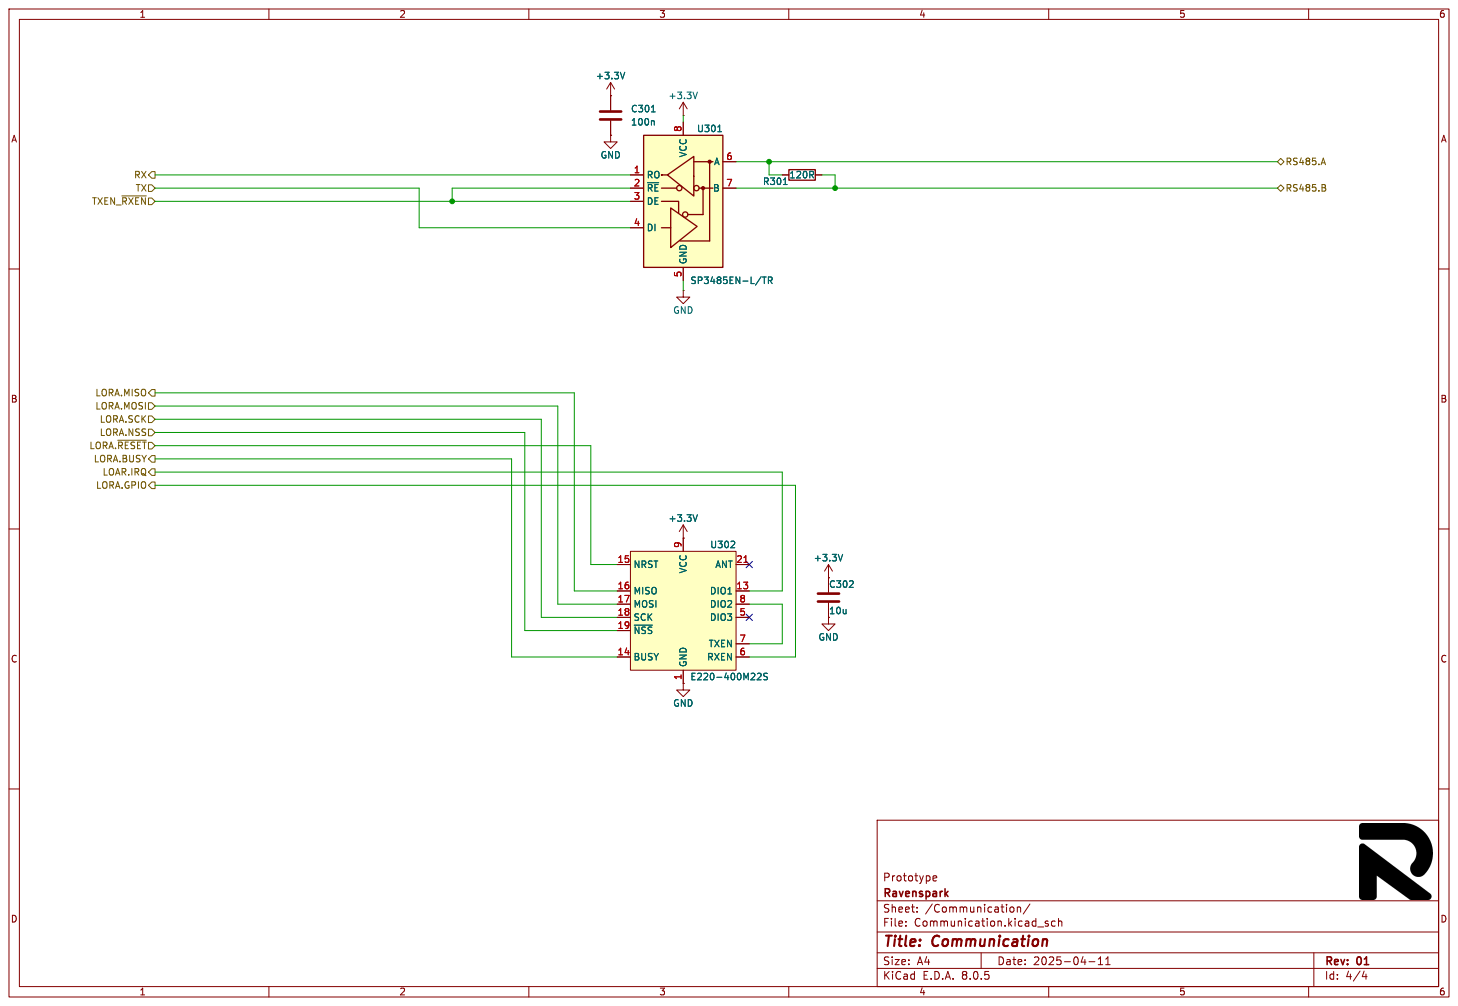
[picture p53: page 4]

LORA.MOSI LORA.MISO

LORA.SCK
LORA.NSS
LORA.~{RESET} LOAR.IRQ
LORA.BUSY

Prototype
File: Communication.kicad_sch Sheet: /Communication/ Ravenspark

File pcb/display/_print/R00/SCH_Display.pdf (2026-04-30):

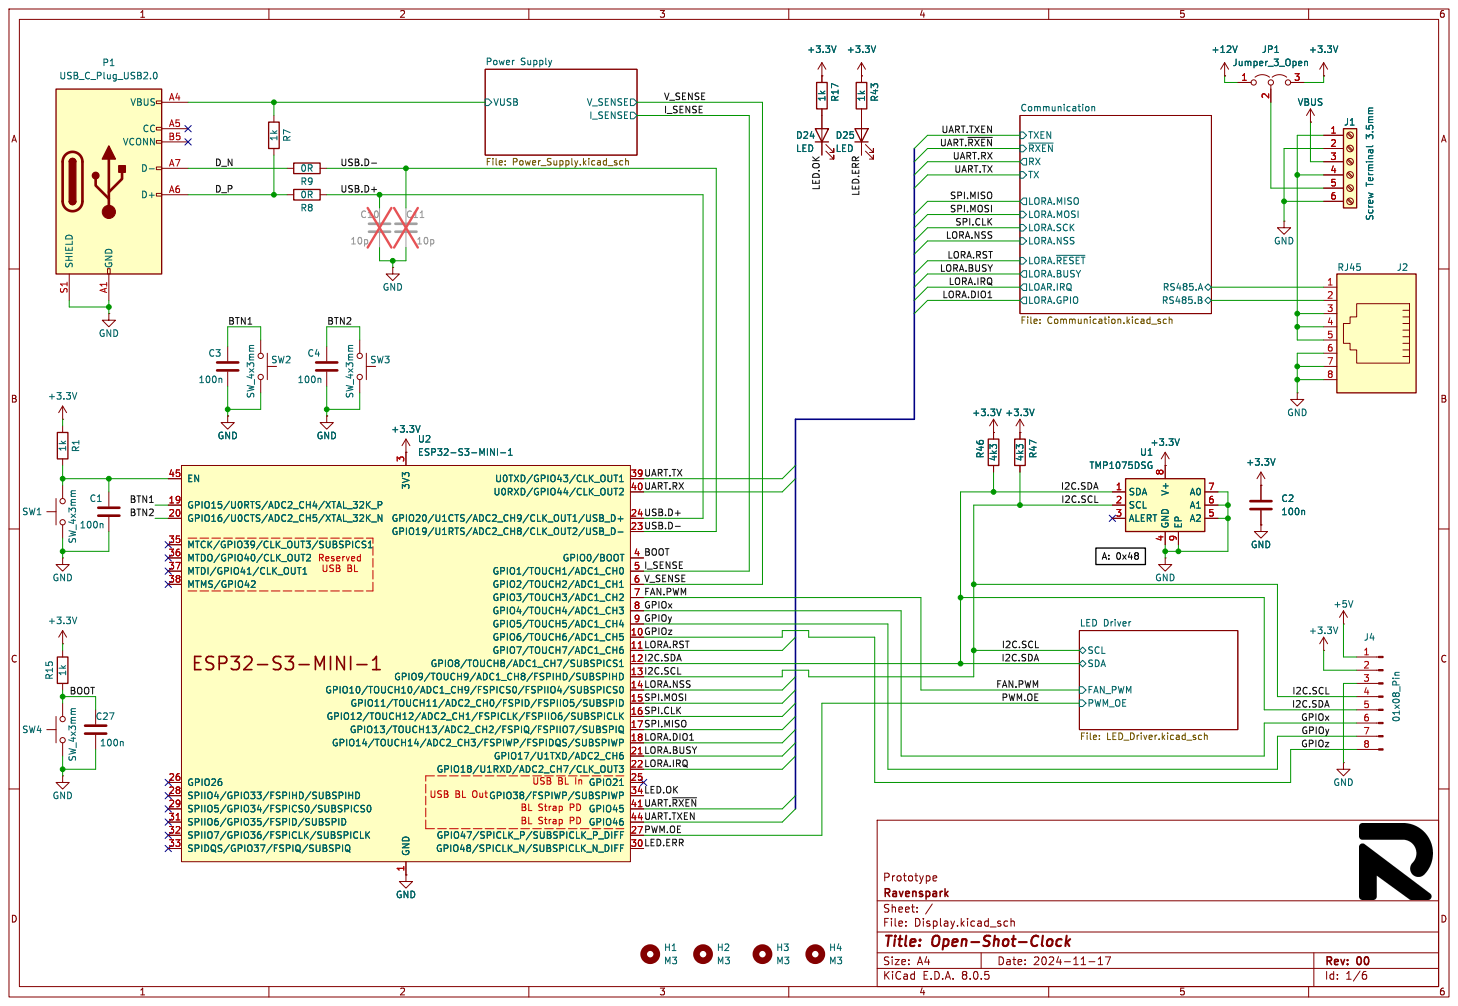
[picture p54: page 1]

SPI.CLK UART.TXEN
UART.~{RXEN} UART.RX

LORA.MISO
LORA.MOSI LORA.~{RESET} LORA.SCK

3 GPIO48/SPICLK_N/SUBSPICLK_N_DIFF 30 SPIIO6/GPIO35/FSPID/SUBSPID 31 SPIIO7/GPIO36/FSPICLK/SUBSPICLK 32 SPIDQS/GPIO37/FSPIQ/SUBSPIQ 33 GPIO38/FSPIWP/SUBSPIWP 34 MTCK/GPIO39/CLK_OUT3/SUBSPICS1 35 MTDO/GPIO40/CLK_OUT2 36 MTDI/GPIO41/CLK_OUT1 37 MTMS/GPIO42 38 U0TXD/GPIO43/CLK_OUT1 39 GPIO0/BOOT 4 U0RXD/GPIO44/CLK_OUT2 40 GPIO45 41 GPIO46 44 EN 45 GPIO1/TOUCH1/ADC1_CH0 5 GPIO2/TOUCH2/ADC1_CH1 6 GPIO3/TOUCH3/ADC1_CH2 7 GPIO4/TOUCH4/ADC1_CH3 8 GPIO5/TOUCH5/ADC1_CH4 9 +3.3V R47 4k3 +3.3VR46 4k3 +3.3V

3 GPIO48/SPICLK_N/SUBSPICLK_N_DIFF 30 SPIIO6/GPIO35/FSPID/SUBSPID 31 SPIIO7/GPIO36/FSPICLK/SUBSPICLK 32 SPIDQS/GPIO37/FSPIQ/SUBSPIQ 33 GPIO38/FSPIWP/SUBSPIWP 34 MTCK/GPIO39/CLK_OUT3/SUBSPICS1 35 MTDO/GPIO40/CLK_OUT2 36 MTDI/GPIO41/CLK_OUT1 37 MTMS/GPIO42 38 U0TXD/GPIO43/CLK_OUT1 39 GPIO0/BOOT 4 U0RXD/GPIO44/CLK_OUT2 40 GPIO45 41 GPIO46 44 EN 45 GPIO1/TOUCH1/ADC1_CH0 5 GPIO2/TOUCH2/ADC1_CH1 6 GPIO3/TOUCH3/ADC1_CH2 7 GPIO4/TOUCH4/ADC1_CH3 8 GPIO5/TOUCH5/ADC1_CH4 9 U2ESP32-S3-MINI-1 GND

1 GPIO6/TOUCH6/ADC1_CH5 10 GPIO7/TOUCH7/ADC1_CH6 11 GPIO8/TOUCH8/ADC1_CH7/SUBSPICS1 12 GPIO9/TOUCH9/ADC1_CH8/FSPIHD/SUBSPIHD 13 GPIO10/TOUCH10/ADC1_CH9/FSPICS0/FSPIIO4/SUBSPICS0 14 GPIO11/TOUCH11/ADC2_CH0/FSPID/FSPIIO5/SUBSPID 15 GPIO12/TOUCH12/ADC2_CH1/FSPICLK/FSPIIO6/SUBSPICLK 16 GPIO13/TOUCH13/ADC2_CH2/FSPIQ/FSPIIO7/SUBSPIQ 17 GPIO14/TOUCH14/ADC2_CH3/FSPIWP/FSPIDQS/SUBSPIWP 18 GPIO15/U0RTS/ADC2_CH4/XTAL_32K_P 19 GPIO16/U0CTS/ADC2_CH5/XTAL_32K_N 20 GPIO17/U1TXD/ADC2_CH6 21 GPIO18/U1RXD/ADC2_CH7/CLK_OUT3 22 GPIO19/U1RTS/ADC2_CH8/CLK_OUT2/USB_D- 23 GPIO20/U1CTS/ADC2_CH9/CLK_OUT1/USB_D+ 24 GPIO21 25 GPIO26 26 GPIO47/SPICLK_P/SUBSPICLK_P_DIFF 27 SPIIO4/GPIO33/FSPIHD/SUBSPIHD 28 SPIIO5/GPIO34/FSPICS0/SUBSPICS0 29 3V3

UART.TX
BOOT UART.TXEN
I_SENSE
I2C.SCL UART.~{RXEN} LED.ERR
LORA.NSS
SPI.MOSI LORA.IRQ
SPI.CLK
SPI.MISO
LORA.DIO1
LORA.BUSY

File: Display.kicad_sch Sheet: / Ravenspark

Id: 1/6 Title: Open-Shot-Clock

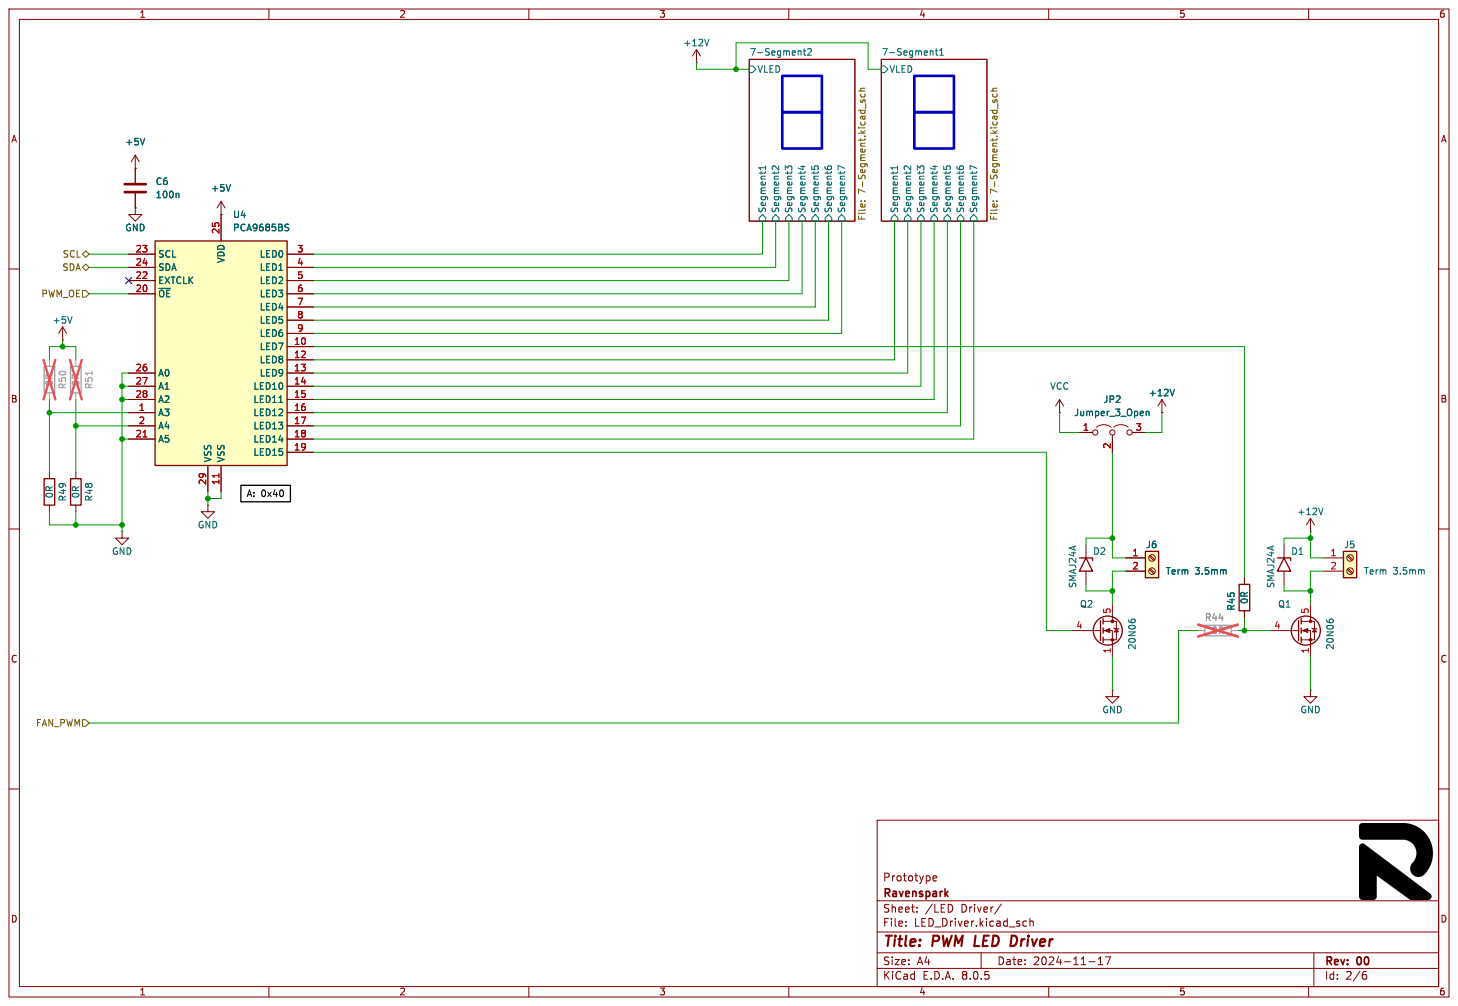
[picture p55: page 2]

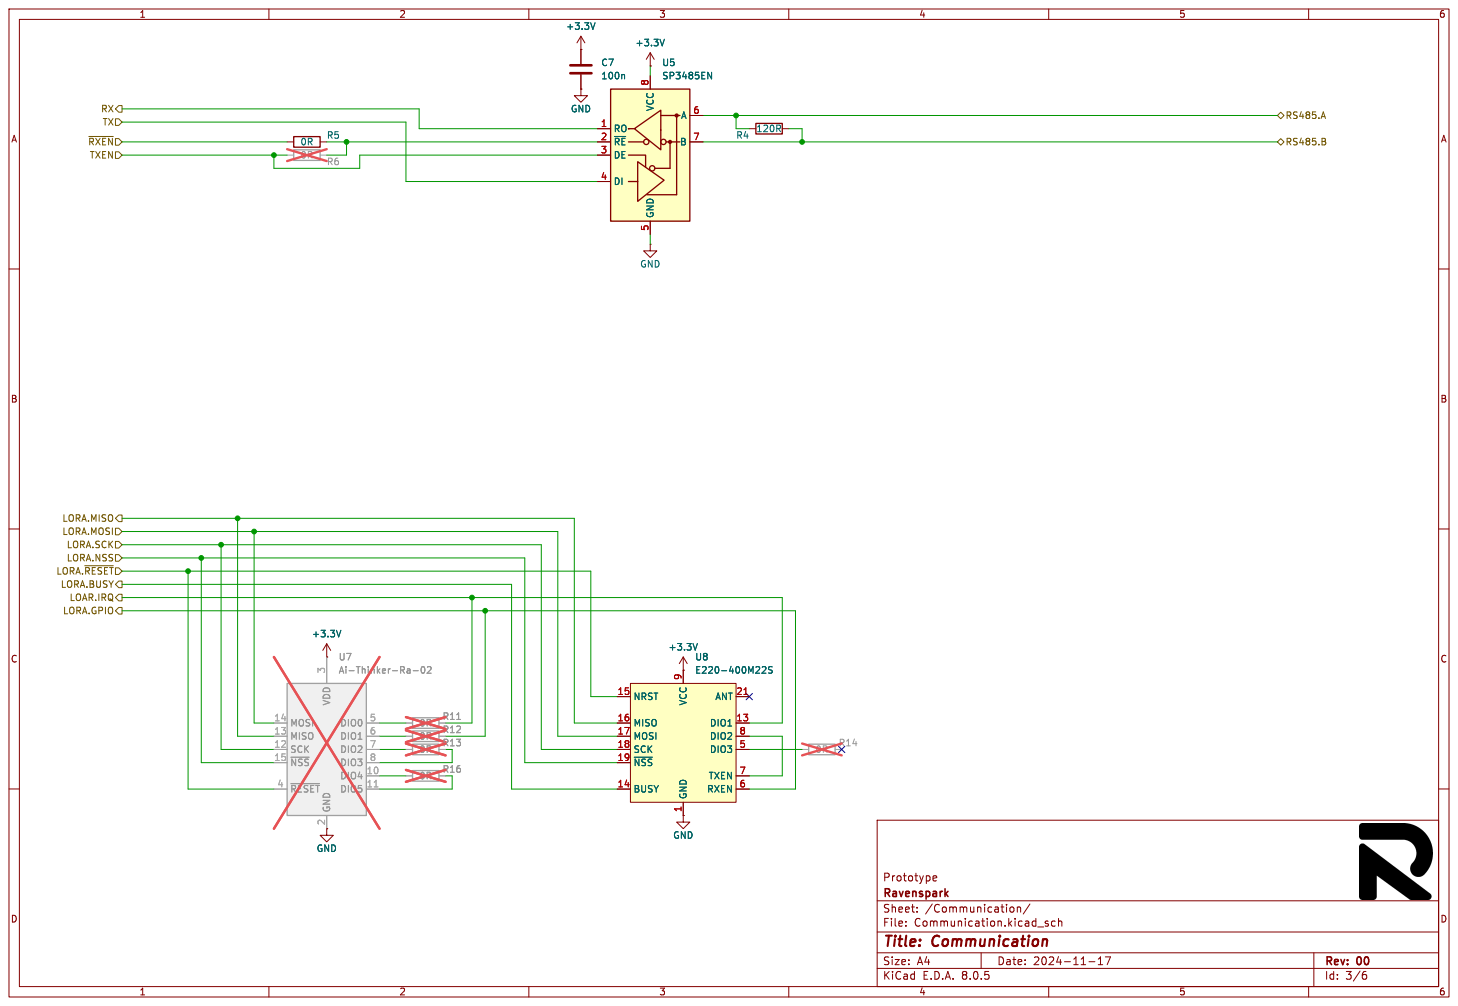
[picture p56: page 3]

LORA.~{RESET} LORA.MISO
LORA.MOSI LORA.SCK

1 DIO1 13 BUSY 14 NRST 15 MISO 16 MOSI 17 SCK 18 ANT 21 DIO3 5 RXEN 6 TXEN 7 DIO2 8 VCC

Prototype
File: Communication.kicad_sch Sheet: /Communication/ Ravenspark

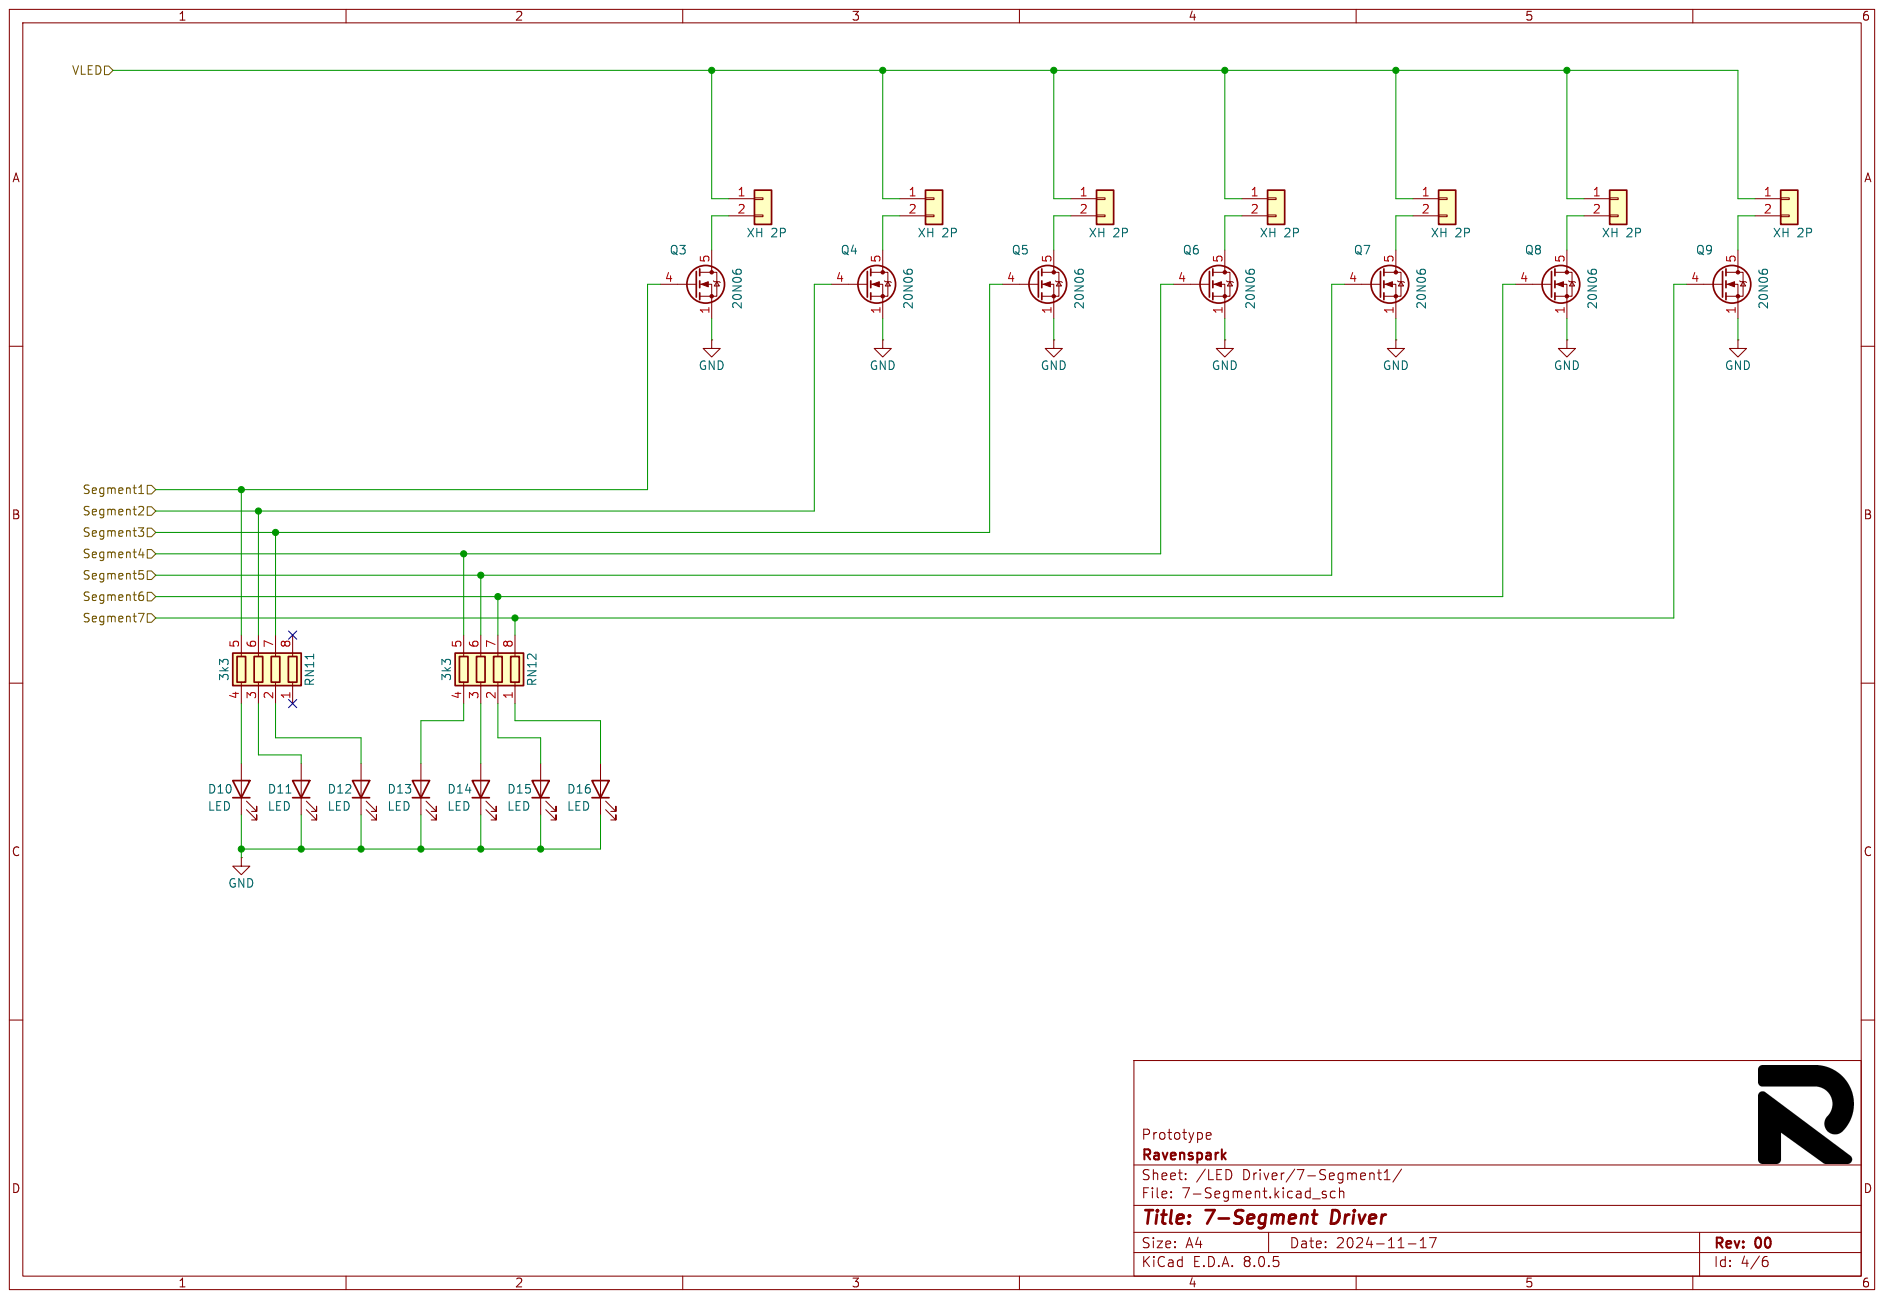
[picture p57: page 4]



Ravenspark
Id: 6/6 Title: Power Supply

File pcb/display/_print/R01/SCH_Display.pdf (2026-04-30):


SPI.MOSI SPI.CLK UART.TXEN
UART.~{RXEN}
UART.TX UART.RX

UART.~{RXEN} LED.ERR

LORA.MISO
LORA.MOSI LORA.~{RESET} LORA.SCK

3 GPIO48/SPICLK_N/SUBSPICLK_N_DIFF 30 SPIIO6/GPIO35/FSPID/SUBSPID 31 SPIIO7/GPIO36/FSPICLK/SUBSPICLK 32 SPIDQS/GPIO37/FSPIQ/SUBSPIQ 33 GPIO38/FSPIWP/SUBSPIWP 34 MTCK/GPIO39/CLK_OUT3/SUBSPICS1 35 MTDO/GPIO40/CLK_OUT2 36 MTDI/GPIO41/CLK_OUT1 37 MTMS/GPIO42 38 U0TXD/GPIO43/CLK_OUT1 39 GPIO0/BOOT 4 U0RXD/GPIO44/CLK_OUT2 40 GPIO45 41 GPIO46 44 EN 45 GPIO1/TOUCH1/ADC1_CH0 5 GPIO2/TOUCH2/ADC1_CH1 6 GPIO3/TOUCH3/ADC1_CH2 7 GPIO4/TOUCH4/ADC1_CH3 8 GPIO5/TOUCH5/ADC1_CH4 9 D101

3 GPIO48/SPICLK_N/SUBSPICLK_N_DIFF 30 SPIIO6/GPIO35/FSPID/SUBSPID 31 SPIIO7/GPIO36/FSPICLK/SUBSPICLK 32 SPIDQS/GPIO37/FSPIQ/SUBSPIQ 33 GPIO38/FSPIWP/SUBSPIWP 34 MTCK/GPIO39/CLK_OUT3/SUBSPICS1 35 MTDO/GPIO40/CLK_OUT2 36 MTDI/GPIO41/CLK_OUT1 37 MTMS/GPIO42 38 U0TXD/GPIO43/CLK_OUT1 39 GPIO0/BOOT 4 U0RXD/GPIO44/CLK_OUT2 40 GPIO45 41 GPIO46 44 EN 45 GPIO1/TOUCH1/ADC1_CH0 5 GPIO2/TOUCH2/ADC1_CH1 6 GPIO3/TOUCH3/ADC1_CH2 7 GPIO4/TOUCH4/ADC1_CH3 8 GPIO5/TOUCH5/ADC1_CH4 9 U102 ESP32-S3-MINI-1U-N8 R106 1k8 R108 4k3 +3.3V GND

1 GPIO6/TOUCH6/ADC1_CH5 10 GPIO7/TOUCH7/ADC1_CH6 11 GPIO8/TOUCH8/ADC1_CH7/SUBSPICS1 12 GPIO9/TOUCH9/ADC1_CH8/FSPIHD/SUBSPIHD 13 GPIO10/TOUCH10/ADC1_CH9/FSPICS0/FSPIIO4/SUBSPICS0 14 GPIO11/TOUCH11/ADC2_CH0/FSPID/FSPIIO5/SUBSPID 15 GPIO12/TOUCH12/ADC2_CH1/FSPICLK/FSPIIO6/SUBSPICLK 16 GPIO13/TOUCH13/ADC2_CH2/FSPIQ/FSPIIO7/SUBSPIQ 17 GPIO14/TOUCH14/ADC2_CH3/FSPIWP/FSPIDQS/SUBSPIWP 18 GPIO15/U0RTS/ADC2_CH4/XTAL_32K_P 19 GPIO16/U0CTS/ADC2_CH5/XTAL_32K_N 20 GPIO17/U1TXD/ADC2_CH6 21 GPIO18/U1RXD/ADC2_CH7/CLK_OUT3 22 GPIO19/U1RTS/ADC2_CH8/CLK_OUT2/USB_D- 23 GPIO20/U1CTS/ADC2_CH9/CLK_OUT1/USB_D+ 24 GPIO21 25 GPIO26 26 GPIO47/SPICLK_P/SUBSPICLK_P_DIFF 27 SPIIO4/GPIO33/FSPIHD/SUBSPIHD 28 SPIIO5/GPIO34/FSPICS0/SUBSPICS0 29 3V3

V_SENSE
I2C.SCL SPI.MOSI FAN.PWM

I2C.SCL GPIOx GPIOz GPIOy LORA.NSS

0-Series
File: Display.kicad_sch Sheet: / Ravenspark

Id: 1/6 Title: Open Shot Clock - Display


1 SW 2 VIN 3 FB 4 EN 5 BOOT 6 U603 TPS54202DDC

1 SW 2 VIN 3 FB 4 EN 5 BOOT 6 U604 TPS54202DDC

0-Series
Ravenspark
Id: 2/6 Title: Power Supply





LORA.MOSI LORA.GPIO
LOAR.IRQ
LORA.~{RESET} LORA.MISO

0-Series
File: Communication.kicad_sch Sheet: /Communication/ Ravenspark

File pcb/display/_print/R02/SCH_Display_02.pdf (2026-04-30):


LED Driver File: LED_Driver.kicad_sch R103 1k GND

LORA.MISO
LORA.MOSI LORA.~{RESET} LORA.SCK

LORA.RST SPI.CLK

4 SDA 1 SCL 2 ALERT 3 U101 TMP1075DSGR GND

2 VDD3P3_RTC 20 VDD3P3_CPU 46 GND 57 VDDA 55 U0TXD/PROG/GPIO43 49 U0RXD/PROG/GPIO44 50 GPIO20/USB_D+/ADC2_CH9 26 GPIO19/USB_D-/ADC2_CH8 25 GPIO0/BOOT 5 GPIO1/ADC1_CH0 6 GPIO2/ADC1_CH1 7 GPIO3/ADC1_CH2 8 GPIO4/ADC1_CH3 9 GPIO5/ADC1_CH4 10 GPIO6/ADC1_CH5 11 GPIO7/ADC1_CH6 12 GPIO8/ADC1_CH7 13 GPIO9/ADC1_CH8 14 GPIO10/ADC1_CH9 15 GPIO11/ADC2_CH0 16 GPIO12/ADC2_CH1 17 GPIO13/ADC2_CH2 18 GPIO14/ADC2_CH3 19 GPIO17/ADC2_CH6 23 GPIO18/ADC2_CH7 24 GPIO21 27 GPIO38 43 GPIO45 51 GPIO46 52 U102 ESP32-S3FN8

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

4 SDA 1 SCL 2 ALERT 3 GND

I_SENSE GPIOy V_SENSE UART.TX UART.~{RXEN} LORA.DIO1
I2C.SCL BTN2 BTN1 UART.RX
I2C.SDA GPIOx BOOT UART.TXEN
LORA.BUSY GPIOz

0-Series
File: Display.kicad_sch Sheet: / Ravenspark

Id: 1/6 Title: Open Shot Clock - Display


3 AGND 16 BOOT 23 PHASE 24 SW 5 VOUT 18 FB 17 GL 28 PGOOD 14 U601 SIC438BED-T1-GE3

3 AGND 16 BOOT 23 PHASE 24 SW 5 VOUT 18 FB 17 GL 28 PGOOD 14 R623

1 BOOT 6 SW 2 FB 4 U604 TPS54202DDC GND

0-Series
Ravenspark
Id: 2/6 Title: Power Supply





LORA.GPIO
LORA.MOSI LOAR.IRQ
LORA.~{RESET} LORA.MISO

File: Communication.kicad_sch Sheet: /Communication/ Ravenspark

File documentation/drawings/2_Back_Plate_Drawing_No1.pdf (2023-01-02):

303

# 65 ⁶⁵


Dept. Technical reference Created by Approved by Title DWG No. Document type Document status Rev. Date of issue Sheet Fan Holes Optional 14.12.2022 1/1 Back_Plate_No1 Daniel Busse 422 65

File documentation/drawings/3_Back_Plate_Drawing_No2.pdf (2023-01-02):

30

31


Dept. Technical reference Created by Approved by Title DWG No. Document type Document status Rev. Date of issue Sheet Fan Grids Optional 14.12.2022 1/1 Back_Plate_No2 Daniel Busse 30 3030 3030

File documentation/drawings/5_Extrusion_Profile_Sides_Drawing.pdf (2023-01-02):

266 ¹²⁰

Dept. Technical reference Created by Approved by Title DWG No. Document type Document status Rev. Date of issue Sheet Sides 2x 14.12.2022 1/1 Extrusion_Profile Daniel Busse

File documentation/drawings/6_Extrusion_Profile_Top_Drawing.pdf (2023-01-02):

60 ⁶⁵⁸⁷

Dept. Technical reference Created by Approved by Title DWG No. Document type Document status Rev. Date of issue Sheet Top 14.12.2022 1/1 Extrusion_Profile Daniel Busse 386

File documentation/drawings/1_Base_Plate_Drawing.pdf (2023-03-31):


Dept. Technical reference Created by Approved by Title DWG No. Document type Document status Rev. Date of issue Sheet Back Side View 14.12.2022 1/1 Base_Plate Daniel Busse

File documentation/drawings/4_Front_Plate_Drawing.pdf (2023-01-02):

303


Dept. Technical reference Created by Approved by Title DWG No. Document type Document status Rev. Date of issue Sheet 14.12.2022 1/1 Front_Plate Daniel Busse 422

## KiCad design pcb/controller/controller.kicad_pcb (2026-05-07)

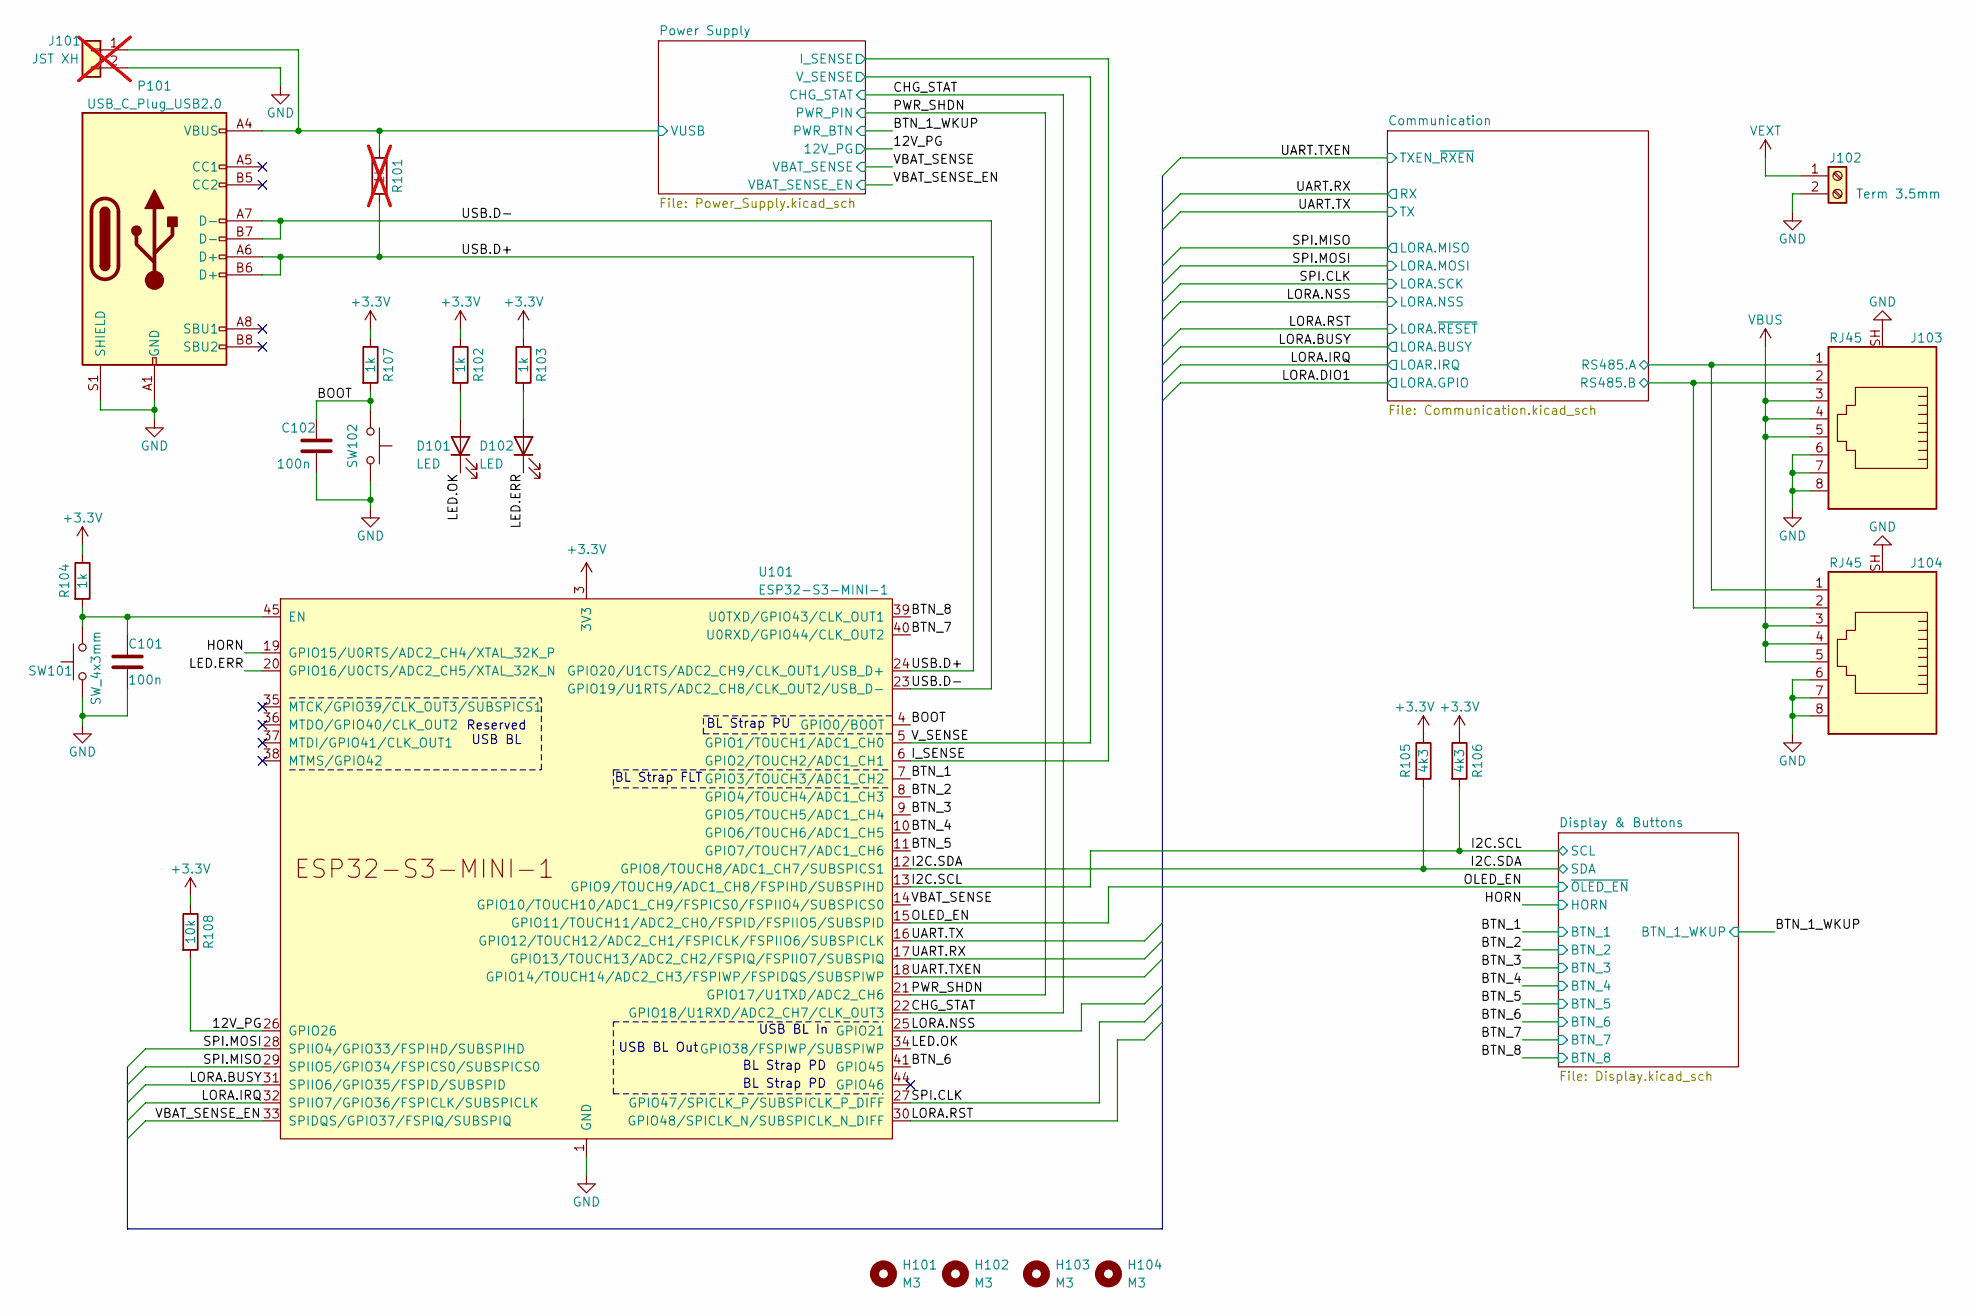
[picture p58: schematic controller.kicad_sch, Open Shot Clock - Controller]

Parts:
C101, C102: 100n; C_0402_1005Metric; LCSC Part # C307331
D101, D102: LED; LED_0603_1608Metric; LCSC Part # C2286
H101, H102, H103, H104: M3; MountingHole_3.2mm_M3
J101: JST XH; JST_XH_B2B-XH-A_1x02_P2.50mm_Vertical; LCSC Part # C158012; not fitted
J102: Term 3.5mm; PhoenixContact_MC_1,5_2-G-3.5_1x02_P3.50mm_Horizontal; LCSC Part # C409115
J103, J104: RJ45; RJ45_Amphenol_RJHSE5380; LCSC Part # C19078599
P101: USB_C_Plug_USB2.0; USB_C_Receptacle_G-Switch_GT-USB-7010ASV; LCSC Part # C2927039
R101: 1k; R_0402_1005Metric; not fitted
R102, R103, R104, R107: 1k; R_0402_1005Metric
R105, R106: 4k3; R_0402_1005Metric
R108: 10k; R_0402_1005Metric
SW101, SW102: SW_4x3mm; SW_Push_4x3mm; LCSC Part # C18077679
U101: ESP32-S3-MINI-1; ESP32-S3-MINI-1U; LCSC Part # C2980299

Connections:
+3.3V: R102.1, R103.1, R104.1, R105.1, R106.1, R107.1, R108.1, U101.3 (3V3); also elsewhere on the board
/12V_PG: R108.2, U101.26 (GPIO26); also elsewhere on the board
/BOOT: C102.1, R107.2, SW102.1, U101.4 (GPIO0/BOOT)
/BTN_1: U101.7 (GPIO3/TOUCH3/ADC1_CH2); also elsewhere on the board
/BTN_2: U101.8 (GPIO4/TOUCH4/ADC1_CH3); also elsewhere on the board
/BTN_3: U101.9 (GPIO5/TOUCH5/ADC1_CH4); also elsewhere on the board
/BTN_4: U101.10 (GPIO6/TOUCH6/ADC1_CH5); also elsewhere on the board
/BTN_5: U101.11 (GPIO7/TOUCH7/ADC1_CH6); also elsewhere on the board
/BTN_6: U101.41 (GPIO45); also elsewhere on the board
/BTN_7: U101.40 (U0RXD/GPIO44/CLK_OUT2); also elsewhere on the board
/BTN_8: U101.39 (U0TXD/GPIO43/CLK_OUT1); also elsewhere on the board
/CHG_STAT: U101.22 (GPIO18/U1RXD/ADC2_CH7/CLK_OUT3); also elsewhere on the board
/Communication/RS485.A: J103.1, J104.1; also elsewhere on the board
/Communication/RS485.B: J103.2, J104.2; also elsewhere on the board
/HORN: U101.19 (GPIO15/U0RTS/ADC2_CH4/XTAL_32K_P); also elsewhere on the board
/I2C.SCL: R106.2, U101.13 (GPIO9/TOUCH9/ADC1_CH8/FSPIHD/SUBSPIHD); also elsewhere on the board
/I2C.SDA: R105.2, U101.12 (GPIO8/TOUCH8/ADC1_CH7/SUBSPICS1); also elsewhere on the board
/I_SENSE: U101.6 (GPIO2/TOUCH2/ADC1_CH1); also elsewhere on the board
/LED.ERR: D102.1 (K), U101.20 (GPIO16/U0CTS/ADC2_CH5/XTAL_32K_N)
/LED.OK: D101.1 (K), U101.34 (GPIO38/FSPIWP/SUBSPIWP)
/LORA.BUSY: U101.31 (SPIIO6/GPIO35/FSPID/SUBSPID); also elsewhere on the board
/LORA.IRQ: U101.32 (SPIIO7/GPIO36/FSPICLK/SUBSPICLK); also elsewhere on the board
/LORA.NSS: U101.25 (GPIO21); also elsewhere on the board
/LORA.RST: U101.30 (GPIO48/SPICLK_N/SUBSPICLK_N_DIFF); also elsewhere on the board
/OLED_EN: U101.15 (GPIO11/TOUCH11/ADC2_CH0/FSPID/FSPIIO5/S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); also elsewhere on the board
/PWR_SHDN: U101.21 (GPIO17/U1TXD/ADC2_CH6); also elsewhere on the board
/Power Supply/VUSB: J101.1, P101.A4 (VBUS), P101.A9 (VBUS), P101.B4 (VBUS), P101.B9 (VBUS), R101.1; also elsewhere on the board
/SPI.CLK: U101.27 (GPIO47/SPICLK_P/SUBSPICLK_P_DIFF); also elsewhere on the board
/SPI.MISO: U101.29 (SPIIO5/GPIO34/FSPICS0/SUBSPICS0); also elsewhere on the board
/SPI.MOSI: U101.28 (SPIIO4/GPIO33/FSPIHD/SUBSPIHD); also elsewhere on the board
/UART.RX: U101.17 (GPIO13/TOUCH13/ADC2_CH2/FSPIQ/FSPIIO7/S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); also elsewhere on the board
/UART.TX: U101.16 (GPIO12/TOUCH12/ADC2_CH1/FSPICLK/FSPIIO6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); also elsewhere on the board
/UART.TXEN: U101.18 (GPIO14/TOUCH14/ADC2_CH3/FSPIWP/FSPIDQS/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); also elsewhere on the board
/USB.D+: P101.A6 (D+), P101.B6 (D+), R101.2, U101.24 (GPIO20/U1CTS/ADC2_CH9/CLK_OUT1/USB_D+)
/USB.D-: P101.A7 (D-), P101.B7 (D-), U101.23 (GPIO19/U1RTS/ADC2_CH8/CLK_OUT2/USB_D-)
/VBAT_SENSE: U101.14 (GPIO10/TOUCH10/ADC1_CH9/FSPICS0/FSPIIO4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); also elsewhere on the board
/VBAT_SENSE_EN: U101.33 (SPIDQS/GPIO37/FSPIQ/SUBSPIQ); also elsewhere on the board
/V_SENSE: U101.5 (GPIO1/TOUCH1/ADC1_CH0); also elsewhere on the board
GND: C101.2, C102.2, J101.2, J102.2, J103.6, J103.7, J103.8, J103.SH, J104.6, J104.7, J104.8, J104.SH, P101.A1 (GND), P101.A12 (GND), P101.B1 (GND), P101.B12 (GND), P101.S1 (SHIELD), SW101.2, SW102.2, U101.1 (GND), U101.2 (GND), U101.42 (GND), U101.43 (GND), U101.46 (GND), U101.47 (GND), U101.48 (GND), U101.49 (GND), U101.50 (GND), U101.51 (GND), U101.52 (GND), U101.53 (GND), U101.54 (GND), U101.55 (GND), U101.56 (GND), U101.57 (GND), U101.58 (GND), U101.59 (GND), U101.60 (GND), U101.61 (GND), U101.62 (GND), U101.63 (GND), U101.64 (GND), U101.65 (GND); also elsewhere on the board
unnamed: D101.2 (A), R102.2
unnamed: D102.2 (A), R103.2
unnamed: C101.1, R104.2, SW101.1, U101.45 (EN)
VBUS: J103.3, J103.4, J103.5, J104.3, J104.4, J104.5; also elsewhere on the board
VEXT: J102.1; also elsewhere on the board

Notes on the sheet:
BL Strap PD
Reserved USB BL
BL Strap FLT
USB BL In
BL Strap PU
USB BL Out

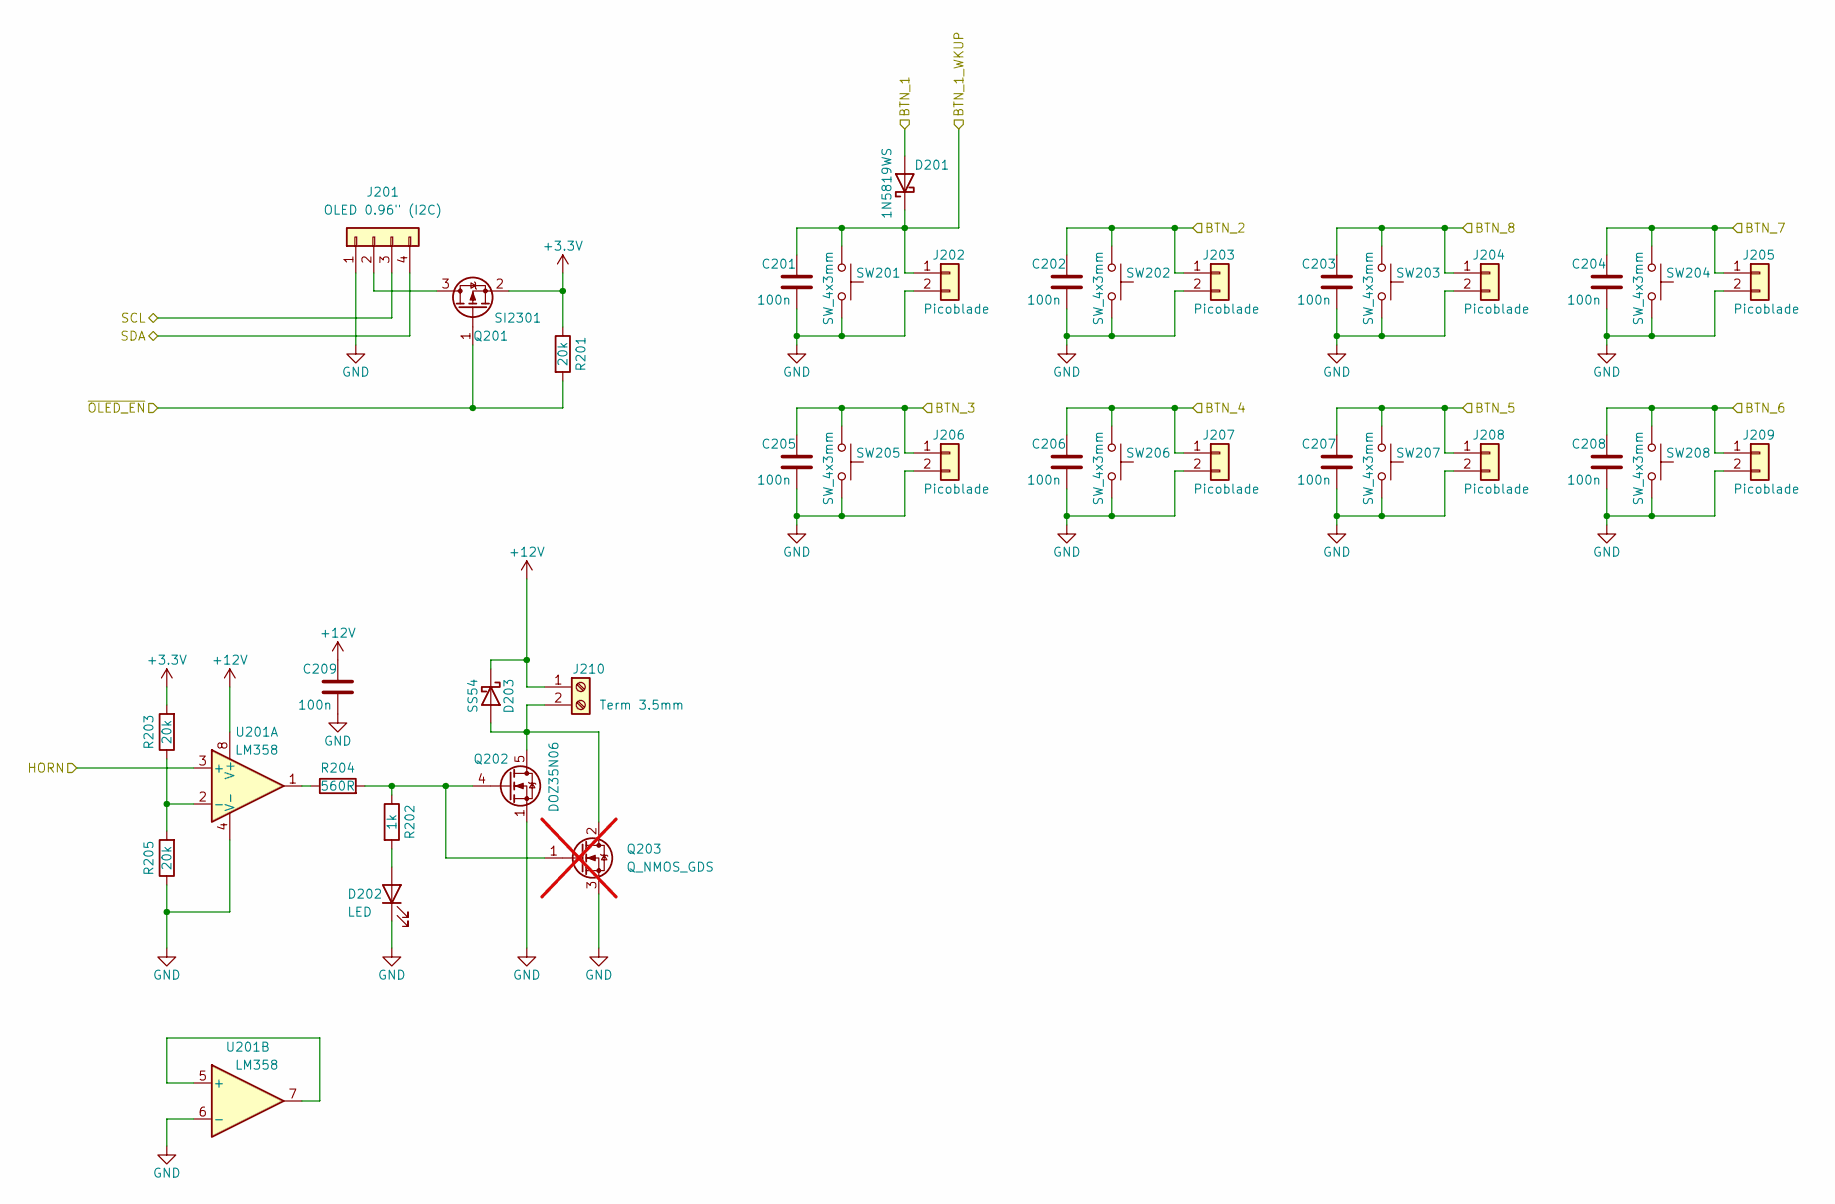
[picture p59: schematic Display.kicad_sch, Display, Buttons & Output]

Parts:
C201, C202, C203, C204, C205, C206, C207, C208, C209: 100n; C_0402_1005Metric; LCSC Part # C307331
D201: 1N5819WS; D_SOD-323; LCSC Part # C191023
D202: LED; LED_0603_1608Metric; LCSC Part # C2286
D203: SS54; D_SMA; LCSC Part # C22452
J201: OLED 0.96" (I2C); PinSocket_1x04_P2.54mm_Vertical_SMD_Pin1Left; LCSC Part # C20071191
J202, J203, J204, J205, J206, J207, J208, J209: Picoblade; Molex_PicoBlade_53048-0210_1x02_P1.25mm_Horizontal; LCSC Part # C2845535
J210: Term 3.5mm; PhoenixContact_MC_1,5_2-G-3.5_1x02_P3.50mm_Horizontal; LCSC Part # C409115
Q201: SI2301; SOT-23; LCSC Part # C10487
Q202: DOZ35N06; VSON-8_3.3x3.3mm_P0.65mm_NexFET; LCSC Part # C36499167
Q203: Q_NMOS_GDS; TO-252-2; not fitted
R201, R203, R205: 20k; R_0402_1005Metric
R202: 1k; R_0402_1005Metric
R204: 560R; R_0402_1005Metric
SW201, SW202, SW203, SW204, SW205, SW206, SW207, SW208: SW_4x3mm; SW_Push_4x3mm; LCSC Part # C18077679
U201: LM358; SOIC-8_3.9x4.9mm_P1.27mm; LCSC Part # C7950

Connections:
+3.3V: Q201.2 (S), R201.1, R203.2; also elsewhere on the board
+12V: C209.1, D203.1 (K), J210.1, U201.8 (V+); also elsewhere on the board
/BTN_1: D201.2 (A); also elsewhere on the board
/BTN_1_WKUP: C201.1, D201.1 (K), J202.1, SW201.1; also elsewhere on the board
/BTN_2: C202.1, J203.1, SW202.1; also elsewhere on the board
/BTN_3: C205.1, J206.1, SW205.1; also elsewhere on the board
/BTN_4: C206.1, J207.1, SW206.1; also elsewhere on the board
/BTN_5: C207.1, J208.1, SW207.1; also elsewhere on the board
/BTN_6: C208.1, J209.1, SW208.1; also elsewhere on the board
/BTN_7: C204.1, J205.1, SW204.1; also elsewhere on the board
/BTN_8: C203.1, J204.1, SW203.1; also elsewhere on the board
/HORN: U201.3 (+); also elsewhere on the board
/I2C.SCL: J201.3; also elsewhere on the board
/I2C.SDA: J201.4; also elsewhere on the board
/OLED_EN: Q201.1 (G), R201.2; also elsewhere on the board
GND: C201.2, C202.2, C203.2, C204.2, C205.2, C206.2, C207.2, C208.2, C209.2, D202.1 (K), J201.1, J202.2, J203.2, J204.2, J205.2, J206.2, J207.2, J208.2, J209.2, Q202.1 (S), Q202.2 (S), Q202.3 (S), Q203.3 (S), R205.1, SW201.2, SW202.2, SW203.2, SW204.2, SW205.2, SW206.2, SW207.2, SW208.2, U201.4 (V-), U201.6 (-); also elsewhere on the board
unnamed: D202.2 (A), R202.2
unnamed: D203.2 (A), J210.2, Q202.5 (D), Q203.2 (D)
unnamed: J201.2, Q201.3 (D)
unnamed: Q202.4 (G), Q203.1 (G), R202.1, R204.2
unnamed: R204.1, U201.1
unnamed: R203.1, R205.2, U201.2 (-)
unnamed: U201.5 (+), U201.7

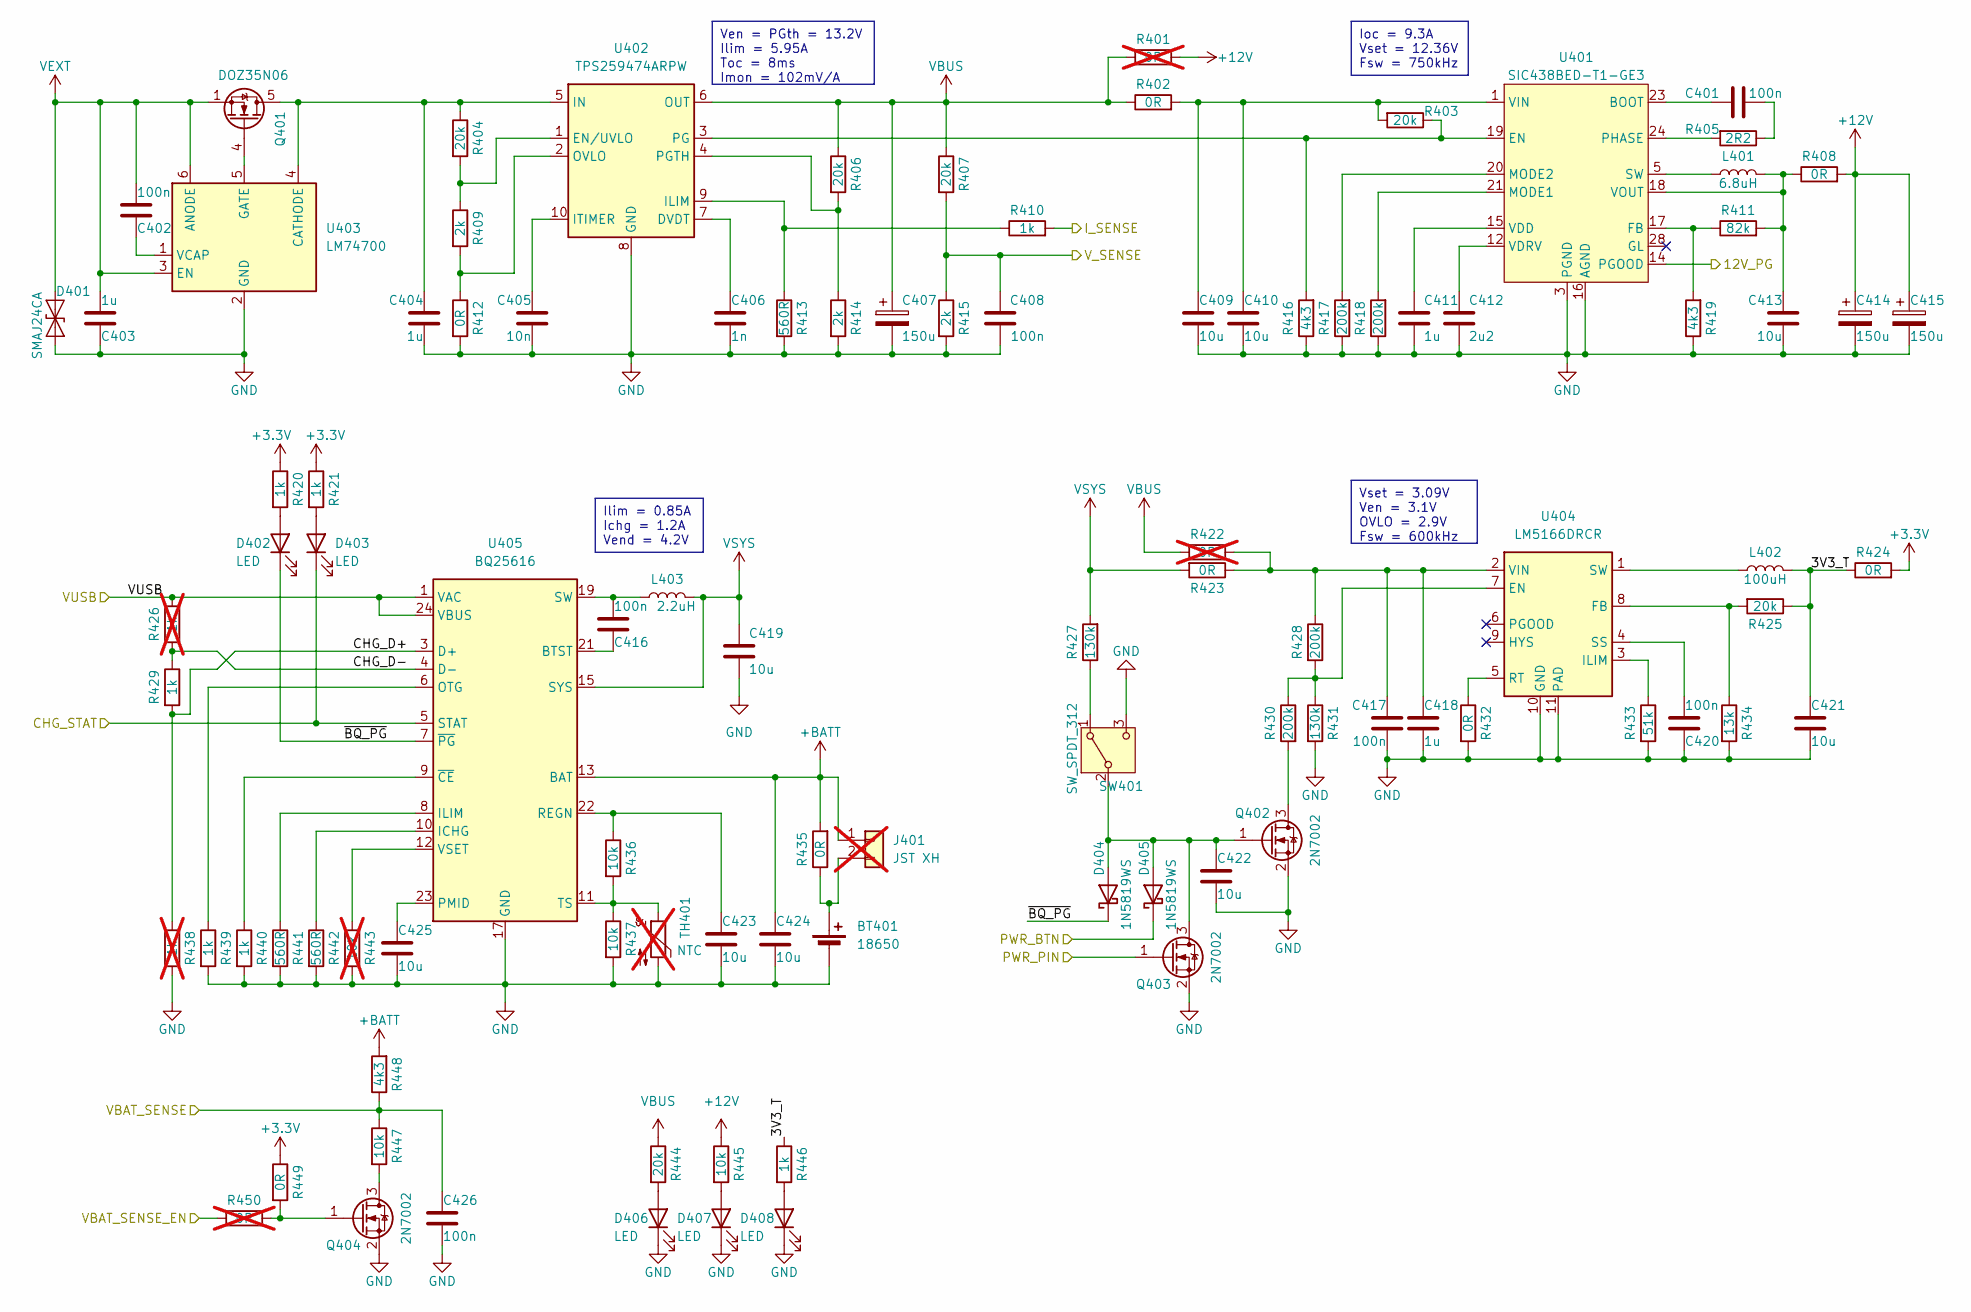
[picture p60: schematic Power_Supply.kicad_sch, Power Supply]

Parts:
BT401: 18650; BatteryHolder_SMD_1x18650; LCSC Part # C2988620
C401, C402, C408, C416, C417, C420, C426: 100n; C_0402_1005Metric; LCSC Part # C307331
C403, C404, C418: 1u; C_0603_1608Metric; LCSC Part # C15849
C405: 10n; C_0402_1005Metric; LCSC Part # C15195
C406: 1n; C_0402_1005Metric; LCSC Part # C1523
C407, C414, C415: 150u; CP_Elec_8x10; LCSC Part # C2898894
C409, C410, C413: 10u; C_1206_3216Metric; LCSC Part # C13585
C411: 1u; C_0402_1005Metric; LCSC Part # C52923
C412: 2u2; C_0603_1608Metric; LCSC Part # C23630
C419, C421, C422, C423, C424, C425: 10u; C_0603_1608Metric; LCSC Part # C19702
D401: SMAJ24CA; D_SMA; LCSC Part # C20883150
D402, D403, D406, D407, D408: LED; LED_0603_1608Metric; LCSC Part # C2286
D404, D405: 1N5819WS; D_SOD-323; LCSC Part # C191023
J401: JST XH; JST_XH_B2B-XH-A_1x02_P2.50mm_Vertical; LCSC Part # C158012; not fitted
L401: 6.8uH; L_Bourns_SRP1050WA; LCSC Part # C32712978
L402: 100uH; L_Changjiang_FNR4030S; LCSC Part # C7588681
L403: 2.2uH; L_1008_2520Metric; LCSC Part # C964122
Q401: DOZ35N06; VSON-8_3.3x3.3mm_P0.65mm_NexFET; LCSC Part # C36499167
Q402, Q403, Q404: 2N7002; SOT-23; LCSC Part # C8545
R401: 0R; R_1206_3216Metric; not fitted
R402, R408: 0R; R_1206_3216Metric
R403, R404, R406, R407, R425, R444: 20k; R_0402_1005Metric
R405: 2R2; R_0402_1005Metric
R409, R414, R415: 2k; R_0402_1005Metric
R410, R420, R421, R429, R439, R440, R446: 1k; R_0402_1005Metric
R411: 82k; R_0402_1005Metric
R412, R432, R449: 0R; R_0402_1005Metric
R413, R441, R442: 560R; R_0402_1005Metric
R416, R419, R448: 4k3; R_0402_1005Metric
R417, R418, R428, R430: 200k; R_0402_1005Metric
R422: 0R; R_0603_1608Metric; not fitted
R423, R424, R435: 0R; R_0603_1608Metric
R426, R438: 1k; R_0402_1005Metric; not fitted
R427, R431: 130k; R_0402_1005Metric
R433: 51k; R_0402_1005Metric
R434: 13k; R_0402_1005Metric
R436, R437, R445, R447: 10k; R_0402_1005Metric
R443: 10k; R_0402_1005Metric; not fitted
R450: 0R; R_0402_1005Metric; not fitted
SW401: SW_SPDT_312; SW_CuK_OS102011MA1QN1_SPDT_Angled; LCSC Part # C431548
TH401: NTC; R_0402_1005Metric; LCSC Part # C77131; not fitted
U401: SIC438BED-T1-GE3; Vishay_PowerPAK_MLP44-24L_ThermalVias; LCSC Part # C511430
U402: TPS259474ARPW; RPW0010A_VQFN-HR-10; LCSC Part # C3662807
U403: LM74700; SOT-23-6; LCSC Part # C2941042
U404: LM5166DRCR; Texas_S-PVSON-N10_ThermalVias; LCSC Part # C481392
U405: BQ25616; VQFN-24-1EP_4x4mm_P0.5mm_EP2.5x2.5mm_ThermalVias; LCSC Part # C2866447

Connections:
+3.3V: R420.1, R421.1, R424.2, R449.1; also elsewhere on the board
+12V: C414.1, C415.1, R401.1, R408.2, R445.1; also elsewhere on the board
+BATT: C424.1, J401.1, R435.2, R448.2, U405.13 (BAT), U405.14 (BAT)
/12V_PG: U401.14 (PGOOD); also elsewhere on the board
/BTN_1_WKUP: D405.1 (K); also elsewhere on the board
/CHG_STAT: D403.1 (K), U405.5 (STAT); also elsewhere on the board
/I_SENSE: R410.2; also elsewhere on the board
/PWR_SHDN: Q403.1 (G); also elsewhere on the board
/Power Supply/3V3_T: C421.1, L402.2, R424.1, R425.1, R446.1
/Power Supply/CHG_D+: R429.2, R438.1, U405.3 (D+)
/Power Supply/CHG_D-: R426.2, R429.1, U405.4 (D-)
/Power Supply/VUSB: R426.1, U405.1 (VAC), U405.24 (VBUS); also elsewhere on the board
/Power Supply/~BQ_PG: D402.1 (K), D404.1 (K), U405.7 (~PG)
/VBAT_SENSE: C426.2, R447.1, R448.1; also elsewhere on the board
/VBAT_SENSE_EN: R450.1; also elsewhere on the board
/V_SENSE: C408.2, R407.2, R415.1; also elsewhere on the board
GND: BT401.2 (-), C403.2, C404.1, C405.1, C406.1, C407.2, C408.1, C409.2, C410.2, C411.2, C412.2, C413.2, C414.2, C415.2, C417.1, C418.2, C419.2, C420.1, C421.2, C422.2, C423.2, C424.2, C425.2, C426.1, D401.2 (A2), D406.1 (K), D407.1 (K), D408.1 (K), Q402.2 (S), Q403.2 (S), Q404.2 (S), R412.2, R413.2, R414.2, R415.2, R416.1, R417.1, R418.1, R419.1, R431.2, R432.2, R433.2, R434.2, R437.2, R438.2, R439.2, R440.2, R441.2, R442.2, R443.2, SW401.3 (C), TH401.2, U401.3 (PGND), U401.4 (PGND), U401.13 (PGND), U401.16 (AGND), U401.25 (AGND), U401.27 (PGND), U402.8 (GND), U403.2 (GND), U404.10 (GND), U404.11 (PAD), U405.17 (GND), U405.18 (GND), U405.25 (GND); also elsewhere on the board
unnamed: BT401.1 (+), J401.2, R435.1
unnamed: C401.2, R405.1
unnamed: C416.1, L403.1, U405.19 (SW), U405.20 (SW)
unnamed: D402.2 (A), R420.2
unnamed: D403.2 (A), R421.2
unnamed: C422.1, D404.2 (A), D405.2 (A), Q402.1 (G), Q403.3 (D), SW401.2 (B)
unnamed: D406.2 (A), R444.2
unnamed: D407.2 (A), R445.2
unnamed: D408.2 (A), R446.2
unnamed: C404.2, Q401.5 (D), R404.1, U402.5 (IN), U403.4 (CATHODE)
unnamed: Q401.4 (G), U403.5 (GATE)
unnamed: Q402.3 (D), R430.2
unnamed: Q404.3 (D), R447.2
unnamed: Q404.1 (G), R449.2, R450.2
unnamed: R427.1, SW401.1 (A)
unnamed: C401.1, U401.23 (BOOT)
unnamed: R403.1, R416.2, U401.19 (EN), U402.3 (PG)
unnamed: R411.1, R419.2, U401.17 (FB)
unnamed: R418.2, U401.21 (MODE1)
unnamed: R417.2, U401.20 (MODE2)
unnamed: R405.2, U401.24 (PHASE)
unnamed: C411.1, U401.15 (VDD)
unnamed: C412.1, U401.12 (VDRV)
unnamed: C413.1, L401.2, R408.1, R411.2, U401.18 (VOUT)
unnamed: C406.2, U402.7 (DVDT)
unnamed: R404.2, R409.1, U402.1 (EN/UVLO)
unnamed: R410.1, R413.1, U402.9 (ILIM)
unnamed: C405.2, U402.10 (ITIMER)
unnamed: R409.2, R412.1, U402.2 (OVLO)
unnamed: R406.2, R414.1, U402.4 (PGTH)
unnamed: C402.2, U403.1 (VCAP)
unnamed: R428.2, R430.1, R431.1, U404.7 (EN)
unnamed: R425.2, R434.1, U404.8 (FB)
unnamed: R433.1, U404.3 (ILIM)
unnamed: R432.1, U404.5 (RT)
unnamed: C420.2, U404.4 (SS)
unnamed: L402.1, U404.1 (SW)
unnamed: C417.2, C418.1, R422.1, R423.1, R428.1, U404.2 (VIN)
unnamed: C416.2, U405.21 (BTST)
unnamed: R442.1, U405.10 (ICHG)
unnamed: R441.1, U405.8 (ILIM)
unnamed: R439.1, U405.6 (OTG)
unnamed: C425.1, U405.23 (PMID)
unnamed: C423.1, R436.1, U405.22 (REGN)
unnamed: R436.2, R437.1, TH401.1, U405.11 (TS)
unnamed: R443.1, U405.12 (VSET)
unnamed: R440.1, U405.9 (~CE)
SW: L401.1, U401.5 (SW), U401.6 (SW), U401.7 (SW), U401.8 (SW), U401.9 (SW)
VBUS: C407.1, R401.2, R402.1, R406.1, R407.1, R422.2, R444.1, U402.6 (OUT); also elsewhere on the board
VEXT: C402.1, C403.1, D401.1 (A1), Q401.1 (S), Q401.2 (S), Q401.3 (S), U403.3 (EN), U403.6 (ANODE); also elsewhere on the board
VIN: C409.1, C410.1, R402.2, R403.2, U401.1 (VIN), U401.2 (VIN), U401.22 (VIN), U401.26 (VIN)
VSYS: C419.1, L403.2, R423.2, R427.2, U405.15 (SYS), U405.16 (SYS)

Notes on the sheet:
Ilim = 0.85A Ichg = 1.2A Vend = 4.2V
Ven = PGth = 13.2V Ilim = 5.95A Toc = 8ms Imon = 102mV/A
Vset = 3.09V Ven = 3.1V OVLO = 2.9V Fsw = 600kHz
Ioc = 9.3A Vset = 12.36V Fsw = 750kHz

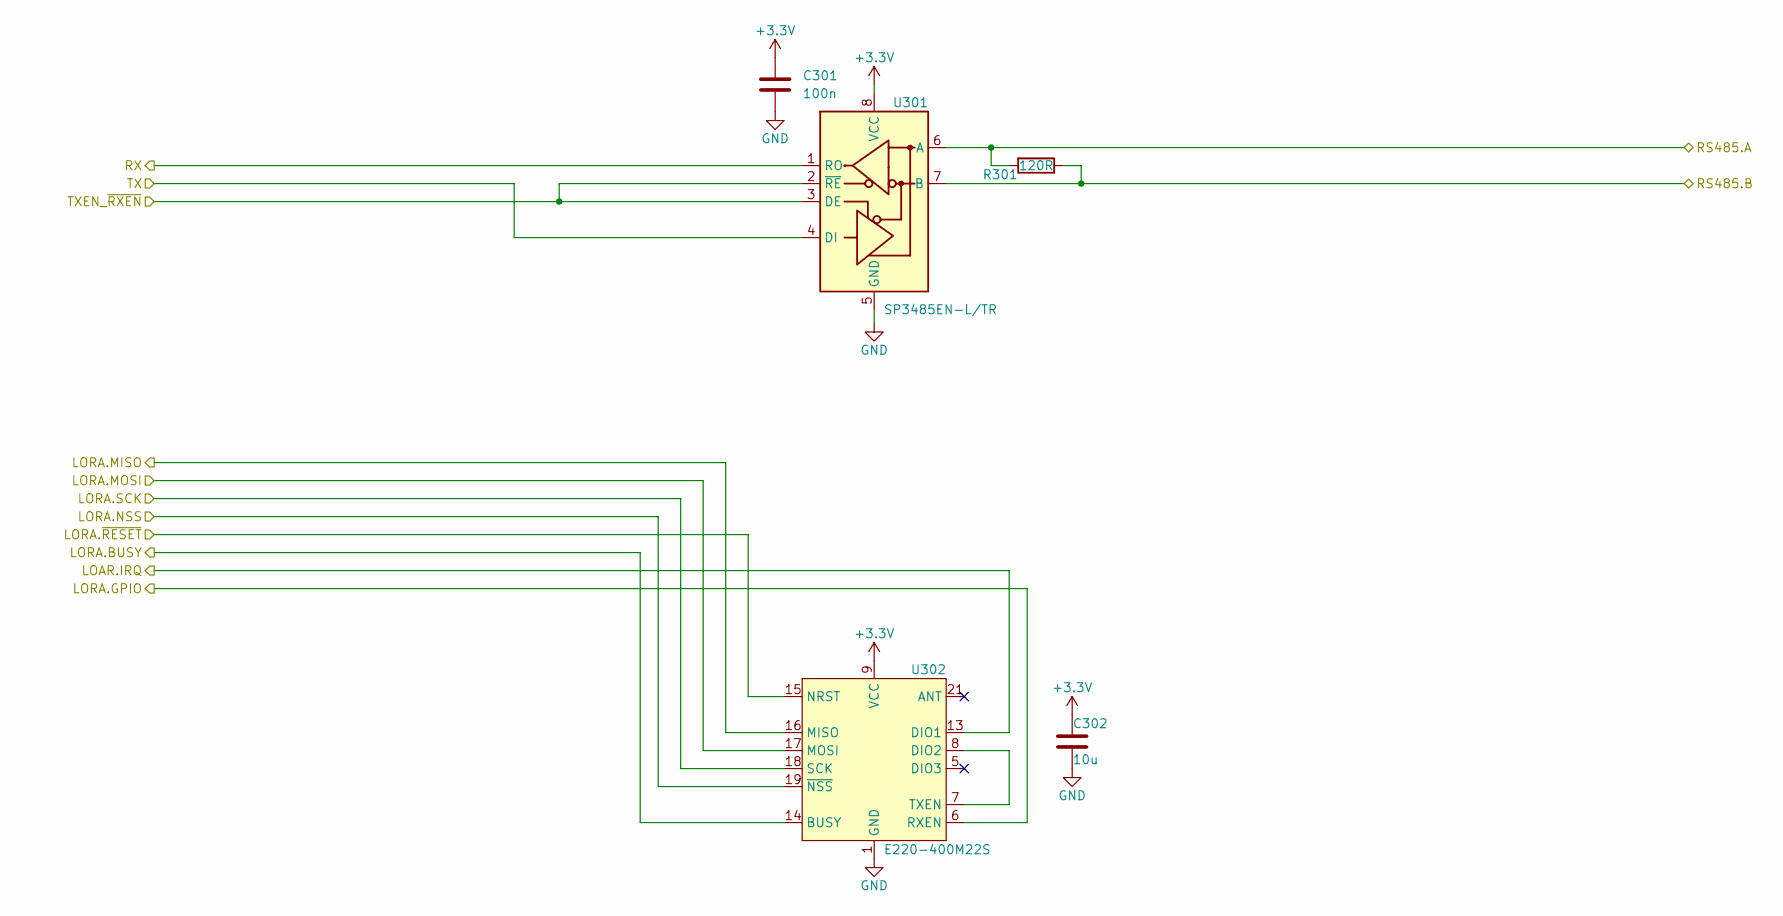
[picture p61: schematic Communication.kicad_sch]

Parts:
C301: 100n; C_0402_1005Metric; LCSC Part # C307331
C302: 10u; C_0603_1608Metric; LCSC Part # C19702
R301: 120R; R_0805_2012Metric
U301: SP3485EN-L/TR; SOIC-8_3.9x4.9mm_P1.27mm; LCSC Part # C8963
U302: E220-400M22S; LCSC Part # C2971737

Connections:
+3.3V: C301.1, C302.1, U301.8 (VCC), U302.9 (VCC); also elsewhere on the board
/Communication/RS485.A: R301.2, U301.6 (A); also elsewhere on the board
/Communication/RS485.B: R301.1, U301.7 (B); also elsewhere on the board
/LORA.BUSY: U302.14 (BUSY); also elsewhere on the board
/LORA.DIO1: U302.6 (RXEN)
/LORA.IRQ: U302.13 (DIO1); also elsewhere on the board
/LORA.NSS: U302.19 (~NSS); also elsewhere on the board
/LORA.RST: U302.15 (NRST); also elsewhere on the board
/SPI.CLK: U302.18 (SCK); also elsewhere on the board
/SPI.MISO: U302.16 (MISO); also elsewhere on the board
/SPI.MOSI: U302.17 (MOSI); also elsewhere on the board
/UART.RX: U301.1 (RO); also elsewhere on the board
/UART.TX: U301.4 (DI); also elsewhere on the board
/UART.TXEN: U301.2 (~RE), U301.3 (DE); also elsewhere on the board
GND: C301.2, C302.2, U301.5 (GND), U302.1 (GND), U302.2 (GND), U302.3 (GND), U302.4 (GND), U302.10 (GND), U302.11 (GND), U302.12 (GND), U302.20 (GND), U302.22 (GND); also elsewhere on the board
unnamed: U302.7 (TXEN), U302.8 (DIO2)

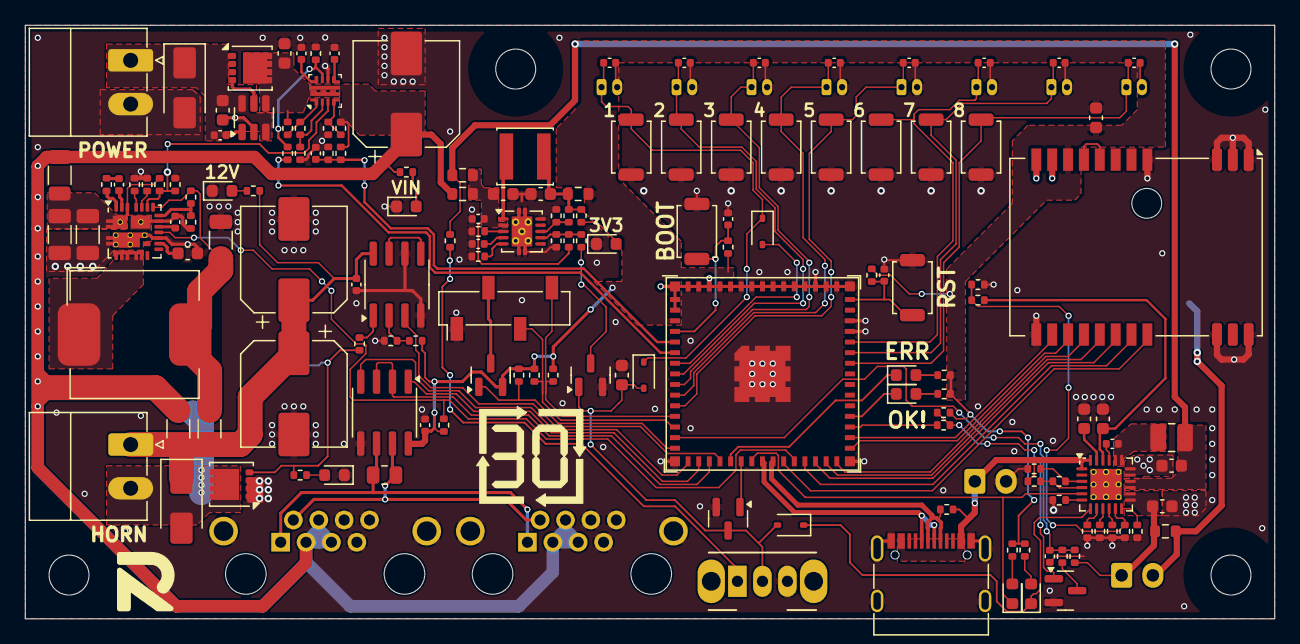
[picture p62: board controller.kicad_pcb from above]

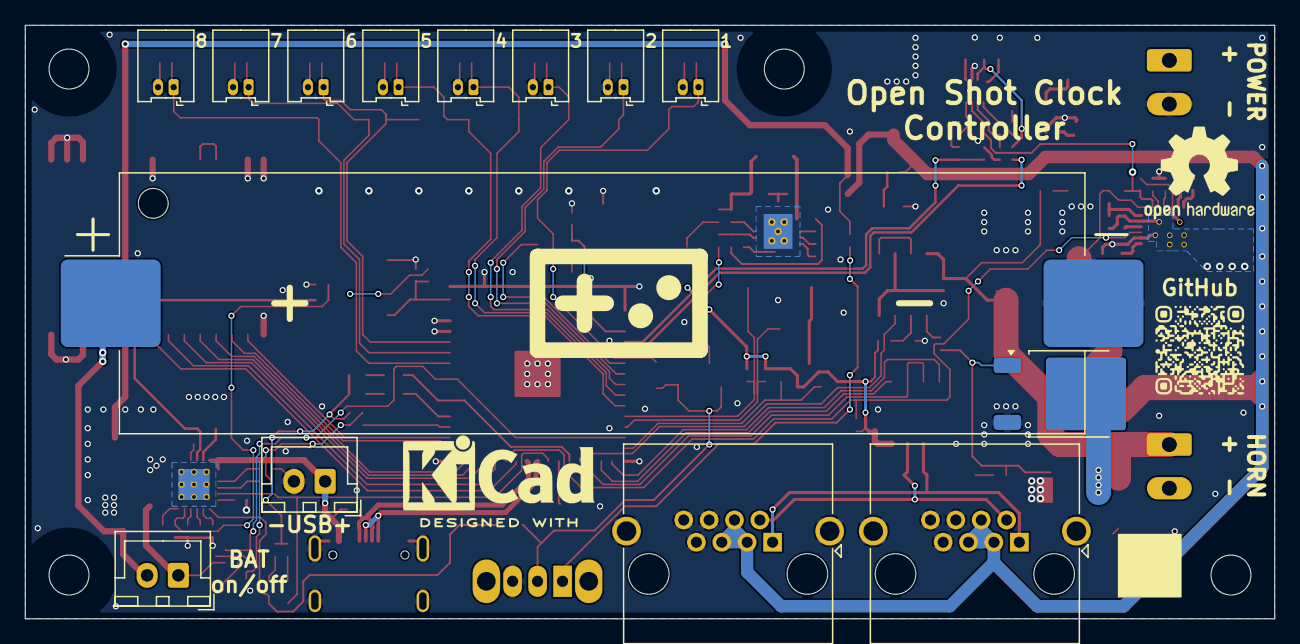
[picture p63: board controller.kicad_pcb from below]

Board: 2 copper layers, 100.0 x 47.5 mm, 168 parts (14 on the bottom side), 109 nets.

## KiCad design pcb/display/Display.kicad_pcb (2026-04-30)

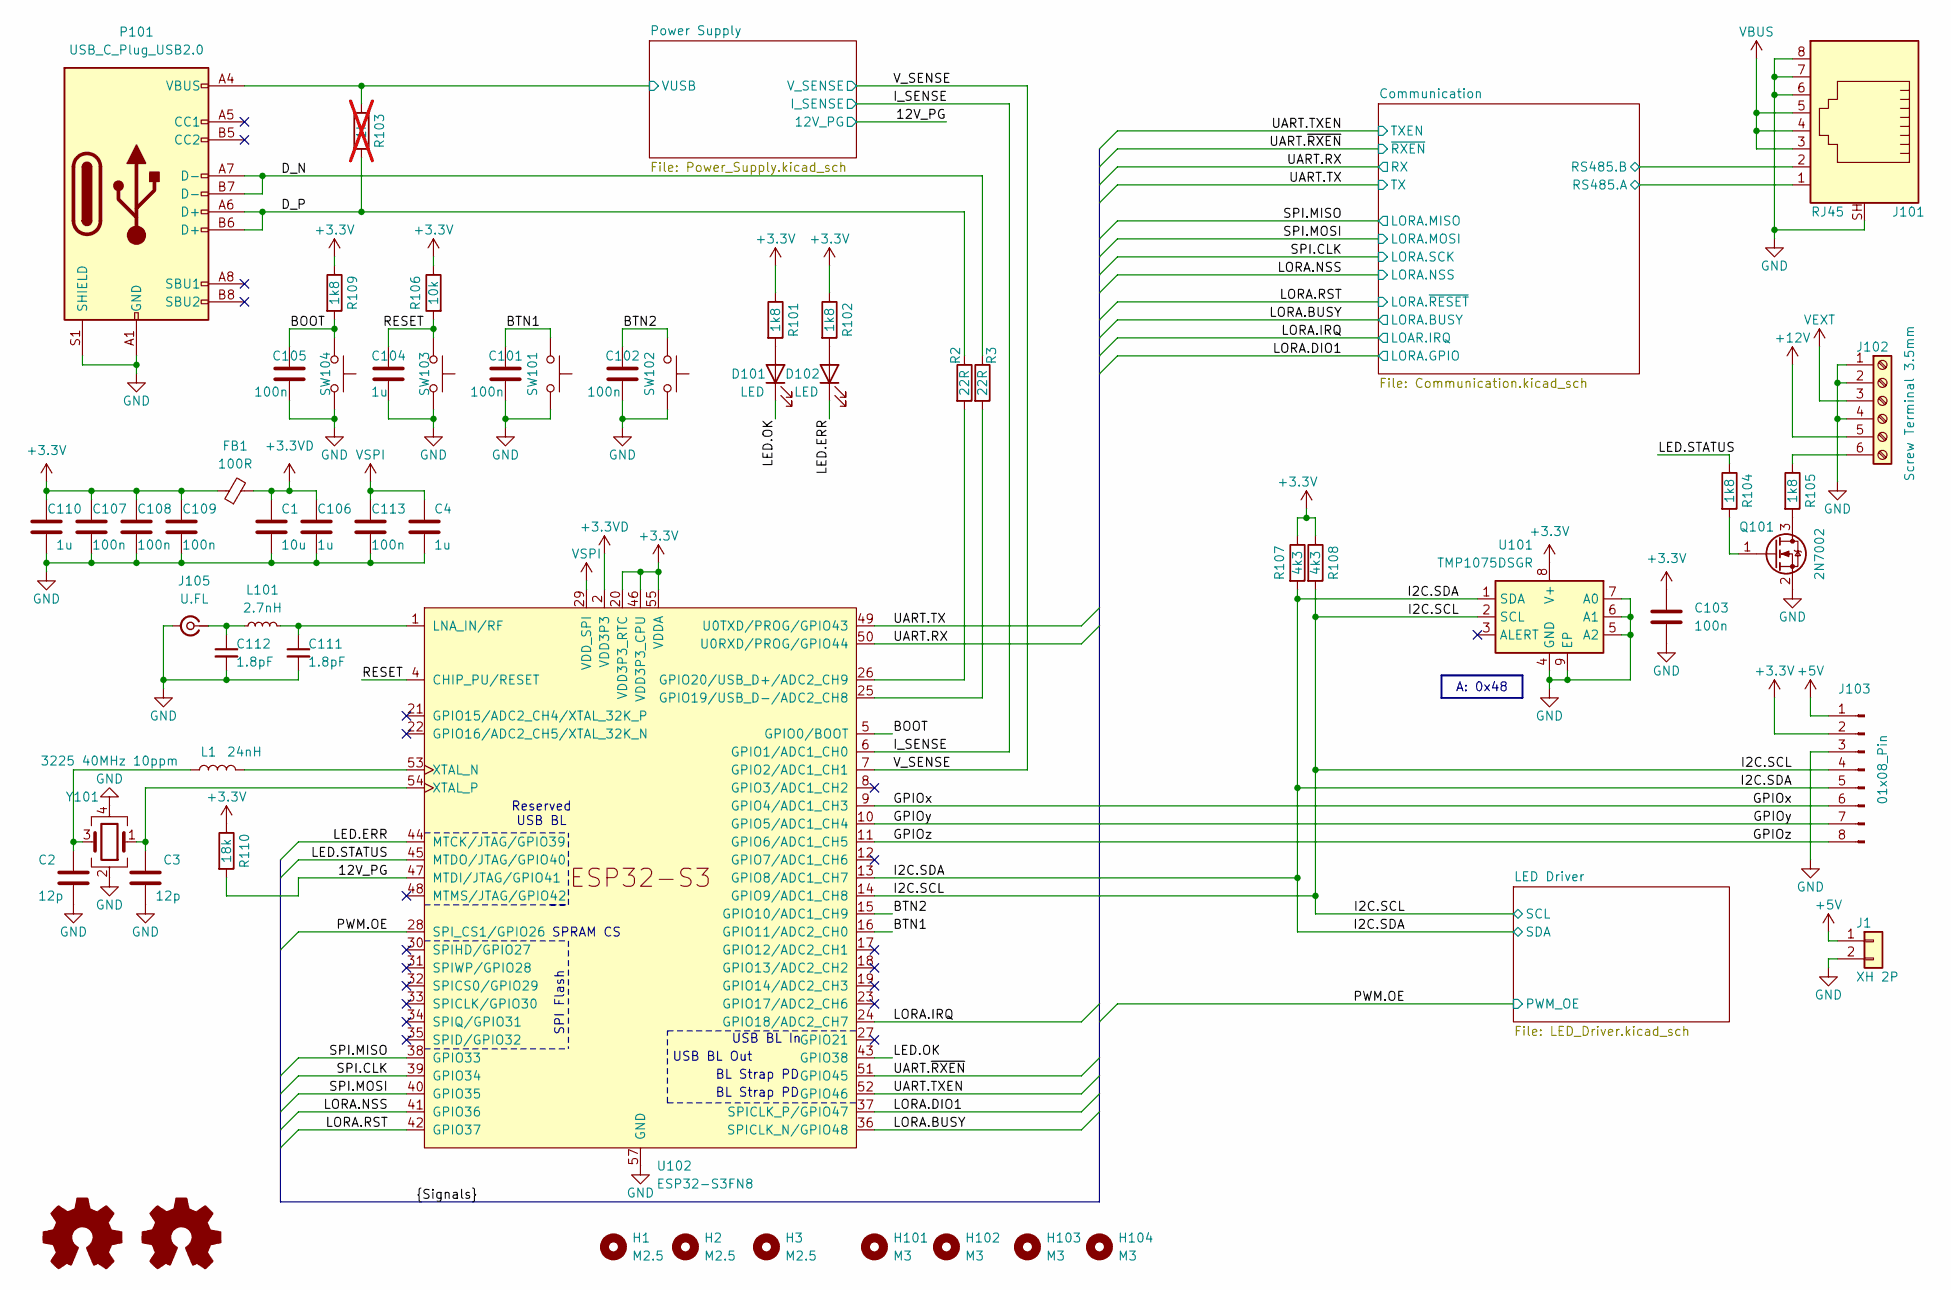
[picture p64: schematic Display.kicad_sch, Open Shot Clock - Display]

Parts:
C1: 10u; C_0603_1608Metric; LCSC Part # C19702
C2, C3: 12p; C_0402_1005Metric; LCSC Part # C76948
C4, C104, C106, C110: 1u; C_0402_1005Metric; LCSC Part # C52923
C101, C102, C103, C105, C107, C108, C109, C113: 100n; C_0402_1005Metric; LCSC Part # C307331
C111, C112: 1.8pF; C_0402_1005Metric; LCSC Part # C5186870
D101, D102: LED; LED_0603_1608Metric; LCSC Part # C2286
FB1: 100R; L_0603_1608Metric; LCSC Part # C14709
H1, H2, H3: M2.5; MountingHole_2.7mm_M2.5_DIN965
H101, H102, H103, H104: M3; MountingHole_3.2mm_M3
J1: XH 2P; JST_XH_B2B-XH-A_1x02_P2.50mm_Vertical; LCSC Part # C158012
J101: RJ45; RJ45_Amphenol_RJHSE5380; LCSC Part # C19078599
J102: Screw Terminal 3.5mm; PhoenixContact_MC_1,5_6-G-3.5_1x06_P3.50mm_Horizontal; LCSC Part # C409119
J103: 01x08_Pin; PinHeader_1x08_P2.54mm_Vertical; LCSC Part # C6332201
J105: U.FL; U.FL_Hirose_U.FL-R-SMT-1_Vertical; LCSC Part # C88374
L1: 24nH; L_0402_1005Metric; LCSC Part # C167472
L101: 2.7nH; L_0402_1005Metric; LCSC Part # C963981
P101: USB_C_Plug_USB2.0; USB_C_Receptacle_G-Switch_GT-USB-7010ASV; LCSC Part # C2927039
Q101: 2N7002; SOT-23; LCSC Part # C8545
R2, R3: 22R; R_0402_1005Metric
R101, R102, R104, R105, R109: 1k8; R_0402_1005Metric
R103: 1k; R_0402_1005Metric; not fitted
R106: 10k; R_0402_1005Metric
R107, R108: 4k3; R_0402_1005Metric
R110: 18k; R_0402_1005Metric
SW101, SW102, SW103, SW104: SW_4x3mm; SW_Push_4x3mm; LCSC Part # C18077679
SYM1: Logo_Open_Hardware_Small; OSHW-Logo2_7.3x6mm_SilkScreen
SYM2: Logo_Open_Hardware_Small; KiCad-Logo2_5mm_SilkScreen
U101: TMP1075DSGR; WSON-8-1EP_2x2mm_P0.5mm_EP0.9x1.6mm; LCSC Part # C2870250
U102: ESP32-S3FN8; QFN-56-1EP_7x7mm_P0.4mm_EP5.6x5.6mm; LCSC Part # C2913196
Y101: 3225 40MHz 10ppm; Crystal_SMD_3225-4Pin_3.2x2.5mm; LCSC Part # C37635388

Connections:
+3.3V: C103.1, C107.1, C108.1, C109.1, C110.1, FB1.1, J103.2, R101.1, R102.1, R106.1, R107.1, R108.1, R109.1, R110.1, U101.8 (V+), U102.20 (VDD3P3_RTC), U102.46 (VDD3P3_CPU), U102.55 (VDDA), U102.56 (VDDA); also elsewhere on the board
+3.3VD: C1.1, C106.1, FB1.2, U102.2 (VDD3P3), U102.3 (VDD3P3)
+5V: J1.1, J103.1; also elsewhere on the board
+12V: J102.5; also elsewhere on the board
/12V_PG: R110.2, U102.47 (MTDI/JTAG/GPIO41); also elsewhere on the board
/BOOT: C105.1, R109.2, SW104.1, U102.5 (GPIO0/BOOT)
/BTN1: C101.1, SW101.1, U102.16 (GPIO11/ADC2_CH0)
/BTN2: C102.1, SW102.1, U102.15 (GPIO10/ADC1_CH9)
/Communication/RS485.A: J101.1; also elsewhere on the board
/Communication/RS485.B: J101.2; also elsewhere on the board
/D_N: P101.A7 (D-), P101.B7 (D-), R3.1
/D_P: P101.A6 (D+), P101.B6 (D+), R2.1, R103.2
/GPIOx: J103.6, U102.9 (GPIO4/ADC1_CH3)
/GPIOy: J103.7, U102.10 (GPIO5/ADC1_CH4)
/GPIOz: J103.8, U102.11 (GPIO6/ADC1_CH5)
/I2C.SCL: J103.4, R108.2, U101.2 (SCL), U102.14 (GPIO9/ADC1_CH8); also elsewhere on the board
/I2C.SDA: J103.5, R107.2, U101.1 (SDA), U102.13 (GPIO8/ADC1_CH7); also elsewhere on the board
/I_SENSE: U102.6 (GPIO1/ADC1_CH0); also elsewhere on the board
/LED.ERR: D102.1 (K), U102.44 (MTCK/JTAG/GPIO39)
/LED.OK: D101.1 (K), U102.43 (GPIO38)
/LED.STATUS: R104.1, U102.45 (MTDO/JTAG/GPIO40)
/LORA.BUSY: U102.36 (SPICLK_N/GPIO48); also elsewhere on the board
/LORA.DIO1: U102.37 (SPICLK_P/GPIO47); also elsewhere on the board
/LORA.IRQ: U102.24 (GPIO18/ADC2_CH7); also elsewhere on the board
/LORA.NSS: U102.41 (GPIO36); also elsewhere on the board
/LORA.RST: U102.42 (GPIO37); also elsewhere on the board
/PWM.OE: U102.28 (SPI_CS1/GPIO26); also elsewhere on the board
/Power Supply/VUSB: P101.A4 (VBUS), P101.A9 (VBUS), P101.B4 (VBUS), P101.B9 (VBUS), R103.1; also elsewhere on the board
/RESET: C104.1, R106.2, SW103.1, U102.4 (CHIP_PU/RESET)
/SPI.CLK: U102.39 (GPIO34); also elsewhere on the board
/SPI.MISO: U102.38 (GPIO33); also elsewhere on the board
/SPI.MOSI: U102.40 (GPIO35); also elsewhere on the board
/UART.RX: U102.50 (U0RXD/PROG/GPIO44); also elsewhere on the board
/UART.TX: U102.49 (U0TXD/PROG/GPIO43); also elsewhere on the board
/UART.TXEN: U102.52 (GPIO46); also elsewhere on the board
/UART.~RXEN: U102.51 (GPIO45); also elsewhere on the board
/V_SENSE: U102.7 (GPIO2/ADC1_CH1); also elsewhere on the board
GND: C1.2, C2.2, C3.2, C4.2, C101.2, C102.2, C103.2, C104.2, C105.2, C106.2, C107.2, C108.2, C109.2, C110.2, C111.2, C112.2, C113.2, J1.2, J101.6, J101.7, J101.8, J101.SH, J102.1, J102.2, J102.4, J103.3, J105.2 (Ext), P101.A1 (GND), P101.A12 (GND), P101.B1 (GND), P101.B12 (GND), P101.S1 (SHIELD), Q101.2 (S), SW101.2, SW102.2, SW103.2, SW104.2, U101.4 (GND), U101.5 (A2), U101.6 (A1), U101.7 (A0), U101.9 (EP), U102.57 (GND), Y101.2, Y101.4; also elsewhere on the board
unnamed: C2.1, L1.1, Y101.3
unnamed: D101.2 (A), R101.2
unnamed: D102.2 (A), R102.2
unnamed: J102.6, R105.1
unnamed: C112.1, J105.1 (In), L101.1
unnamed: Q101.3 (D), R105.2
unnamed: Q101.1 (G), R104.2
unnamed: R3.2, U102.25 (GPIO19/USB_D-/ADC2_CH8)
unnamed: R2.2, U102.26 (GPIO20/USB_D+/ADC2_CH9)
unnamed: C111.1, L101.2, U102.1 (LNA_IN/RF)
unnamed: L1.2, U102.53 (XTAL_N)
unnamed: C3.1, U102.54 (XTAL_P), Y101.1
VBUS: J101.3, J101.4, J101.5; also elsewhere on the board
VEXT: J102.3; also elsewhere on the board
VSPI: C4.1, C113.1, U102.29 (VDD_SPI)

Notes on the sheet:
SPRAM CS
BL Strap PD
Reserved USB BL
USB BL In
SPI Flash
USB BL Out
A: 0x48

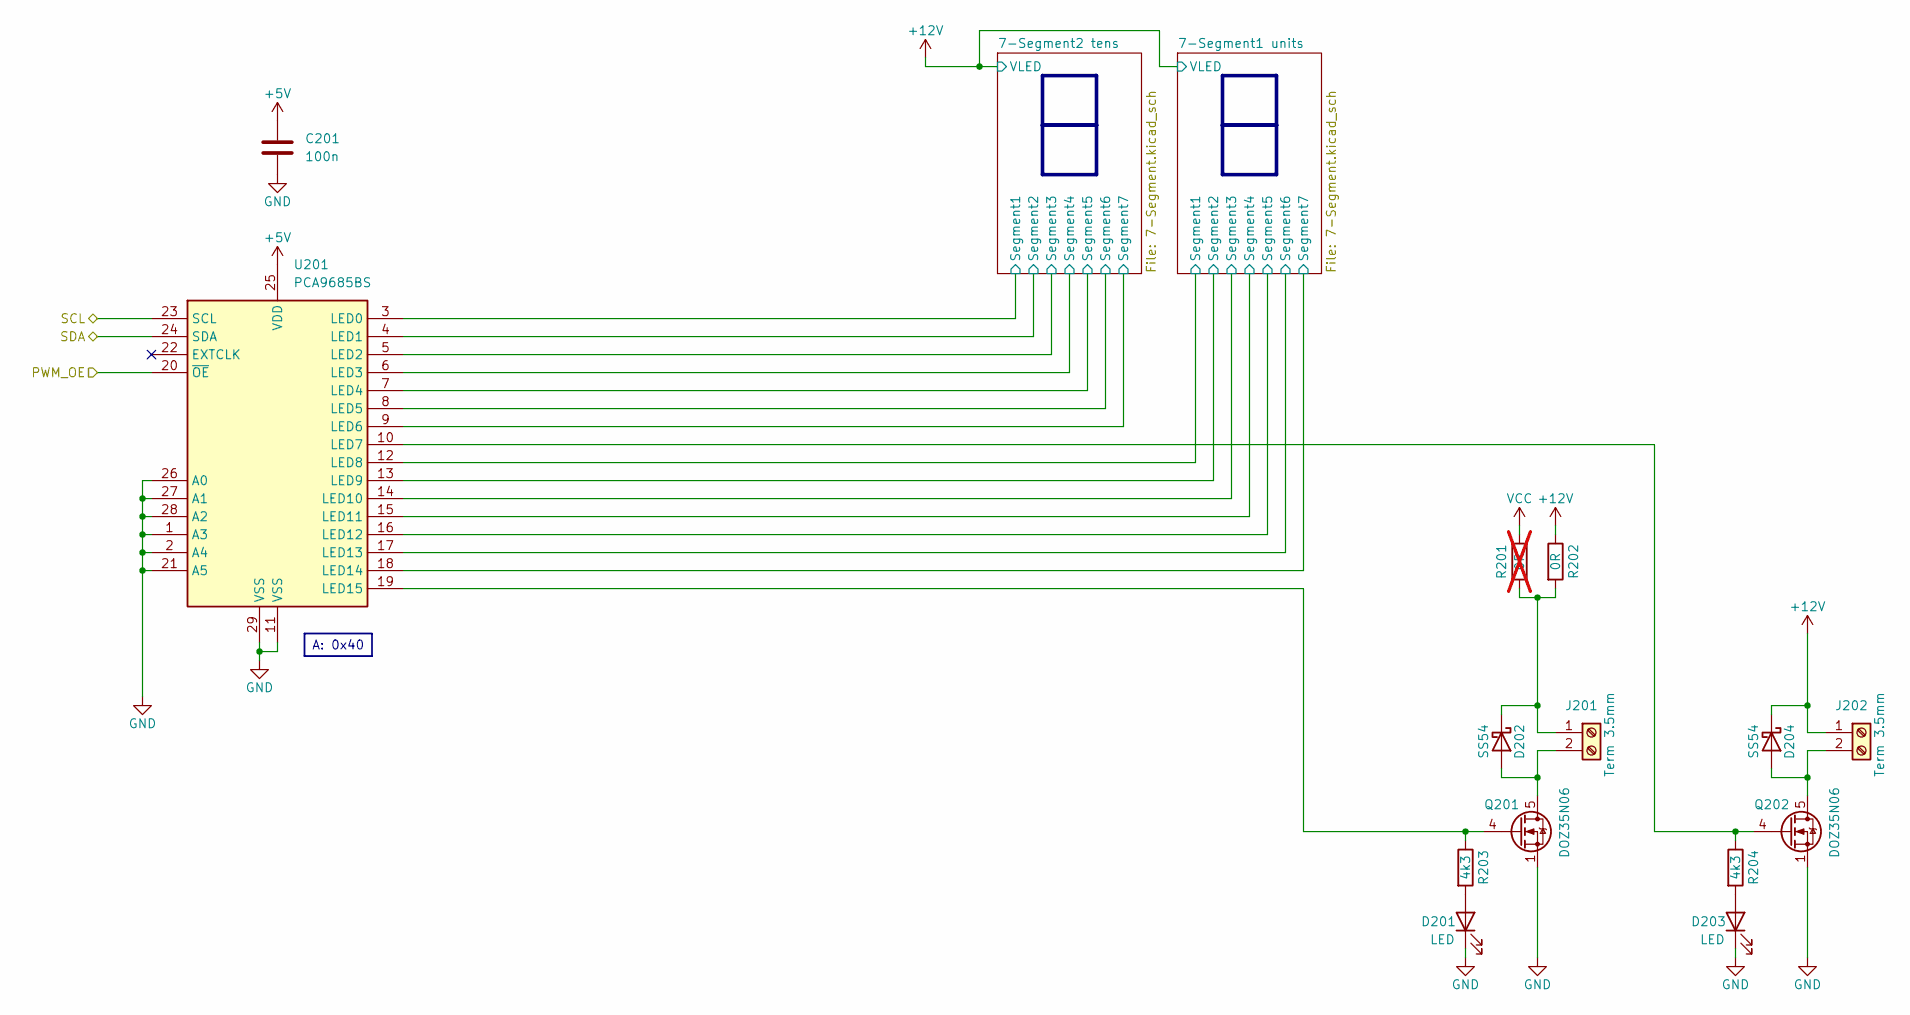
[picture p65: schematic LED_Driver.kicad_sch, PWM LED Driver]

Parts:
C201: 100n; C_0402_1005Metric; LCSC Part # C307331
D201, D203: LED; LED_0603_1608Metric; LCSC Part # C2286
D202, D204: SS54; D_SMA; LCSC Part # C22452
J201, J202: Term 3.5mm; PhoenixContact_MC_1,5_2-G-3.5_1x02_P3.50mm_Horizontal; LCSC Part # C409115
Q201, Q202: DOZ35N06; VSON-8_3.3x3.3mm_P0.65mm_Custom; LCSC Part # C36499167
R201: 0R; R_1206_3216Metric; not fitted
R202: 0R; R_1206_3216Metric
R203, R204: 4k3; R_0402_1005Metric
U201: PCA9685BS; QFN-28-1EP_6x6mm_P0.65mm_EP4.25x4.25mm; LCSC Part # C5191634

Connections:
+5V: C201.1, U201.25 (VDD); also elsewhere on the board
+12V: D204.1 (K), J202.1, R202.1; also elsewhere on the board
/I2C.SCL: U201.23 (SCL); also elsewhere on the board
/I2C.SDA: U201.24 (SDA); also elsewhere on the board
/LED Driver/7-Segment1 units/Segment1: U201.12 (LED8); also elsewhere on the board
/LED Driver/7-Segment1 units/Segment2: U201.13 (LED9); also elsewhere on the board
/LED Driver/7-Segment1 units/Segment3: U201.14 (LED10); also elsewhere on the board
/LED Driver/7-Segment1 units/Segment4: U201.15 (LED11); also elsewhere on the board
/LED Driver/7-Segment1 units/Segment5: U201.16 (LED12); also elsewhere on the board
/LED Driver/7-Segment1 units/Segment6: U201.17 (LED13); also elsewhere on the board
/LED Driver/7-Segment1 units/Segment7: U201.18 (LED14); also elsewhere on the board
/LED Driver/7-Segment2 tens/Segment1: U201.3 (LED0); also elsewhere on the board
/LED Driver/7-Segment2 tens/Segment2: U201.4 (LED1); also elsewhere on the board
/LED Driver/7-Segment2 tens/Segment3: U201.5 (LED2); also elsewhere on the board
/LED Driver/7-Segment2 tens/Segment4: U201.6 (LED3); also elsewhere on the board
/LED Driver/7-Segment2 tens/Segment5: U201.7 (LED4); also elsewhere on the board
/LED Driver/7-Segment2 tens/Segment6: U201.8 (LED5); also elsewhere on the board
/LED Driver/7-Segment2 tens/Segment7: U201.9 (LED6); also elsewhere on the board
/PWM.OE: U201.20 (~OE); also elsewhere on the board
GND: C201.2, D201.1 (K), D203.1 (K), Q201.1 (S), Q201.2 (S), Q201.3 (S), Q202.1 (S), Q202.2 (S), Q202.3 (S), U201.1 (A3), U201.2 (A4), U201.11 (VSS), U201.21 (A5), U201.26 (A0), U201.27 (A1), U201.28 (A2), U201.29 (VSS); also elsewhere on the board
unnamed: D201.2 (A), R203.2
unnamed: D202.2 (A), J201.2, Q201.5 (D)
unnamed: D202.1 (K), J201.1, R201.1, R202.2
unnamed: D203.2 (A), R204.2
unnamed: D204.2 (A), J202.2, Q202.5 (D)
unnamed: Q201.4 (G), R203.1, U201.19 (LED15)
unnamed: Q202.4 (G), R204.1, U201.10 (LED7)
VCC: R201.2; also elsewhere on the board

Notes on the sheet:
A: 0x40

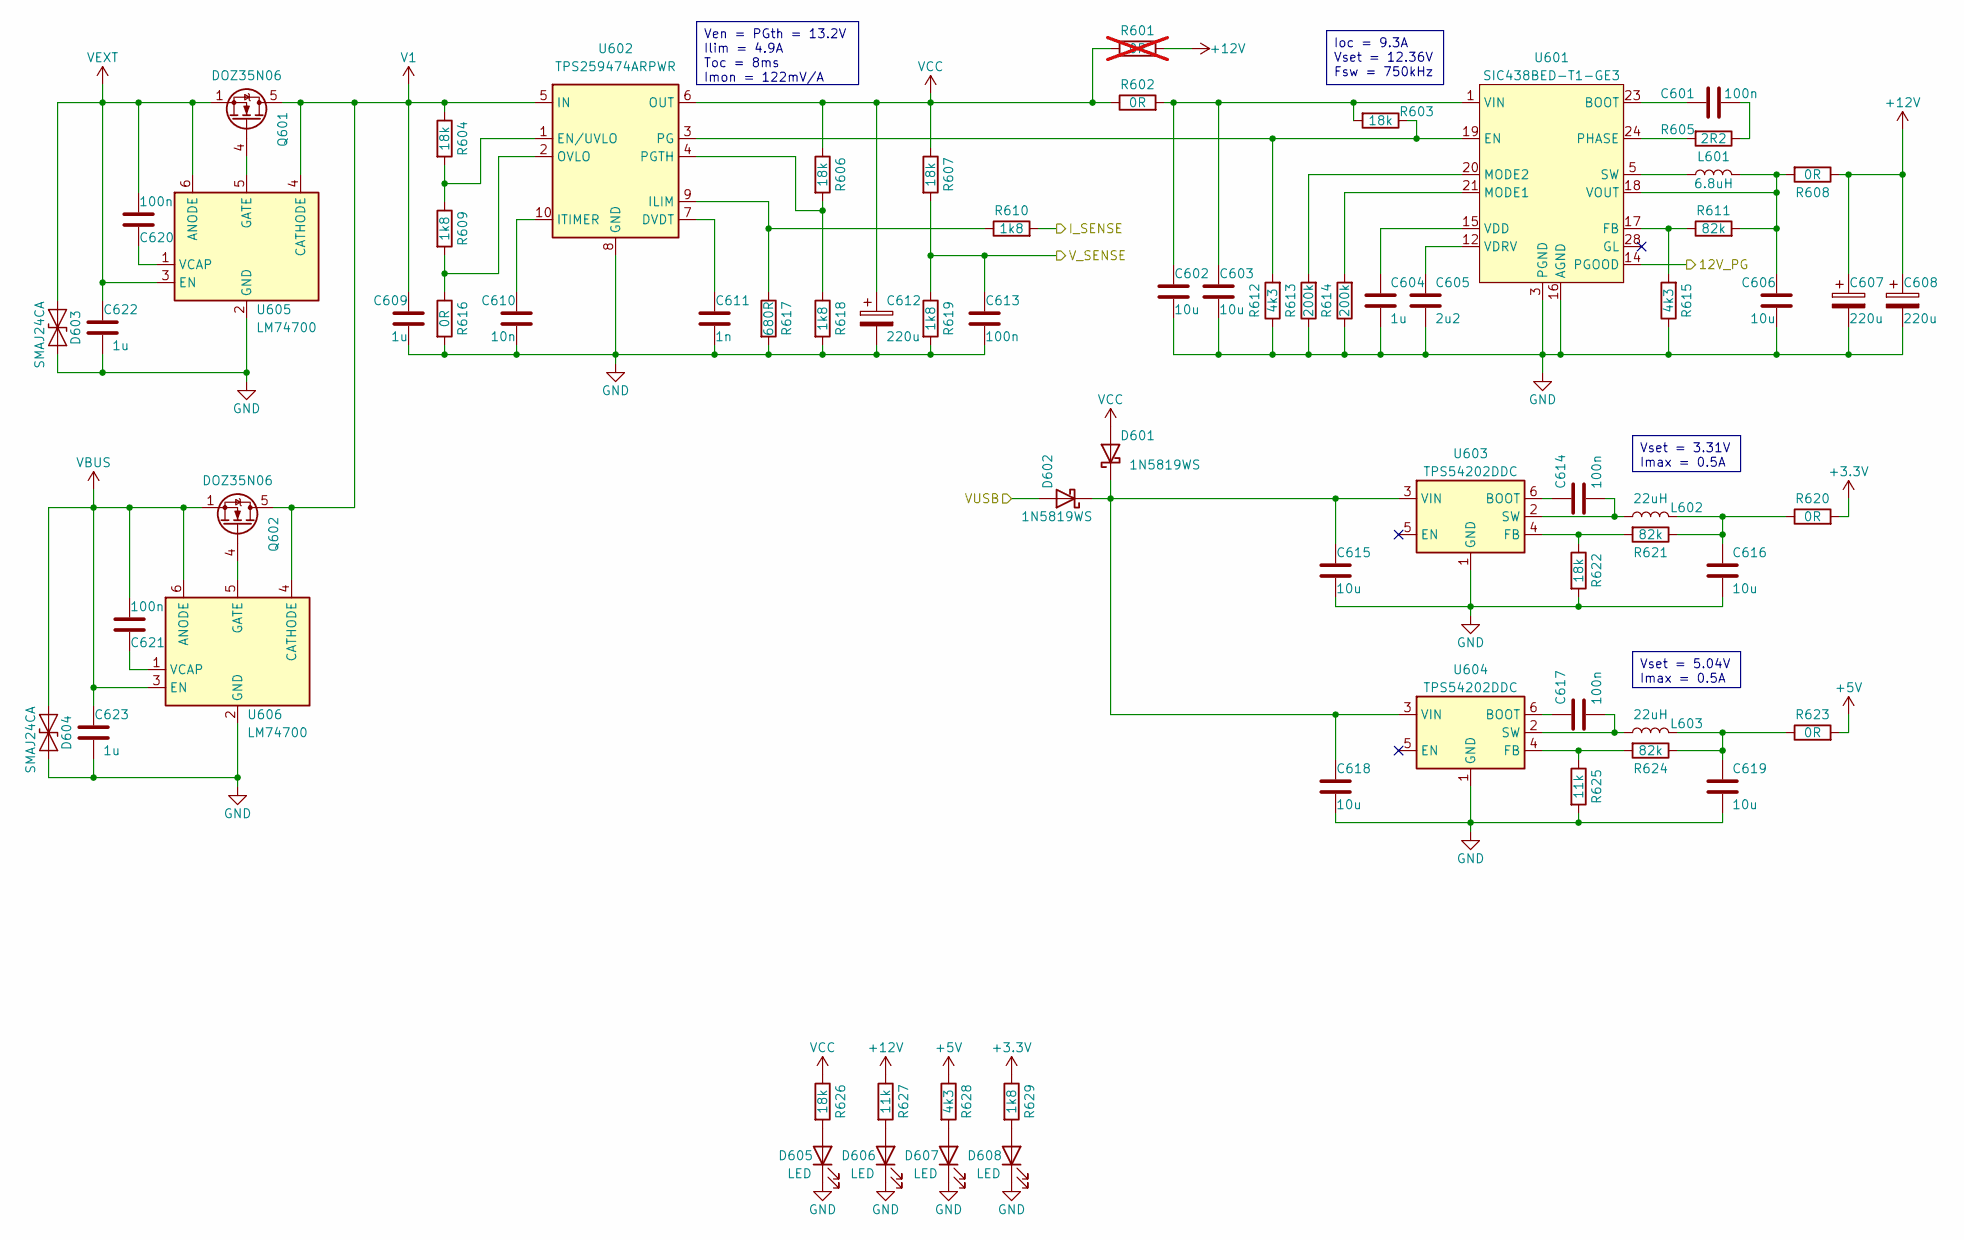
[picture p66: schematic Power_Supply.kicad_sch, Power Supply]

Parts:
C601, C613, C614, C617, C620, C621: 100n; C_0402_1005Metric; LCSC Part # C307331
C602, C603, C606, C615, C618: 10u; C_1206_3216Metric; LCSC Part # C13585
C604, C609, C622, C623: 1u; C_0603_1608Metric; LCSC Part # C15849
C605: 2u2; C_0603_1608Metric; LCSC Part # C23630
C607, C608, C612: 220u; CP_Elec_8x10; LCSC Part # C5246542
C610: 10n; C_0402_1005Metric; LCSC Part # C15195
C611: 1n; C_0402_1005Metric; LCSC Part # C1523
C616, C619: 10u; C_0603_1608Metric; LCSC Part # C19702
D601, D602: 1N5819WS; D_SOD-323; LCSC Part # C191023
D603, D604: SMAJ24CA; D_SMA; LCSC Part # C20883150
D605, D606, D607, D608: LED; LED_0603_1608Metric; LCSC Part # C2286
L601: 6.8uH; L_Bourns_SRP1050WA; LCSC Part # C32712978
L602, L603: 22uH; L_Changjiang_FNR4030S; LCSC Part # C206327
Q601, Q602: DOZ35N06; VSON-8_3.3x3.3mm_P0.65mm_Custom; LCSC Part # C36499167
R601: 0R; R_1206_3216Metric; not fitted
R602, R608: 0R; R_1206_3216Metric
R603, R604, R606, R607, R622, R626: 18k; R_0402_1005Metric
R605: 2R2; R_0402_1005Metric
R609, R610, R618, R619, R629: 1k8; R_0402_1005Metric
R611, R621, R624: 82k; R_0402_1005Metric
R612, R615, R628: 4k3; R_0402_1005Metric
R613, R614: 200k; R_0402_1005Metric
R616: 0R; R_0402_1005Metric
R617: 680R; R_0402_1005Metric
R620, R623: 0R; R_0603_1608Metric
R625, R627: 11k; R_0402_1005Metric
U601: SIC438BED-T1-GE3; Vishay_PowerPAK_MLP44-24L_ThermalVias; LCSC Part # C511430
U602: TPS259474ARPWR; RPW0010A_VQFN-HR-10; LCSC Part # C3662807
U603, U604: TPS54202DDC; SOT-23-6; LCSC Part # C191884
U605, U606: LM74700; SOT-23-6; LCSC Part # C2941042

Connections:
+3.3V: R620.2, R629.1; also elsewhere on the board
+5V: R623.2, R628.1; also elsewhere on the board
+12V: C607.1, C608.1, R601.2, R608.1, R627.1; also elsewhere on the board
/12V_PG: U601.14 (PGOOD); also elsewhere on the board
/I_SENSE: R610.2; also elsewhere on the board
/Power Supply/VUSB: D602.2 (A); also elsewhere on the board
/V_SENSE: C613.2, R607.2, R619.1; also elsewhere on the board
GND: C602.2, C603.2, C604.2, C605.2, C606.2, C607.2, C608.2, C609.1, C610.1, C611.1, C612.2, C613.1, C615.2, C616.2, C618.2, C619.2, C622.2, C623.2, D603.2 (A2), D604.2 (A2), D605.1 (K), D606.1 (K), D607.1 (K), D608.1 (K), R612.1, R613.1, R614.1, R615.1, R616.2, R617.2, R618.2, R619.2, R622.2, R625.2, U601.3 (PGND), U601.4 (PGND), U601.13 (PGND), U601.16 (AGND), U601.25 (AGND), U601.27 (PGND), U602.8 (GND), U603.1 (GND), U604.1 (GND), U605.2 (GND), U606.2 (GND); also elsewhere on the board
unnamed: C601.2, R605.1
unnamed: C616.1, L602.2, R620.1, R621.1
unnamed: C619.1, L603.2, R623.1, R624.1
unnamed: C615.1, C618.1, D601.1 (K), D602.1 (K), U603.3 (VIN), U604.3 (VIN)
unnamed: D605.2 (A), R626.2
unnamed: D606.2 (A), R627.2
unnamed: D607.2 (A), R628.2
unnamed: D608.2 (A), R629.2
unnamed: Q601.4 (G), U605.5 (GATE)
unnamed: Q602.4 (G), U606.5 (GATE)
unnamed: C601.1, U601.23 (BOOT)
unnamed: R603.1, R612.2, U601.19 (EN), U602.3 (PG)
unnamed: R611.1, R615.2, U601.17 (FB)
unnamed: R614.2, U601.21 (MODE1)
unnamed: R613.2, U601.20 (MODE2)
unnamed: R605.2, U601.24 (PHASE)
unnamed: C604.1, U601.15 (VDD)
unnamed: C605.1, U601.12 (VDRV)
unnamed: C606.1, L601.2, R608.2, R611.2, U601.18 (VOUT)
unnamed: C611.2, U602.7 (DVDT)
unnamed: R604.2, R609.1, U602.1 (EN/UVLO)
unnamed: R610.1, R617.1, U602.9 (ILIM)
unnamed: C610.2, U602.10 (ITIMER)
unnamed: R609.2, R616.1, U602.2 (OVLO)
unnamed: R606.2, R618.1, U602.4 (PGTH)
unnamed: C614.1, U603.6 (BOOT)
unnamed: R621.2, R622.1, U603.4 (FB)
unnamed: C614.2, L602.1, U603.2 (SW)
unnamed: C617.1, U604.6 (BOOT)
unnamed: R624.2, R625.1, U604.4 (FB)
unnamed: C617.2, L603.1, U604.2 (SW)
unnamed: C620.2, U605.1 (VCAP)
unnamed: C621.2, U606.1 (VCAP)
SW: L601.1, U601.5 (SW), U601.6 (SW), U601.7 (SW), U601.8 (SW), U601.9 (SW)
V1: C609.2, Q601.5 (D), Q602.5 (D), R604.1, U602.5 (IN), U605.4 (CATHODE), U606.4 (CATHODE)
VBUS: C621.1, C623.1, D604.1 (A1), Q602.1 (S), Q602.2 (S), Q602.3 (S), U606.3 (EN), U606.6 (ANODE); also elsewhere on the board
VCC: C612.1, D601.2 (A), R601.1, R602.1, R606.1, R607.1, R626.1, U602.6 (OUT); also elsewhere on the board
VEXT: C620.1, C622.1, D603.1 (A1), Q601.1 (S), Q601.2 (S), Q601.3 (S), U605.3 (EN), U605.6 (ANODE); also elsewhere on the board
VIN: C602.1, C603.1, R602.2, R603.2, U601.1 (VIN), U601.2 (VIN), U601.22 (VIN), U601.26 (VIN)

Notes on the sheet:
Vset = 3.31V Imax = 0.5A
Ven = PGth = 13.2V Ilim = 4.9A Toc = 8ms Imon = 122mV/A
Vset = 5.04V Imax = 0.5A
Ioc = 9.3A Vset = 12.36V Fsw = 750kHz

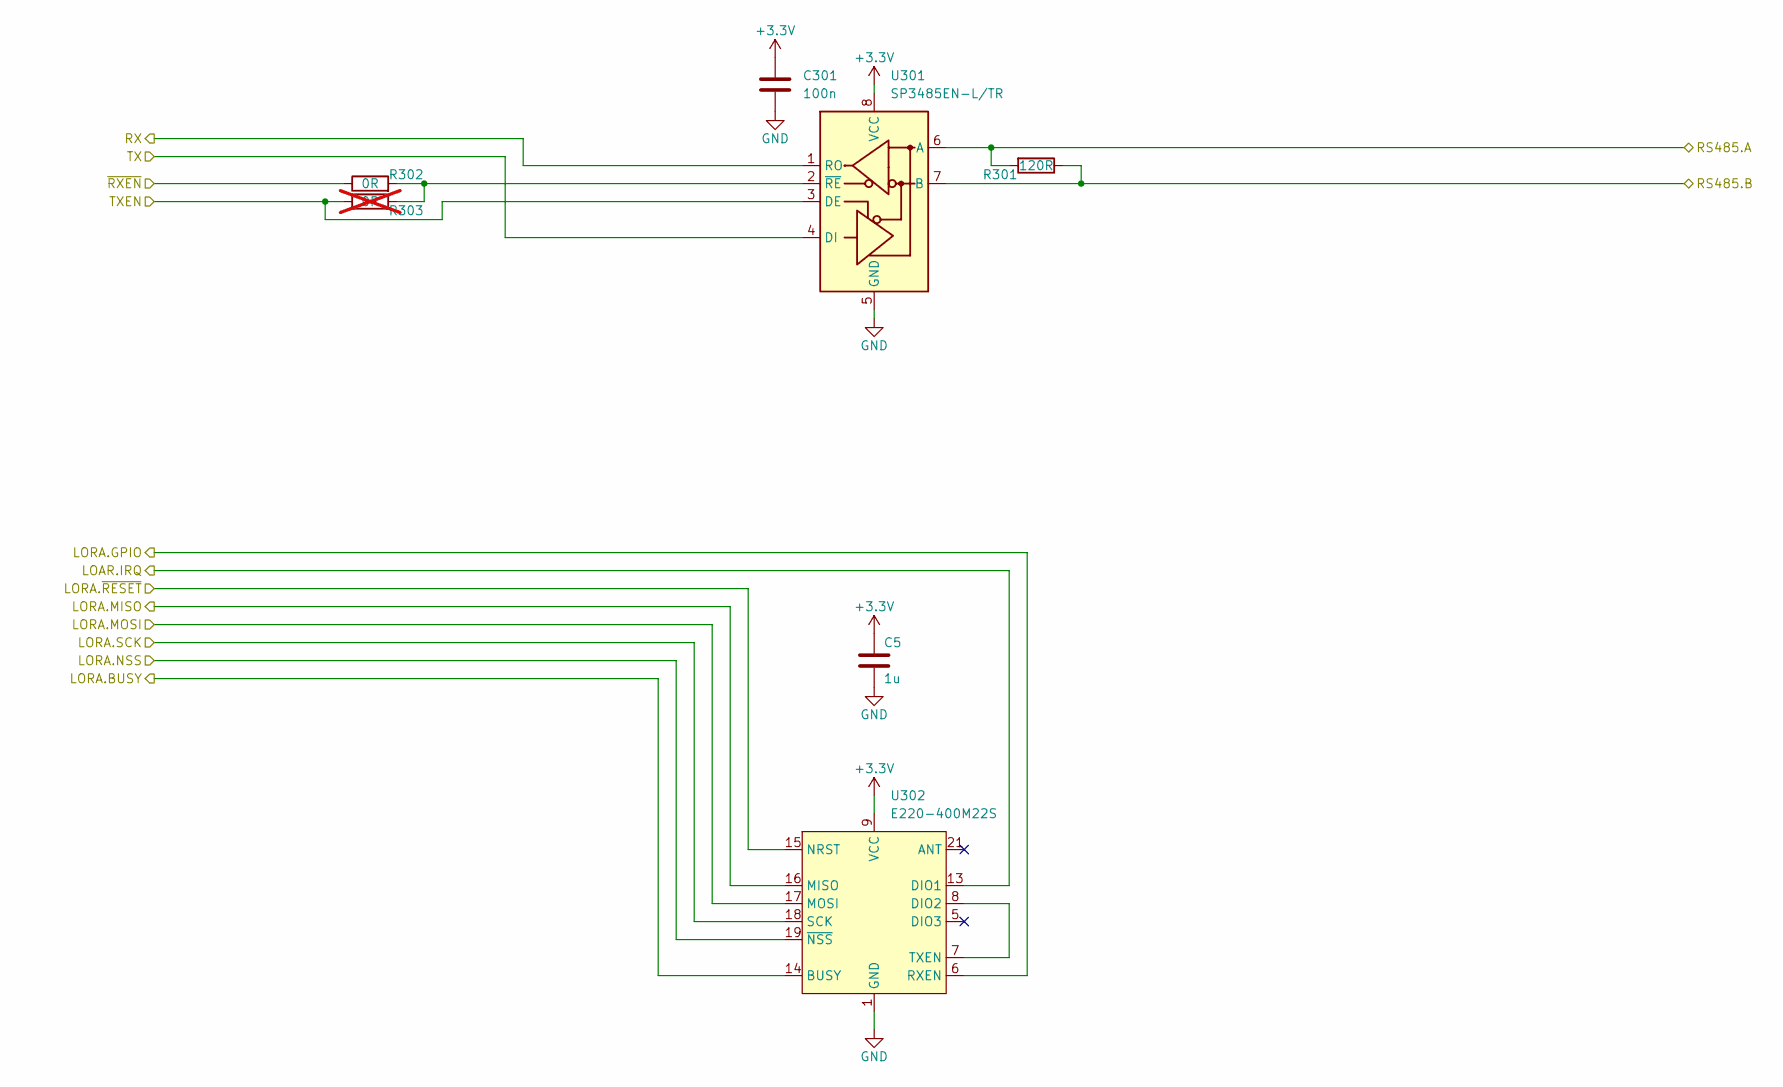
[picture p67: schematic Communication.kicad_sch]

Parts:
C5: 1u; C_0402_1005Metric; LCSC Part # C52923
C301: 100n; C_0402_1005Metric; LCSC Part # C307331
R301: 120R; R_0805_2012Metric
R302: 0R; R_0603_1608Metric
R303: 0R; R_0603_1608Metric; not fitted
U301: SP3485EN-L/TR; SOIC-8_3.9x4.9mm_P1.27mm; LCSC Part # C8963
U302: E220-400M22S; LCSC Part # C2971737

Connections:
+3.3V: C5.1, C301.1, U301.8 (VCC), U302.9 (VCC); also elsewhere on the board
/Communication/RS485.A: R301.2, U301.6 (A); also elsewhere on the board
/Communication/RS485.B: R301.1, U301.7 (B); also elsewhere on the board
/LORA.BUSY: U302.14 (BUSY); also elsewhere on the board
/LORA.DIO1: U302.6 (RXEN); also elsewhere on the board
/LORA.IRQ: U302.13 (DIO1); also elsewhere on the board
/LORA.NSS: U302.19 (~NSS); also elsewhere on the board
/LORA.RST: U302.15 (NRST); also elsewhere on the board
/SPI.CLK: U302.18 (SCK); also elsewhere on the board
/SPI.MISO: U302.16 (MISO); also elsewhere on the board
/SPI.MOSI: U302.17 (MOSI); also elsewhere on the board
/UART.RX: U301.1 (RO); also elsewhere on the board
/UART.TX: U301.4 (DI); also elsewhere on the board
/UART.TXEN: R303.1, U301.3 (DE); also elsewhere on the board
/UART.~RXEN: R302.1; also elsewhere on the board
GND: C5.2, C301.2, U301.5 (GND), U302.1 (GND), U302.2 (GND), U302.3 (GND), U302.4 (GND), U302.10 (GND), U302.11 (GND), U302.12 (GND), U302.20 (GND), U302.22 (GND); also elsewhere on the board
unnamed: R302.2, R303.2, U301.2 (~RE)
unnamed: U302.7 (TXEN), U302.8 (DIO2)

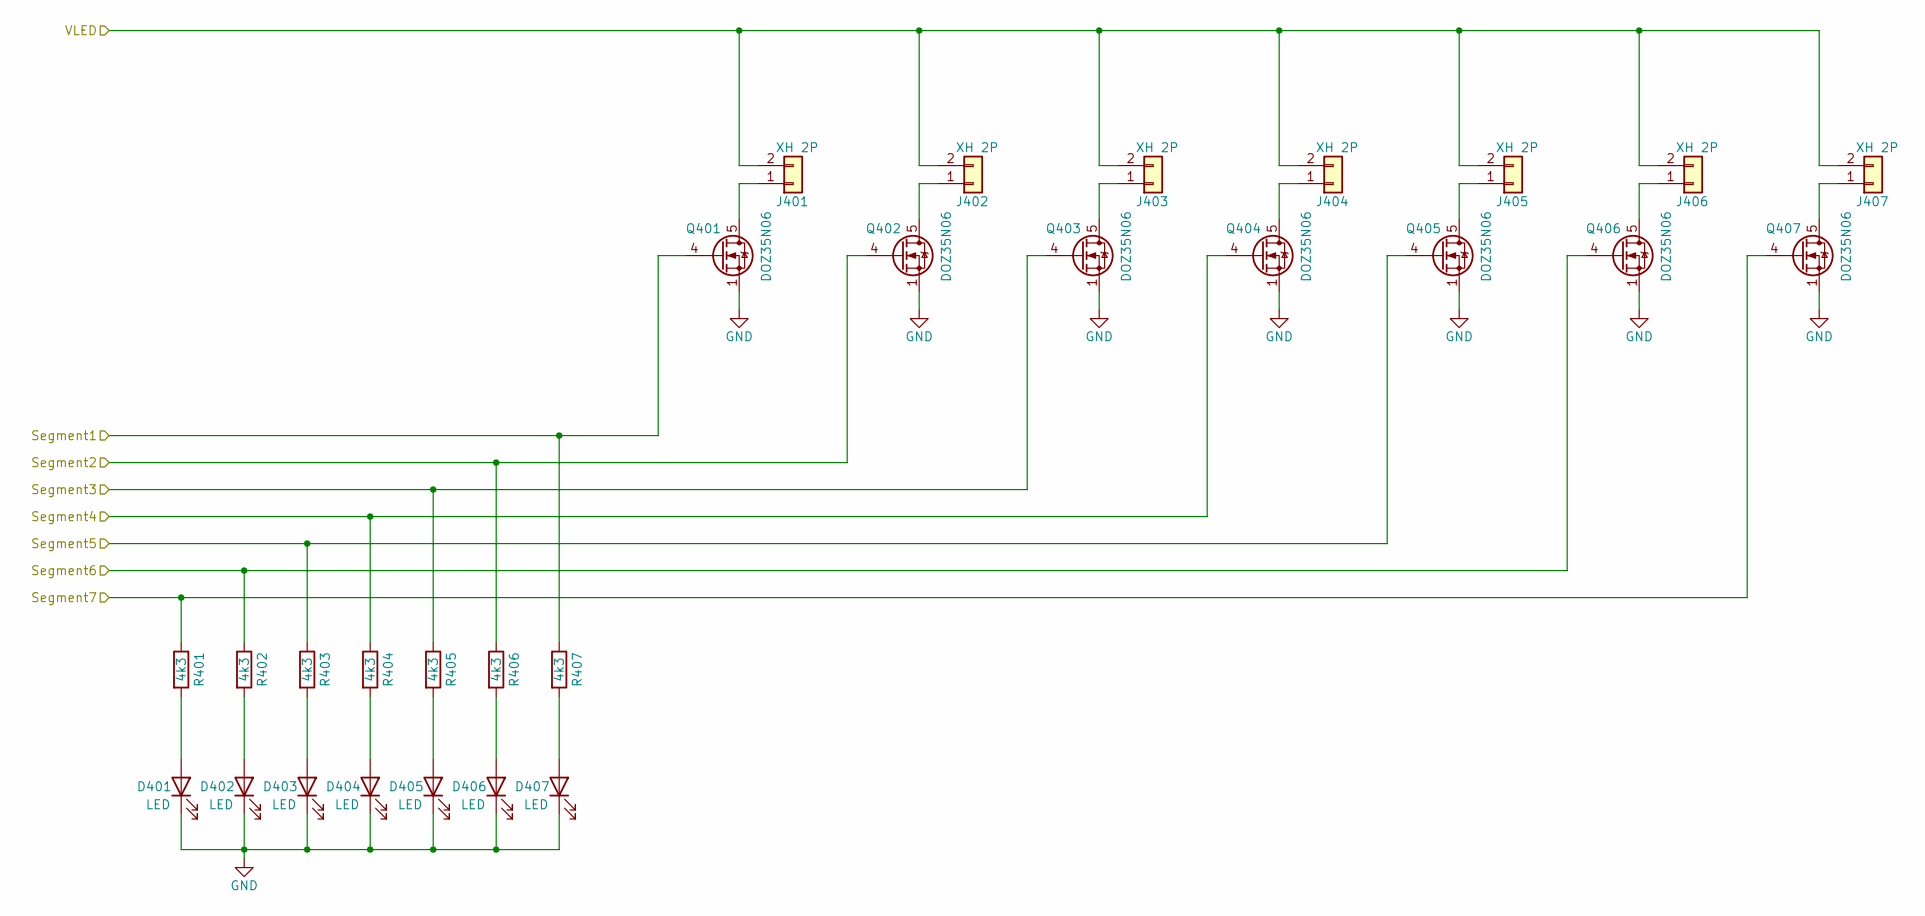
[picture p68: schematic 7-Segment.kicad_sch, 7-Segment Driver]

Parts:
D401, D402, D403, D404, D405, D406, D407: LED; LED_0603_1608Metric; LCSC Part # C2286
J401, J402, J403, J404, J405, J406, J407: XH 2P; JST_XH_B2B-XH-A_1x02_P2.50mm_Vertical; LCSC Part # C158012
Q401, Q402, Q403, Q404, Q405, Q406, Q407: DOZ35N06; VSON-8_3.3x3.3mm_P0.65mm_Custom; LCSC Part # C36499167
R401, R402, R403, R404, R405, R406, R407: 4k3; R_0402_1005Metric

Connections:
+12V: J401.2, J402.2, J403.2, J404.2, J405.2, J406.2, J407.2; also elsewhere on the board
/LED Driver/7-Segment1 units/Segment1: Q401.4 (G), R407.1; also elsewhere on the board
/LED Driver/7-Segment1 units/Segment2: Q402.4 (G), R406.1; also elsewhere on the board
/LED Driver/7-Segment1 units/Segment3: Q403.4 (G), R405.1; also elsewhere on the board
/LED Driver/7-Segment1 units/Segment4: Q404.4 (G), R404.1; also elsewhere on the board
/LED Driver/7-Segment1 units/Segment5: Q405.4 (G), R403.1; also elsewhere on the board
/LED Driver/7-Segment1 units/Segment6: Q406.4 (G), R402.1; also elsewhere on the board
/LED Driver/7-Segment1 units/Segment7: Q407.4 (G), R401.1; also elsewhere on the board
GND: D401.1 (K), D402.1 (K), D403.1 (K), D404.1 (K), D405.1 (K), D406.1 (K), D407.1 (K), Q401.1 (S), Q401.2 (S), Q401.3 (S), Q402.1 (S), Q402.2 (S), Q402.3 (S), Q403.1 (S), Q403.2 (S), Q403.3 (S), Q404.1 (S), Q404.2 (S), Q404.3 (S), Q405.1 (S), Q405.2 (S), Q405.3 (S), Q406.1 (S), Q406.2 (S), Q406.3 (S), Q407.1 (S), Q407.2 (S), Q407.3 (S); also elsewhere on the board
unnamed: D401.2 (A), R401.2
unnamed: D402.2 (A), R402.2
unnamed: D403.2 (A), R403.2
unnamed: D404.2 (A), R404.2
unnamed: D405.2 (A), R405.2
unnamed: D406.2 (A), R406.2
unnamed: D407.2 (A), R407.2
unnamed: J401.1, Q401.5 (D)
unnamed: J402.1, Q402.5 (D)
unnamed: J403.1, Q403.5 (D)
unnamed: J404.1, Q404.5 (D)
unnamed: J405.1, Q405.5 (D)
unnamed: J406.1, Q406.5 (D)
unnamed: J407.1, Q407.5 (D)

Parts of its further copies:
D501, D502, D503, D504, D505, D506, D507: LED; LED_0603_1608Metric; LCSC Part # C2286
J501, J502, J503, J504, J505, J506, J507: XH 2P; JST_XH_B2B-XH-A_1x02_P2.50mm_Vertical; LCSC Part # C158012
Q501, Q502, Q503, Q504, Q505, Q506, Q507: DOZ35N06; VSON-8_3.3x3.3mm_P0.65mm_Custom; LCSC Part # C36499167
R501, R502, R503, R504, R505, R506, R507: 4k3; R_0402_1005Metric

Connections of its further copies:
+12V: J501.2, J502.2, J503.2, J504.2, J505.2, J506.2, J507.2; also elsewhere on the board
/LED Driver/7-Segment2 tens/Segment1: Q501.4 (G), R507.1; also elsewhere on the board
/LED Driver/7-Segment2 tens/Segment2: Q502.4 (G), R506.1; also elsewhere on the board
/LED Driver/7-Segment2 tens/Segment3: Q503.4 (G), R505.1; also elsewhere on the board
/LED Driver/7-Segment2 tens/Segment4: Q504.4 (G), R504.1; also elsewhere on the board
/LED Driver/7-Segment2 tens/Segment5: Q505.4 (G), R503.1; also elsewhere on the board
/LED Driver/7-Segment2 tens/Segment6: Q506.4 (G), R502.1; also elsewhere on the board
/LED Driver/7-Segment2 tens/Segment7: Q507.4 (G), R501.1; also elsewhere on the board
GND: D501.1 (K), D502.1 (K), D503.1 (K), D504.1 (K), D505.1 (K), D506.1 (K), D507.1 (K), Q501.1 (S), Q501.2 (S), Q501.3 (S), Q502.1 (S), Q502.2 (S), Q502.3 (S), Q503.1 (S), Q503.2 (S), Q503.3 (S), Q504.1 (S), Q504.2 (S), Q504.3 (S), Q505.1 (S), Q505.2 (S), Q505.3 (S), Q506.1 (S), Q506.2 (S), Q506.3 (S), Q507.1 (S), Q507.2 (S), Q507.3 (S); also elsewhere on the board
unnamed: D501.2 (A), R501.2
unnamed: D502.2 (A), R502.2
unnamed: D503.2 (A), R503.2
unnamed: D504.2 (A), R504.2
unnamed: D505.2 (A), R505.2
unnamed: D506.2 (A), R506.2
unnamed: D507.2 (A), R507.2
unnamed: J501.1, Q501.5 (D)
unnamed: J502.1, Q502.5 (D)
unnamed: J503.1, Q503.5 (D)
unnamed: J504.1, Q504.5 (D)
unnamed: J505.1, Q505.5 (D)
unnamed: J506.1, Q506.5 (D)
unnamed: J507.1, Q507.5 (D)

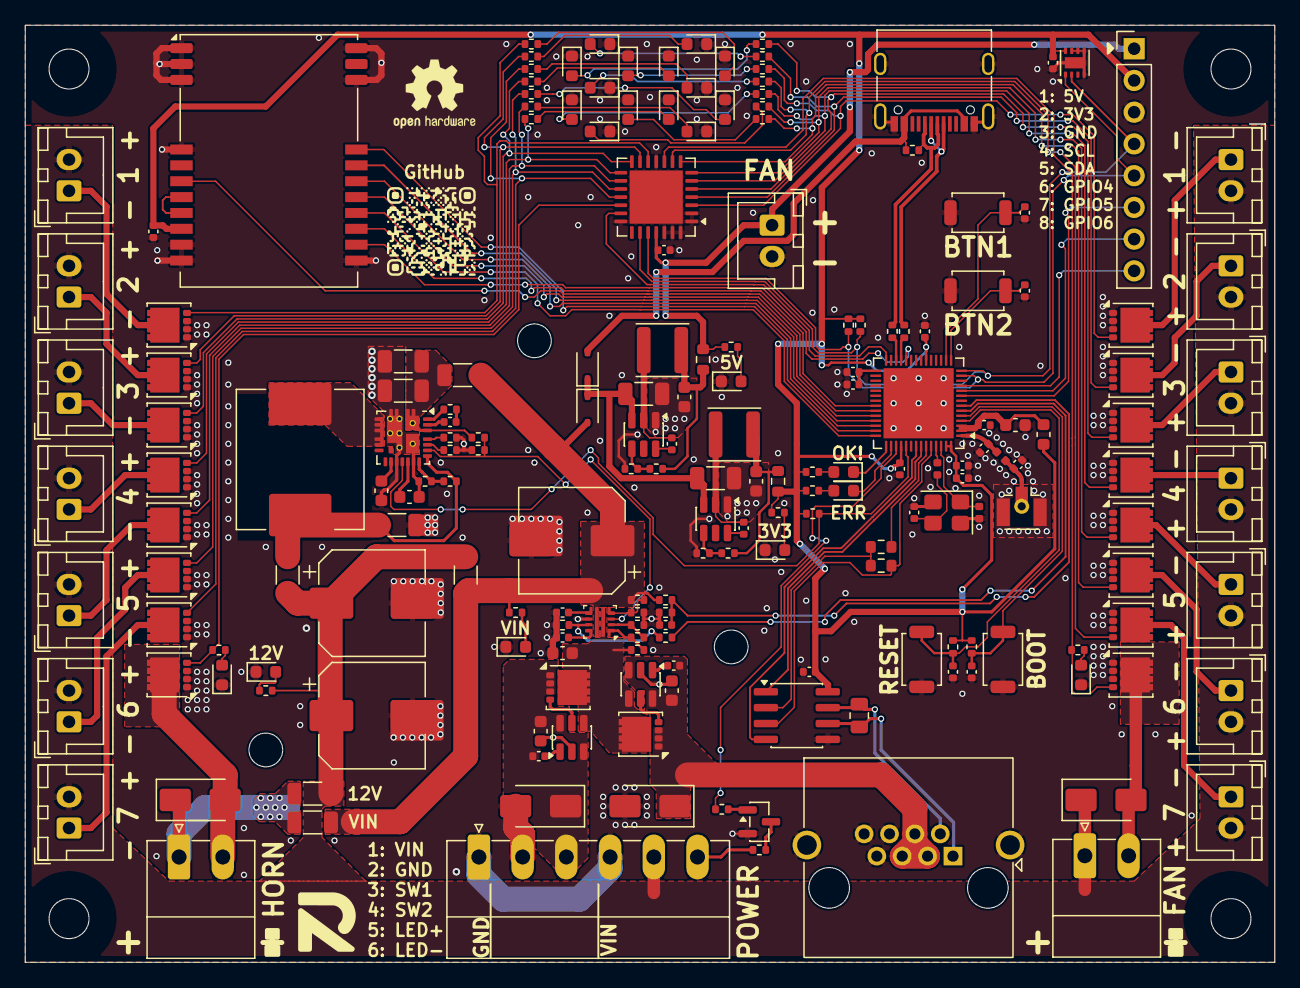
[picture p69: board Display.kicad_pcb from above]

Board: 2 copper layers, 100.0 x 75.0 mm, 205 parts (1 on the bottom side), 141 nets.

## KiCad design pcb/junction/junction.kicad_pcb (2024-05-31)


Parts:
H1, H2, H3, H4: MountingHole; MountingHole_3.2mm_M3
J1, J2, J3, J4: RJ45; RJ45_Amphenol_54602-x08_Horizontal
U1, U2, U3: RS485-TTL

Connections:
GND: J1.7, J1.8, U1.4 (GND), U2.4 (GND), U3.4 (GND)
unnamed: J4.1, U1.5 (A+)
unnamed: J4.2, U1.6 (B-)
unnamed: J4.7, J4.8, U1.7 (GND_OUT)
unnamed: J3.1, U2.5 (A+)
unnamed: J3.2, U2.6 (B-)
unnamed: J3.7, J3.8, U2.7 (GND_OUT)
unnamed: J2.1, U3.5 (A+)
unnamed: J2.2, U3.6 (B-)
unnamed: J2.7, J2.8, U3.7 (GND_OUT)
RXD: J1.3, U1.3 (RXD), U2.3 (RXD), U3.3 (RXD)
TXD: J1.6, U1.2 (TXD), U2.2 (TXD), U3.2 (TXD)
VCC: J1.4, J1.5, U1.1 (VCC), U2.1 (VCC), U3.1 (VCC)


Board: 2 copper layers, 85.0 x 65.0 mm, 11 parts (0 on the bottom side), 13 nets.

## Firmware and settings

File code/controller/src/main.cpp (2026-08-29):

#include <Arduino.h>

#include "channel.h"
#include "version.h"

#include <JC_Button.h>

#include <WiFi.h>
#include <WiFiClient.h>

#include <AsyncTCP.h>
#include <ESPAsyncWebServer.h>
#include <ElegantOTA.h>

#include <SPIFFS.h>

#include "ShotClockLogic.h"
#include "ShotClockUI.h"
#include "config.h"
#include <SCLink.h>
#include "ControllerLink.h"

#include <Preferences.h>
#include <RadioLib.h>


#define BUFF_LEN 32

#define SCREEN_WIDTH 128 // OLED display width, in pixels
#define SCREEN_HEIGHT 64 // OLED display height, in pixels
#define SCREEN_ADDRESS 0x3C

//===============================================================
// variables, constants, objects
//===============================================================
uint32_t lastTime=0, timeTelemetry=0;
uint16_t voltageRaw=0, currentRaw=0;
float voltage=0.0f;

int channel;
int defaultChannel = 1;

uint8_t syncwordSelect[5]={
  0x12,   //  not needed
  0x12,   //  Kanal 1
  0x23,   //  Kanal 2  
  0x34,   //  Kanal 3  
  0x45    //  Kanal 4
};

uint8_t syncword = syncwordSelect[defaultChannel];

float frequencySelect[5]={
  433.0F,   //  not needed
  433.0F,   //  Kanal 1
  433.5F,   //  Kanal 2  
  434.0F,   //  Kanal 3  
  434.5F   //  Kanal 4
};
float frequency = frequencySelect[defaultChannel];

String resetString = "restarting...reset your wifi connection";
String timeCommand = "T";
const char* preferenceName = "shot-clock";
const char* startTimePreferenceName = "start-time";
const char* honkVolumePreferenceName = "honk-volume";
const char* channelPreferenceName = "channel";

int _timeToDisplay; // Start Zahl
String clockStr = "30";

unsigned long timeNow;              // current time from millis()

const unsigned long LONG_PRESS(400);  // we define a "long press" to be 400 milliseconds.
const unsigned long EXTRA_LONG_PRESS(5000);
bool wasLongPress = false;

enum buttonStates_t
{
  B4_AND_B5_PRESSED,
  B5_PRESSED,
  B5_PRESSED_LONG,
  B6_PRESSED,
  B6_PRESSED_LONG,
  B4_PRESSED,
  B4_PRESSED_LONG,
  B1_PRESSED,
  B1_PRESSED_LONG,
  B2_PRESSED,
  B2_PRESSED_LONG,
  B3_PRESSED,
  B3_PRESSED_LONG,
  B1_AND_B2_PRESSED,
  NONE
};

buttonStates_t buttonState = NONE;

Button btn1(PIN_B1), // define the button
    btn2(PIN_B2),
    btn3(PIN_B3),
    btn4(PIN_B4),
    btn5(PIN_B5),
    btn6(PIN_B6);

struct ButtonConfig {
    Button* btn; 
    buttonStates_t stateShort;
    buttonStates_t stateLong;
    uint32_t pressTime;
};

static ButtonConfig configs[] = {
        {&btn1, B1_PRESSED, B1_PRESSED_LONG, LONG_PRESS},
        {&btn2, B2_PRESSED, B2_PRESSED_LONG, LONG_PRESS},
        {&btn3, B3_PRESSED, B3_PRESSED_LONG, EXTRA_LONG_PRESS},
        {&btn4, B4_PRESSED, B4_PRESSED_LONG, LONG_PRESS},
        {&btn5, B5_PRESSED, B5_PRESSED_LONG, LONG_PRESS},
        {&btn6, B6_PRESSED, B6_PRESSED_LONG, LONG_PRESS}
    };

#if defined(WIFI_LoRa_32_V2)
  SX1276 radio = new Module(SS, DIO0, RST_LoRa, DIO0);
ControllerLink protocol = ControllerLink(new Module(SS, DIO0, RST_LoRa, DIO0));
#endif

#if defined(WIFI_LoRa_32_V3)
  //SX1262 radio = new Module(SS, DIO0, RST_LoRa, BUSY_LoRa);
ControllerLink protocol = ControllerLink(new Module(SS, DIO0, RST_LoRa, BUSY_LoRa));
#endif
#if defined(OSC_CONTROLLER_R0) | defined(OSC_CONTROLLER_R1)
  SPIClass spi(HSPI);
  SPISettings spiSettings(2000000, MSBFIRST, SPI_MODE0);
  ControllerLink protocol = ControllerLink(new Module(LoRa_NSS, DIO0, RST_LoRa, BUSY_LoRa, spi, spiSettings));
#endif

ShotClockLogic shotClockLogic = ShotClockLogic(V_BAT_SENSE, V_BAT_GAIN);

AsyncWebServer server(80);
AsyncWebSocket ws("/ws");

Preferences preferences;

ShotClockUI shotclockUI = ShotClockUI(Wire, RST_OLED, OLED_nEN);

//===============================================================
// function prototypes
//===============================================================
void sendToClock(String);

//===============================================================
// functions
//===============================================================

void notifyClients(String message)
{
  ws.textAll(message);
  ws.cleanupClients();
}

void sendToClock(String Msg)
{
  String msgWithChannel = Msg + String(channel);
  ESP_LOGI("ClockMessage","Sending to clock: %s", msgWithChannel.c_str());
  // send serial for cabled clock over RS485
  Serial2.println(msgWithChannel);  
}

void updateClock(uint8_t timeToDisplay, uint8_t brightnessLevel) {
  String clockMsg;
  if (timeToDisplay < 10)
  {
    clockMsg = timeCommand + 0 + timeToDisplay + brightnessLevel;
  }
  else
  {
    clockMsg = timeCommand + timeToDisplay + brightnessLevel;
  }
  _timeToDisplay = timeToDisplay;
  sendToClock(clockMsg);
}

void honkClock(uint8_t honkVolumeLevel) {
  String commandH = "H" + String(honkVolumeLevel);
  sendToClock(commandH);
}

void sendStartTime(int T)
{
  notifyClients("SW" + T);
}

void handleWebSocketMessage(void *arg, uint8_t *data, size_t len)
{
  AwsFrameInfo *info = (AwsFrameInfo *)arg;
  if (info->final && info->index == 0 && info->len == len && info->opcode == WS_TEXT)
  {
    data[len] = 0;
    if (strcmp((char *)data, "reset") == 0)
    {
      shotClockLogic.resetClock(true);
    }
    if (strcmp((char *)data, "playpause") == 0)
    {
      shotClockLogic.playPause();
    }
    if (strcmp((char *)data, "setTime30") == 0)
    {
      shotClockLogic.resetClock(false, 30);
    }
    if (strcmp((char *)data, "setTimePlus10") == 0)
    {
      shotClockLogic.adjustTime(10);
    }
    if (strcmp((char *)data, "setTimeMinus10") == 0)
    {
      shotClockLogic.adjustTime(-10);
    }
    if (strcmp((char *)data, "setTimePlus5") == 0)
    {
      shotClockLogic.adjustTime(5);
    }
    if (strcmp((char *)data, "setTimeMinus5") == 0)
    {
      shotClockLogic.adjustTime(-5);
    }
    if (strcmp((char *)data, "setTimePlus1") == 0)
    {
      shotClockLogic.adjustTime(1);
    }
    if (strcmp((char *)data, "setTimeMinus1") == 0)
    {
      shotClockLogic.adjustTime(-1);
    }
    if (strcmp((char *)data, "SW") == 0)
    {
      sendStartTime(shotClockLogic.getResetTime());
    }
  }
}

void onEvent(AsyncWebSocket *server, AsyncWebSocketClient *client, AwsEventType type, void *arg, uint8_t *data, size_t len)
{
  switch (type)
  {
  case WS_EVT_CONNECT:
    ESP_LOGI("WebSocket","client #%u connected from %s\n", client->id(), client->remoteIP().toString().c_str());
    break;
  case WS_EVT_DISCONNECT:
    ESP_LOGI("WebSocket","client #%u disconnected\n", client->id());
    break;
  case WS_EVT_DATA:
    handleWebSocketMessage(arg, data, len);
    break;
  case WS_EVT_PONG:
  case WS_EVT_ERROR:
    break;
  }
}

String channelProcessor(const String &var)
{
  String links = "";
  if (var == "LINKPLACEHOLDER")
  {
    for (int c = 1; c <= 4; c++)
    {
      links += "<a class=\"pp-button";
      links += channel == c ? " pp-is-active" : "";
      links += "\" href=\"/" + String(c) + "\">Channel " + String(c) + "</a>";
    }
  }
  return links;
}

String versionProcessor(const String& var)
{
  String val = "";
  if(var == "PCB_VERSION_PLACEHOLDER"){
    val = String(CONTROLLER_PCB_VERSION);
  }
  if(var == "BOARD_VERSION_PLACEHOLDER"){
    val = String(BOARD);
  }
  if(var == "BRANCH_PLACEHOLDER"){
    val = String(BRANCH);
  }
  if(var == "TAG_PLACEHOLDER"){
    val = String(TAG);
  }
  if(var == "COMMIT_PLACEHOLDER"){
    val = String(COMMIT);
  }
  return val;
}

void setChannel(int ch)
{
  channel = ch;
  preferences.begin(preferenceName, false);
  preferences.putInt(channelPreferenceName, channel);
  Serial.println("Channel " + String(channel));
  preferences.end();
  delay(1000);
  ESP.restart();
}

void loadChannelFromEEPROM()
{
  preferences.begin(preferenceName, false);
  channel = preferences.getInt(channelPreferenceName, defaultChannel);
  syncword = syncwordSelect[channel];
  frequency = frequencySelect[channel];
  preferences.end();
}

void updateButtonState()
{
  // Update all button states first
  for (auto& c : configs) {
      c.btn->read();
  }

  // First handle special combinations of buttons
  if (btn4.isPressed() && btn5.wasReleased()) {
      buttonState = B4_AND_B5_PRESSED;
      //wasLongPress = true;
      return;
  }
  if (btn1.isPressed() && btn2.wasReleased()) {
      buttonState = B1_AND_B2_PRESSED;
      return;
  }

  // Evaluate all other buttons and update state
  for (auto& c : configs) {
      if (c.btn->wasReleased()) {
          if (wasLongPress) {
              wasLongPress = false; 
          } else {
              buttonState = c.stateShort;
          }
          return; 
      }
      if (c.btn->pressedFor(c.pressTime) && !wasLongPress) {
          buttonState = c.stateLong;
          wasLongPress = true;
          return;
      }
  }

  buttonState = NONE;
}

void handleButtonClicks()
{
  switch (buttonState)
  {
    case B1_PRESSED:
    case B1_PRESSED_LONG:
    case B6_PRESSED:
    case B6_PRESSED_LONG:
      shotClockLogic.playPause();
      break;
    case B2_PRESSED:
    case B2_PRESSED_LONG:
      shotClockLogic.resetClock(true);
      break;
    case B3_PRESSED:
      shotClockLogic.resetClock(false);
      break;
    case B3_PRESSED_LONG:
      shotClockLogic.toggleResetTime();
      shotClockLogic.resetClock(false);
      break;

    case B4_PRESSED:      shotClockLogic.adjustTime(-1);  break;
    case B4_PRESSED_LONG: shotClockLogic.adjustTime(-10); break;
    case B5_PRESSED:      shotClockLogic.adjustTime(1);   break;
    case B5_PRESSED_LONG: shotClockLogic.adjustTime(10);  break;

    case B4_AND_B5_PRESSED:
      shotClockLogic.honk();
      shotclockUI.showHonk(channel);
      break;
      
    default:
      break;
  }
}

//===============================================================
// Setup
//===============================================================
void initOTA()
{
  ElegantOTA.begin(&server);  // Start ElegantOTA
  server.begin();
  ESP_LOGI("OTA","HTTP server started");
}

void initWebSocket()
{
  ws.onEvent(onEvent);
  server.addHandler(&ws);
}

void initWebserver()
{
  // Route for root / web page
  server.on("/", HTTP_GET, [](AsyncWebServerRequest *request)
            { request->send(SPIFFS, "/index.html", String(), false); });

  server.on("/controller", HTTP_GET, [](AsyncWebServerRequest *request)
            { request->send(SPIFFS, "/controller.html", String(), false); });

  server.on("/settings", HTTP_GET, [](AsyncWebServerRequest *request)
            { request->send(SPIFFS, "/settings.html", String(), false, [](const String &var) -> String
                            { return shotClockLogic.settingsProcessor(var); }); });

  server.on("/version", HTTP_GET, [](AsyncWebServerRequest *request)
            { request->send(200, "text/html", version_html, versionProcessor); });

  server.on("/brightness", HTTP_GET, [](AsyncWebServerRequest *request)
            {
              if (request->hasParam("b")){
                int level = request->getParam("b")->value().toInt();
                shotClockLogic.setBrightness(level);
                request->send(200, "text/html", "brightness changed");
              }
              else{
                request->send(400, "text/plain", "missing parameters");
              } });

  server.on("/honkvolume", HTTP_GET, [](AsyncWebServerRequest *request)
            {
              if (request->hasParam("v")){
                int level = request->getParam("v")->value().toInt();
                shotClockLogic.setHonkVolumeLevel(level);
                request->send(200, "text/html", "honk volume changed");
              }
              else{
                request->send(400, "text/plain", "missing parameters");
              } });

  server.on("/starttime", HTTP_GET, [](AsyncWebServerRequest *request)
            {
              if (request->hasParam("t")){
                int time = request->getParam("t")->value().toInt();
                if (time >= 1 && time <= 99) {
                  shotClockLogic.setResetTime(time);
                  request->send(200, "text/html", "start time changed");
                } else {
                  request->send(400, "text/plain", "invalid time value: must be between 1 and 99");
                }
              }
              else{
                request->send(400, "text/plain", "missing parameters");
              } });

  // Route to load style.css file
  server.on("/style.css", HTTP_GET, [](AsyncWebServerRequest *request)
            { request->send(SPIFFS, "/style.css", "text/css"); });

  server.on("/javascript.js", HTTP_GET, [](AsyncWebServerRequest *request)
            { request->send(SPIFFS, "/javascript.js", "application/javascript"); });

  server.on("/piep.mp3", HTTP_GET, [](AsyncWebServerRequest *request)
            { request->send(SPIFFS, "/piep.mp3"); });

  server.on("/longpiep.mp3", HTTP_GET, [](AsyncWebServerRequest *request)
            { request->send(SPIFFS, "/longpiep.mp3"); });

  server.on("/digital-7-mono.ttf", HTTP_GET, [](AsyncWebServerRequest *request)
            { request->send(SPIFFS, "/digital-7-mono.ttf"); });

  server.on("/digital-7-mono.woff", HTTP_GET, [](AsyncWebServerRequest *request)
            { request->send(SPIFFS, "/digital-7-mono.woff"); });

  server.on("/digital-7-mono.woff2", HTTP_GET, [](AsyncWebServerRequest *request)
            { request->send(SPIFFS, "/digital-7-mono.woff2"); });

  server.on("/channel", HTTP_GET, [](AsyncWebServerRequest *request)
            {
            if (request->hasParam("c")) {
              int ch = request->getParam("c")->value().toInt();
              if (ch >= 1 && ch <= 4) {
                request->send(200, "text/plain", resetString);
                setChannel(ch);
              } else {
                request->send(400, "text/plain", "invalid channel");
              }
            } else {
              request->send(400, "text/plain", "missing parameters");
            } });
}

void initButtons() {
  // initialize the button objects
  btn1.begin();
  btn2.begin();
  btn3.begin();
  btn4.begin();
  btn5.begin();
  btn6.begin();
}

void setup()
{
  ESP_LOGE("Init", "START"); 
  #if defined(OSC_CONTROLLER_R0) | defined(OSC_CONTROLLER_R1)
    pinMode(PIN_PWR, OUTPUT);
    digitalWrite(PIN_PWR, HIGH);
    ESP_LOGE("Init", "As OSC R1"); 
    pinMode(V_SENSE, ANALOG);
    pinMode(I_SENSE, ANALOG);
    pinMode(LED_ERR, OUTPUT);
    pinMode(PIN_HORN, OUTPUT);
    pinMode(UART_TXEN, OUTPUT);
    digitalWrite(UART_TXEN, HIGH);
    spi.begin(LoRa_CLK, LoRa_MISO, LoRa_MOSI, LoRa_NSS);
  #endif

  #if defined(OSC_CONTROLLER_R1)
    pinMode(V_BAT_SENSE, ANALOG);
    pinMode(V_BAT_SENSE_EN, OUTPUT);
    digitalWrite(V_BAT_SENSE_EN, HIGH);
  #endif
  
  pinMode(LED_OK, OUTPUT);
  pinMode(PIN_B1, INPUT_PULLUP);
  pinMode(PIN_B2, INPUT_PULLUP);
  pinMode(PIN_B3, INPUT_PULLUP);
  pinMode(PIN_B4, INPUT_PULLUP);
  pinMode(PIN_B5, INPUT_PULLUP);

  pinMode(OLED_nEN, OUTPUT);
  digitalWrite(OLED_nEN, LOW);
  
  delay(100); 
  
  Wire.setPins(SDA, SCL);
  Wire.begin();

  #ifdef FLIPSCREEN
  shotclockUI.begin(true);
  #else
   shotclockUI.begin(false);  
   #endif
   
  loadChannelFromEEPROM();

  // RS-485
  Serial2.begin(9600, SERIAL_8N1, RXD2, TXD2);

  if (!SPIFFS.begin())
  {
    ESP_LOGE("SPIFFS","An Error has occurred while mounting SPIFFS");
    return;
  }
  ESP_LOGI("MAC","Address: %s", WiFi.macAddress().c_str());

  // ESP32 As access point
  WiFi.mode(WIFI_AP); // Access Point mode
  WiFi.softAP(ssid, password);

  IPAddress myIP = WiFi.softAPIP(); // Get IP address
  ESP_LOGI("AP", "%s", myIP.toString());

  initWebSocket();
  initWebserver();

  initOTA();

  initButtons();

  shotClockLogic.begin(&shotclockUI, &protocol, notifyClients);
  protocol.begin(&shotClockLogic, shotClockLogic.getSyncWord(), shotClockLogic.getFrequency(), 1000); // Assuming device ID is 1

  timeNow = millis();
}

//===============================================================
// loop
//===============================================================
void loop()
{
  timeNow = millis();
  shotClockLogic.handle();
  shotclockUI.handle();
  protocol.handler();

  updateButtonState();
  handleButtonClicks();

  ElegantOTA.loop();

  #if defined(OSC_CONTROLLER_R0) | defined(OSC_CONTROLLER_R1)
  if(timeNow - lastTime > 4800)
  {
    digitalWrite(LED_ERR, !digitalRead(LED_ERR));
  }  
  #endif
}

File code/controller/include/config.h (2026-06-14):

#include "board_definitions.h"

/**************************************/ 
/********* user config ****************/
/**************************************/

// WiFi config
// Enter your SSID and PASSWORD
const char *ssid = "Controller";
// password must have at least 8 characters
const char* password = "12345678";

// Screen
// uncomment to flip screen
// #define FLIPSCREEN

// PCB config 
// see board_definitions.h for available configs

#define CONTROLLER_PCB_VERSION V2_1


/**************************************/ 
/********* auto config ****************/
/**************************************/

#if CONTROLLER_PCB_VERSION == NO_BOARD
    #ifdef WIFI_LoRa_32_V2
        static const uint8_t PIN_B1 = 17;
        static const uint8_t PIN_B2 = 2;
        static const uint8_t PIN_B3 = 13;
        static const uint8_t PIN_B4 = 22;
        static const uint8_t PIN_B5 = 32;
        static const uint8_t PIN_B6 = 100;
        static const uint8_t LED_OK = 25;
    #elif defined(WIFI_LoRa_32_V3)
        static const uint8_t PIN_B1 = 6;
        static const uint8_t PIN_B2 = 5;
        static const uint8_t PIN_B3 = 4;
        static const uint8_t PIN_B4 = 7;
        static const uint8_t PIN_B5 = 2;
        static const uint8_t PIN_B6 = 3;
        static const uint8_t LED_OK = 35;
    #endif
#elif CONTROLLER_PCB_VERSION == V0_1
    #ifdef WIFI_LoRa_32_V2
        static const uint8_t PIN_B1 = 33;
        static const uint8_t PIN_B2 = 2;
        static const uint8_t PIN_B3 = 23;
        static const uint8_t PIN_B4 = 22;
        static const uint8_t PIN_B5 = 32;
        static const uint8_t PIN_B6 = 17;
        static const uint8_t LED_OK = 25;
    #elif defined(WIFI_LoRa_32_V3)
        static const uint8_t PIN_B1 = 38;
        static const uint8_t PIN_B2 = 26;
        static const uint8_t PIN_B3 = 34;
        static const uint8_t PIN_B4 = 39;
        static const uint8_t PIN_B5 = 45;
        static const uint8_t PIN_B6 = 46;
        static const uint8_t LED_OK = 35;
    #endif
#elif CONTROLLER_PCB_VERSION == V2_1
    #ifdef WIFI_LoRa_32_V2
        static const uint8_t PIN_B1 = 39;
        static const uint8_t PIN_B2 = 32;
        static const uint8_t PIN_B3 = 33;
        static const uint8_t PIN_B4 = 23;
        static const uint8_t PIN_B5 = 2;
        static const uint8_t PIN_B6 = 17;
        static const uint8_t LED_OK = 25;
    #elif defined(WIFI_LoRa_32_V3)
        static const uint8_t PIN_B1 = 42;  //J1
        static const uint8_t PIN_B2 = 39;  //J2
        static const uint8_t PIN_B3 = 38;  //J3
        static const uint8_t PIN_B4 = 34;    //J4
        static const uint8_t PIN_B5 = 26;    //J5
        static const uint8_t PIN_B6 = 20;    //J6
        static const uint8_t LED_OK = 35;
    #endif
#endif

#if defined(WIFI_LoRa_32_V3) | defined(WIFI_LoRa_32_V2)
    #define OLED_nEN        Vext
    #define SCL             SCL_OLED
    #define SDA             SDA_OLED
    #define V_BAT_SENSE     -1
    #define V_BAT_GAIN      1.0
#endif

//RS-485
#if defined(WIFI_LoRa_32_V2)
    #define RXD2            13
    #define TXD2            12
#endif

#if defined(WIFI_LoRa_32_V3)
    #define RXD2            6
    #define TXD2            5
#endif

#if defined(OSC_CONTROLLER_R0) || defined(OSC_CONTROLLER_R1)
    #define RXD2 13
    #define TXD2 12
    #define UART_TXEN 14
    #define DIO0 36
    #define RST_LoRa 48
    #define BUSY_LoRa 35
    #define LoRa_CLK 47
    #define LoRa_MISO 34
    #define LoRa_MOSI 33
    #define LoRa_NSS 21
    #define LED_ERR 16
    #define LED_OK 38

    #define OLED_nEN 11
    #define RST_OLED -1
    
    #define V_SENSE 1
    #define I_SENSE 2

    #define PIN_B1 3
    #define PIN_B2 4
    #define PIN_B3 5
    #define PIN_B4 6
    #define PIN_B5 7

    #define PIN_PWR 17

    #define PIN_HORN 15

    #define V_GAIN (2.0 / (2.0 + 20.0))
    #define I_GAIN (1/(182.0 * 1e-6 * 560))
    #define V_BAT_GAIN (10.0 / (10.0 + 4.3))
#endif

#if defined(OSC_CONTROLLER_R0)
    #define PIN_B6 10
    #define V_BAT_SENSE V_SENSE
#endif

#if defined(OSC_CONTROLLER_R1)
    #define PIN_B6 45
    #define V_BAT_SENSE 10
    #define V_BAT_SENSE_EN 37
    #define PIN_B6 45
    #define PIN_B7 44
    #define PIN_B8 43
#endif

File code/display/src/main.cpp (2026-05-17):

#include <Arduino.h>

#include <Adafruit_GFX.h>
#include <Adafruit_SSD1306.h>

#include "channel.h"
#include "version.h"
#include "font.h"

#include <WiFi.h>
#include <AsyncTCP.h>
#include <ESPAsyncWebServer.h>
#include <ElegantOTA.h>

#include <Preferences.h>
#include <Adafruit_PWMServoDriver.h>

#include "config.h"
#include "LEDs.h"
#include "Horn.h"
#include "SCLink.h"
#include "DisplayLink.h"
#include "DisplayLogic.h"

#include <RadioLib.h>

#include <Regexp.h>

String inputString = "";         // a String to hold incoming data
bool stringComplete = false;  // whether the string is complete

bool RS485mode = false;

AsyncWebServer server(80);

#if defined(WIFI_LoRa_32_V2)
  // Use the SX1276 Radio
  SX1276 radio = new Module(SS, DIO0, LoRa_RST, DIO0);
  Adafruit_PWMServoDriver pwm = Adafruit_PWMServoDriver(0x40, Wire);
  Adafruit_SSD1306 display(128, 64, &Wire, RST_OLED);
#endif

#if defined(WIFI_LoRa_32_V3)
  // Use the SX1262 Radio
  DisplayLink protocol = DisplayLink(new Module(SS, DIO0, LoRa_RST, LoRa_BUSY));
  // Use Wire1 Object, because OLED uses the other one, that is not usable through pins
  Adafruit_PWMServoDriver pwm = Adafruit_PWMServoDriver(0x40, Wire1);
  Adafruit_SSD1306 display(128, 64, &Wire, RST_OLED);
#endif

#if defined(OSC_DISPLAY_R0) | defined(OSC_DISPLAY_R1)
 DisplayLink protocol = DisplayLink( new Module(SS, DIO0, LoRa_RST, LoRa_BUSY));
  Adafruit_PWMServoDriver pwm = Adafruit_PWMServoDriver(0x40, Wire);
  Adafruit_SSD1306 display(128, 64, &Wire, -1);
  #endif
  
#if defined(OSC_DISPLAY_R2)
  SPIClass spi(HSPI);
  SPISettings spiSettings(2000000, MSBFIRST, SPI_MODE0);
  DisplayLink protocol = DisplayLink(new Module(LoRa_NSS, DIO0, LoRa_RST, LoRa_BUSY, spi, spiSettings));
  Adafruit_PWMServoDriver pwm = Adafruit_PWMServoDriver(0x40, Wire);
  Adafruit_SSD1306 display(128, 64, &Wire, -1);
#endif

LEDs leds(pwm);
#if defined(WIFI_LoRa_32_V2) | defined(WIFI_LoRa_32_V3)
Horn horn(pwm);
#else if defined(OSC_DISPLAY_R0) | defined(OSC_DISPLAY_R1) | defined(OSC_DISPLAY_R2)
Horn horn(pwm, 15);
#endif

DisplayLogic displayLogic(horn, leds);

uint32_t lastTime=0;
uint16_t voltageRaw=0;
float voltage;

Preferences preferences;

String rssi = "RSSI --";
String packSize = "--";
String packet ;
String resetString = "restarting...reset your wifi connection";
String currentMode = "none";
unsigned long ms;
unsigned long lms;
unsigned long diff;
bool clientFlag = false;
long int currentTime = 0;
long int previousTime = 0;

int channel;
int default_channel = 1;
uint8_t syncword_select[5]={
  0x12,   //  not needed
  0x12,   //  Kanal 1
  0x23,   //  Kanal 2  
  0x34,   //  Kanal 3  
  0x45    //  Kanal 4
};
uint8_t syncword = syncword_select[default_channel];
float frequency_select[5]={
  433.0F,   //  not needed
  433.0F,   //  Kanal 1
  433.5F,   //  Kanal 2  
  434.0F,   //  Kanal 3  
  434.5F   //  Kanal 4
};
float frequency = frequency_select[default_channel];

MatchState matchState;


// Function Prototypes
void drawLoraInfo();
void drawRS485Info();
void setupRadio();

unsigned long ota_progress_millis = 0;

void onOTAStart() {
  // Log when OTA has started
  ESP_LOGI("OTA", "OTA update started!");
  // <Add your own code here>
}

void onOTAProgress(size_t current, size_t final) {
  // Log every 1 second
  if (millis() - ota_progress_millis > 1000) {
    ota_progress_millis = millis();
    ESP_LOGI("OTA", "OTA Progress Current: %u bytes, Final: %u bytes", current, final);
  }
}

void onOTAEnd(bool success) {
  // Log when OTA has finished
  if (success) {
    ESP_LOGI("OTA", "OTA update finished successfully!");
  } else {
    ESP_LOGI("OTA", "There was an error during OTA update!");
  }
  // <Add your own code here>
}

void initOTA()
{
  ElegantOTA.begin(&server);  // Start ElegantOTA
  ElegantOTA.onStart(onOTAStart);
  ElegantOTA.onProgress(onOTAProgress);
  ElegantOTA.onEnd(onOTAEnd);
  server.begin();
  ESP_LOGI("OTA", "HTTP server started");
}

void waitingDisplay(){
    display.clearDisplay();
    display.drawFastHLine(0, 50, 128, SSD1306_WHITE);  
    display.setFont(NULL);
    display.setTextSize(3);
    display.setCursor(2, 15);
    display.printf("waiting"),
    display.setTextSize(1);
    display.setCursor(30, 57);
    display.printf( "Channel %s (%s)", String(channel), currentMode);
    display.setCursor(0, 57);
    display.printf("NA");
    display.display();
}

void client_check(){
  ms = millis();
  diff = ms - lms;
  //lms = ms;
  if (diff >= 2100) {
    clientFlag = false;
    RS485mode = false;
    //leds.showWaitingAnimation();
    }
}

bool isMessageValid(String msg) {
  // Msg Format 1:
  // C0461
  // C: Command [A-Z]
  // 04: 2 numbers - time
  // 6: 1 number - brightness
  // 1: channel

  // Msg Format 2:
  // H51
  // H: Command [H,B]
  // 5: 1 number - honk volume
  // 1: channel

  // prepare matchstate
  int msgLength = msg.length();
  int bufferSize = msgLength + 1;
  char buffer[bufferSize];
  msg.toCharArray(buffer, bufferSize);
  matchState.Target(buffer);

  // check if channel is correct if not in cable mode
  if (!RS485mode && !msg.endsWith(String(channel))){
    return false;
  }

  // check if message matches valid patterns
  if ( msgLength == 3 ) {
    return matchState.Match("[HB][0-5][1-4]") == REGEXP_MATCHED;
  } else if ( msgLength == 5 ) {
    return matchState.Match("T[0-9][0-9][1-8][1-4]") == REGEXP_MATCHED;
  }
  return false;
}

/*void handlePacket(){
  if(!isMessageValid(packet)) {
    return;
  }
  String setTimeCommand = "T";
  String honkCommand = "H";
  if (packet.startsWith(setTimeCommand)){
    previousTime = currentTime;
    String currentTimeString = packet.substring(1,3);
    currentTime = currentTimeString.toInt();

    String brigthnessString = packet.substring(3,4);
    leds.setBrightnessLevel(brigthnessString.toInt());
    leds.displayClock(currentTime);
      
    display.clearDisplay();
    display.drawFastHLine(0, 50, 128, SSD1306_WHITE);
    display.setFont(&DSEG7_Classic_Mini_Regular_40);
    display.setCursor(32, 40);
    display.printf("%s", currentTimeString);
    display.setFont(NULL);
    display.setTextSize(1);
    display.setCursor(30, 57);
    display.printf( "Channel %s (%s)", String(channel), currentMode);
    display.setCursor(0, 57);
    display.printf("%2.0f", radio.getRSSI(true));
    ESP_LOGI("Handler","Received LoRa message: %s, RSSI: %2.0f", packet.c_str(), radio.getRSSI(true));
    display.display();
  } else if (packet.startsWith(honkCommand)){
    String honkVolumeLevelString = packet.substring(1,2);
    uint8_t honkVolumeLevel = honkVolumeLevelString.toInt();
    horn.requestHonk(honkVolumeLevel);
  }
}

void readLoraMessage() {
  int state = radio.readData(packet);
  if(state == RADIOLIB_ERR_NONE) {
    lms = millis();
    clientFlag = true;
    drawLoraInfo();
    handlePacket();
  } else {
    radio.reset();
    setupRadio();
  }
}*/
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

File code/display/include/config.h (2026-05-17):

#pragma once
#include "board_definitions.h"

/**************************************/ 
/********* user config ****************/
/**************************************/

// WiFi config
// Enter your SSID and PASSWORD
const char* ssid = "ShotClockDisplay";
// password must have at least 8 characters
const char* password = "12345678";

// PCB config 
// see board_definitions.h for available configs

//#define DISPLAY_PCB_VERSION V0_2
 #define DISPLAY_PCB_VERSION V0_2_HACK


/**************************************/ 
/********* auto config ****************/
/**************************************/

#define SCREEN_ADDRESS 0x3C

//Pin config

//RS-485
#if defined(WIFI_LoRa_32_V2)
    #define RXD2            13
    #define TXD2            14
    #define HELTEC_VERSION  2
    #define SCL             SCL_OLED
    #define SDA             SDA_OLED
    #define HORN_CH         7
    #define LoRa_RST        RST_LoRa
    #define LoRa_BUSY       BUSY_LoRa
    #define V_SENSE         -1
#endif

#if defined(WIFI_LoRa_32_V3)
    #define RXD2            6
    #define TXD2            5
    #define HELTEC_VERSION  3
    #define SCL             SCL_OLED
    #define SDA             SDA_OLED
    #define HORN_CH         7
    #define LoRa_RST        RST_LoRa
    #define LoRa_BUSY       BUSY_LoRa
    #define V_SENSE         -1
#endif


//I2C
#if DISPLAY_PCB_VERSION >= V0_2_HACK
    #ifdef WIFI_LoRa_32_V3
        static const uint8_t SDA_LED = 38;
        static const uint8_t SCL_LED = 39;
    #elif defined(WIFI_LoRa_32_V2)
        static const uint8_t SDA_LED = 33;
        static const uint8_t SCL_LED = 32;
    #endif
#endif

//Open Shot Clock Display R0
#if defined(OSC_DISPLAY_R0)
    #define RXD2        RX
    #define TXD2        TX
    #define UART_TXEN   46

    #define DIO0        18
    #define LoRa_RST    7 
    #define LoRa_BUSY   17
    #define LED         38
    #define LED_ERR     48
    #define FAN_PWM     3
    #define PWM_OE      47
    #define GPIO_X      4
    #define GPIO_Y      5
    #define GPIO_Z      6
    #define BTN1        15
    #define BTN2        16

    #define I_SENSE     1
    #define V_SENSE     2

    #define HORN_CH     15
#endif

//Open Shot Clock Display R1
#if defined(OSC_DISPLAY_R1)
    #define RXD2        RX
    #define TXD2        TX
    #define UART_TXEN   46

    #define DIO0        18
    #define LoRa_RST    7 
    #define LoRa_BUSY   17
    #define LED         38
    #define LED_ERR     48
    #define FAN_PWM     3
    #define PWM_OE      47
    #define GPIO_X      4
    #define GPIO_Y      5
    #define GPIO_Z      6
    #define BTN1        15
    #define BTN2        16

    #define I_SENSE     1
    #define V_SENSE     2
    #define V_GAIN (3.3f * 11.0f / 4096.0f)

    #define LED_STATUS  36
    #define PWR_GOOD    37

    #define HORN_CH     15
#endif

//Open Shot Clock Display R2
#if defined(OSC_DISPLAY_R2)
    #define RXD2        RX
    #define TXD2        TX
    #define UART_TXEN   46
    #define UART_RXEN   45

    #define DIO0        18
    #define LoRa_RST    37
    #define LoRa_BUSY   48
    #define LoRa_NSS    36
    #define LoRa_CLK    34
    #define LoRa_MISO   33
    #define LoRa_MOSI   35
    #define LED         38
    #define LED_ERR     39
    #define FAN_PWM     3       // FAN_PWM is not actually used in R2, but we need to define it for the code to compile
    #define PWM_OE      26
    #define GPIO_X      4
    #define GPIO_Y      5
    #define GPIO_Z      6
    #define BTN1        11
    #define BTN2        10

    #define I_SENSE     1
    #define V_SENSE     2
    #define V_GAIN (3.3f * 11.0f / 4096.0f)

    #define LED_STATUS  40
    #define PWR_GOOD    41

    #define HORN_CH     15      // HORN_CH is not actually used in R2, but we need to define it for the code to compile
#endif

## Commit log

2021-12-14 Initial base (#2)
    * initial commit
    * Ordner mit Temp_Monitor_Version hinzugefügt
    * sender aktualisiert - starte Bereinigung
    * Aufgeräumt-OTA-OLED_Display_Update-Kanal_Wahl_Web_Server-Temp_Sensor_raus
    * sender_OTA_und_Kanalwahl-Display_OLED_Design_und_Connecting_Funktion
    * Function_display-Display_aus_wenn_Smartphone_Steuerung
    * 3_sec_Press_Reset_with_Stop
    * Hardware_reset_Button_eingefügt
    * Display aus wenn Steuerung per Smartphone bug fix
    * port to VS code
    [main.cpp]
2022-01-21 Set tx power to 9 - test positiv (#4)
2022-02-09 updated sender button pin-out/wifi new controller
2022-02-14 save after fixing http error 500 on setting.html
    [main.cpp]
2022-06-03 corrected pin out discription reset and cancel
    [main.cpp]
2022-09-30 implement rs 485 communication (#22)
    * Initial base (#2)
    * updated_design_on_channel_selection_sender_and_receiver (#3)
    * Set tx power to 9 - test positiv (#4)
    * Feature/brightness control (#5)
    * added settings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
    [main.cpp]
2023-01-02 added pcb files
    [Junction_Case_Mark3 v1.step]
2023-01-02 refactores folder structure
    [Antenna_Bracket.3mf, Lower_Controller_Shell.3mf, Lower_Corner_Joint.3mf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]
2023-02-17 Add files via upload
    updated some costs and links
    changed ethernet socket product
    [Mark3_ Beschaffungsliste+Kosten_v1.0.xlsx]
2023-03-31 Add files via upload
    - updated images due to changes in cad design
    - changed naming from .svg to .pptx.svg
2023-03-31 Create README.md
    added design option 8 mm thick base plate
2023-03-31 Add files via upload
    added mark for 5 mm drilling hole (antenna)
2023-03-31 Add files via upload
    - added 8 mm base plate option flange design parts
    - updated tripod flange design to solve issue #23
    - added horn cuff clip to solve issue #23
    [Horn_Cuff_Clip.3mf, Tripod_Flang.3mf, Tripod_Flang_8mm_Base_Plate.3mf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]
2023-04-04 manually merged refactoring branch (issue 6)
    [config.h, main.cpp]
2023-04-05 updated cad and documentation files
    [Mark3_ Beschaffungsliste+Kosten_v1.0.xlsx, Mark3_ Beschaffungsliste+Kosten_v1.1.xlsx]
2023-04-05 added controller fusion file in cad folder
2023-04-06 updated sourcing-list and instructions
    [Mark3_ Beschaffungsliste+Kosten.xlsx, Mark3_ Beschaffungsliste+Kosten_v1.1.xlsx, Tripod_Cuff.3mf]
2023-04-06 Dev (#32)
    * manually merged refactoring branch (issue 6)
    * swithed webserver dependency to use HTTPS instead of SSH
    * swithed webserver dependency to use HTTPS instead of SSH
    * deleted assets folder and changed config
    * Update README.md
    changed theme image link to new assets branch
    * updated cad and documentation files
    * added controller fusion file in cad folder
    * updated sourcing-list and instructions
    ---------
    [Mark3_ Beschaffungsliste+Kosten.xlsx, Mark3_ Beschaffungsliste+Kosten_v1.0.xlsx, Tripod_Cuff.3mf]
2023-04-25 Update README.md
    - added video links for 2023 championships (men and woman)
    - added start times to all video links
    - added Acknowledgement to Ulf Bögeholz and a link to his tutorial shotclock.de
2024-05-17 Feature/test heltec v3 (#36)
    * initial test
    * switched to RadioLib to be able to use heltec v3. Added heltec_wifi_lora_32_V3 env. Added v3 pin configs. Still WIP
    * switched to RadioLib to be able to use heltec v3. Added heltec_wifi_lora_32_V3 env. Added v3 pin configs. For display. Still WIP
    * Added second Wire object, to make Heltec V3 I2C work. New Pins are necessary! (using default SDA=41,SCL=42)
    * added V3 infos to README
    * minor cleaning
    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
    [Lower_corner_joint_dewarp.3mf, Lower_corner_joint_dewarp.step, Upper_Corner_joint_dewarp.3mf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]
2024-05-22 fixed bug, brightnesslevel now using exact string position from message
    [config.h, main.cpp]
2024-05-30 fixed bug for RS485 communication (there is an extra whitespace sent, that crashed validation)
    [main.cpp]
2024-05-30 junction v1.1 PCB in kicad (#52)
    [RS485_junction.brd, RS485_junction.sch, junction.kicad_pcb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]
2024-05-30 added controller v2.1 in kicad (#53)
    [controller.brd, controller.kicad_pcb, controller.kicad_sch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]
2024-05-31 changed extra holes in junction to be THT to make them manufacturable
    [junction.kicad_pcb]
2024-06-13 fixed wrong pcb version error
    [config.h]
2024-06-27 ignore channel, when in cable mode
2024-08-08 fixed controller by updating lib_deps / added build_flag for async webserver async-mode / updated main for ElegantOTA
    [main.cpp]
2024-11-11 New integrated electronics for Open Shot Clock Display.
    This is WIP with PCA9535 for LED control.
    [7-Segment.kicad_sch, Communication.kicad_sch, Display.kicad_pcb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]
2024-11-17 Final Version of Prototype Rev. 00
    Switched back to PCA9685 for PWM, removed high side switch
    Updated some component values
    [7-Segment.kicad_sch, Communication.kicad_sch, Display.kicad_pcb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]
2024-12-09 add new controller and junction case, add looser horn cuff model
    [horn_cuff_looser.step, junction_case_v2.step]
2025-02-15 Marked known issues in schematic
    Add gitignore
    [7-Segment.kicad_sch, Display.kicad_sch, LED_Driver.kicad_sch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]
2025-02-15 Final Version of new Controller Rev. 00 (Prototype)
    [Communication.kicad_sch, Display.kicad_sch, Power_Supply.kicad_sch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]
2025-02-15 Add BOM files and adjust gitignore to not exclude BOMs
    [bom_display.csv]
2025-02-17 Added support for new custom display hardware
    Removed Heltec library
    Implemented OLED display using Adafruit library
    Increased RadioLib version as bugs for LLCC68 where fixed
    [config.h, main.cpp]
2025-02-20 Chore/refactor button handling (#55)
2025-02-20 fix missing 5V connection in controller PCB, when USB-C is not used, bump to v2.2
    [controller.kicad_pcb]
2025-02-20 Prepare release v1.2.0 (#56)
    - add heltec v3 compatibility
    - add version endpoint
    - add new controller PCB using kicad
    - update junction PCB using kicad
    - change lora communication, new channel system
    - cad updates, new controller, junction case, horn cuff, anti-warp corners
    - update elegantOTA
    - refactoring
    Commits:
    * updated sourci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
    [Lower_corner_joint_dewarp.3mf, Lower_corner_joint_dewarp.step, RS485_junction.brd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]
2025-03-30 Revision 01 of Controller hardware
    - fixed bugs from revision 00
    - changed folder structure
    - added ReleaseNotes_Controller.md to keep track of changes
    [Communication.kicad_sch, Display.kicad_sch, Power_Supply.kicad_sch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]
2025-04-08 Display HW Revision 01
    [7-Segment.kicad_sch, Communication.kicad_sch, Display.kicad_pcb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]
2025-04-09 Final adjustments and BOM optimization
    [Communication.kicad_sch, Display.kicad_sch, Power_Supply.kicad_sch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]
2025-04-11 Update some wrong values after import in JLC for production
    [7-Segment.kicad_sch, Communication.kicad_sch, Display.kicad_pcb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]
2025-04-11 Update wrong values after import in JLC for production
    [Communication.kicad_sch, Display.kicad_sch, Power_Supply.kicad_sch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]
2025-05-03 Update component values after feedback from JLC
    [Display.kicad_pcb, Display.kicad_sch]
2025-05-11 Updated ReleaseNotes_Controller.md with know issues of R01
    Changed SMD button JLC order number to version without mounting holes
    [Display.kicad_sch, controller.kicad_pcb, controller.kicad_sch]
2025-08-24 Feat/set 80 and 30 with buttons on controller (#58)
    * refactor: pin lib versions to fixed versions
    * feat: add toggleResetTime function on extra long press on BTN_3
    * refactor: remove debug prints from toggleResetTime function
    [main.cpp]
2025-08-24 Prepare release v1.3.0 (#59)
    * Feature/test heltec v3 (#36)
    * switched to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
    [main.cpp]
2025-09-06 update controller PCB: wider traces, fix missing trace on V+, add comments, update gerber files (#60)
    [controller.kicad_pcb, controller.kicad_sch]
2025-09-16 controller v3.0 cad design and print files added initially
    [Back Panel v3.0.3mf, Bumper v3.0.3mf, Case Bottom v3.0.3mf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]
2025-11-30 Conerted to KiCad 9 file version.
    [7-Segment.kicad_sch, Communication.kicad_sch, Display.kicad_pcb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]
2026-03-01 OSC Display Hardware Revision 02
    There might still be some errors which need to be corrected during ordering.
    [7-Segment.kicad_sch, Communication.kicad_sch, Display.kicad_pcb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]
2026-03-02 Adjusted footprint of mosfets for 0.15mm solder mask spacing
    New Gerber files
    [7-Segment.kicad_sch, Display.kicad_pcb, Display.kicad_sch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]
2026-03-10 Changed some Part# for production based on feedback an availability
    [Display.kicad_pcb, Display.kicad_sch, Open_Shot_Clock_Display-02_bom.csv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]
2026-03-10 Exclude Symbols from BOM
    [Display.kicad_sch]
2026-04-03 added R2 pin config
2026-04-03 init SPI corretly, fix PWM_OE pin, add debug logs
    [config.h, main.cpp]
2026-04-03 add pin setup for serial communication
2026-04-28 Feat/honk volume control (#61)
    * feat: add honk volume control and move honking logic to controller
    * feat: add honk volume control to settings and update server handling
    * feat: implement channel selection dropdown and update server handling for channel changes
    * style: update settings page design for improved aesthetics and usability
    * feat: add start time selection to settings and update server handling for start time changes
    * style: enhance settings page layout and improve button aesthetics and mobile use
    * feat: add time adjustment buttons for start time input in settings
    * fix: update volume and tick mappings for horn and LEDs for improved functionality
    * add fan grid with scr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
    [Fan_Grid_screw.step, fan_grid_seal.step, led_spacer.FCStd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]
2026-04-28 FIX: potential race condition with LoRa RX flag beeing reset after handling message.
    When a message is received during the processing of the last message, the flag will be reset before handling the new message.
    This depends on radio config and build settings.
    [main.cpp]
2026-05-07 Simplified config of R0 and R1 controller HW
    Added R1 to platformio.ini
    Add Button 3 long press to switch off Controller
    Removed unused tasks
2026-05-08 FIX: Button 4/5 were handled two times
    [main.cpp]
2026-05-10 Restructuring of Controller Code
    WIP
    - settingsProcessor simplified and integrated into ShotClockLogic
    - simplified button handling with new structure
    - formated webserver handlers
2026-05-10 Restructuring of Controller Code
    platformio.ini:
    - removed lib_deps to heltec dev-boards
    Moved display functions to ShotClockUI
    - integrated setDataDisplay, setPauseDisplay, honk
    - added new telemetry data UI with ID, Battery and RSSI
    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
2026-05-17 Implemented RSSI and Battery voltage in telemetry data
    Implemented basic ID assignment
    Add confirmed devices to list
    SCLink:
    - added getRSSI()
    - added priority flag to protocol_t to insert in front of list
    - added some more logic to the state machine
    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
2026-05-17 SCLink, ControllerLink, DisplayLink
    - use protocol_t for data transfer in functions
    - show ID after setID command
    ShotClockLogic:
    - fixed timings in pause mode
    - changed handling of telemetry command and response
    LEDs:
    - adjusted showSymbol() to show numbers for 0-9 and symbols for 10-17
2026-06-14 SCLink: - added parameter to drop this command when channel is busy (only used for discover atm) - fixed: insert priority command at pos 2 when other command is currently transmitted.
    config.h:
    - adjusted GAIN values for use with analogReadMilliVolts()
    - added battery voltage reading
    ShotClockUI:
    - added function to add discovered displays for telemetry
    - adjusted UI layout
    - integrated battery level of controller
    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
    [config.h, main.cpp]
